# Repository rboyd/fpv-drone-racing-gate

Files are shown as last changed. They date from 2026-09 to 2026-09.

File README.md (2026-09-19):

# FPV Drone Racing Gate

A modular FPV race gate built from **1-inch PVC, five types of PETG fittings, roll paper and magnets**. Print the fittings on a Bambu A1 Mini, cut two standard pipe lengths, and assemble a single gate or a two-level Split-S obstacle.

**Current design:** three-magnet top elbows with independent front/rear guy eyes and recessed paper alignment guides. **Prototype status:** the 33.5 mm magnetic sleeve bore has been physically tested on the purchased PVC and fits well. Full-gate assembly, friction-joint retention and guy loads still need physical validation.

## Choose a gate size

The original **1480.8 mm opening** now has **1000 mm and 800 mm alternatives**, each available with **24-, 18- or 12-inch paper bands**. All use the **same five printed part types and accepted 33.5 mm bores**. Only PVC lengths, paper cuts and sleeve quantities/positions change; previously printed fittings remain usable.

**Suggested next trial: 1000 mm opening with 12-inch paper.** It needs 32 printed parts, 1.883 kg PETG and about 74 hours of printing—half the original part count, 19% less PETG and 21% less printer time. Its outside square is 1609.6 mm. The imported 7-inch MK4 drone has about 299 mm centered clearance on each side; the 800 mm opening has about 199 mm. These are geometric clearances, not flight-error allowances.

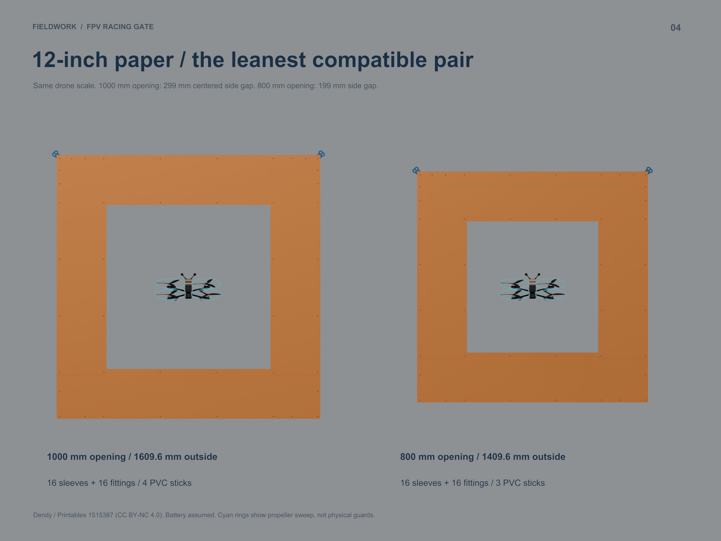
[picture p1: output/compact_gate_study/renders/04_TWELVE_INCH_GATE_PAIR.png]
1000 mm and 800 mm openings with 12-inch paper and the imported MK4 drone


| Clear square opening | Paper band | Outside square | All parts / sleeves | PETG | Estimated print time | 10-ft PVC sticks* | Priced subtotal* |
|---:|---:|---:|---:|---:|---:|---:|---:|
| 1000 mm | 24 in | 2219.2 mm | 48 / 32 | 2.104 kg | 84 h 20 min | 5 | $50.52 |
| 1000 mm | 18 in | 1914.4 mm | 40 / 24 | 1.993 kg | 79 h 18 min | 5 | $49.03 |
| 1000 mm | 12 in | 1609.6 mm | 32 / 16 | 1.883 kg | 74 h 21 min | 4 | $42.19 |
| 800 mm | 24 in | 2019.2 mm | 48 / 32 | 2.104 kg | 84 h 20 min | 5 | $50.52 |
| 800 mm | 18 in | 1714.4 mm | 40 / 24 | 1.993 kg | 79 h 18 min | 4 | $43.69 |
| 800 mm | 12 in | 1409.6 mm | 32 / 16 | 1.883 kg | 74 h 21 min | 3 | $36.85 |

*Compact-gate stock counts and subtotals above use the **ratcheting-cutter layouts**, with 10 mm cleanup reserve per stick and no saw kerf. Subtotals cover PETG consumed, magnets and whole PVC sticks at the owner's prices; paper, guys and ground supports are additional. The earlier compact study's cost table reserves 3 mm per cut for a saw, so its 1000 mm / 24-inch option uses six sticks and costs $5.34 more. Print figures are Bambu Studio estimates, not elapsed measurements.*

All compact gates retain **2 bottom elbows, 2 guy elbows, 8 tees and 4 crosses**. Their 24 / 18 / 12-inch paper layouts need **32 / 24 / 16 sleeves**, respectively. The smaller 800 mm opening uses the same print quantities at the study's maximum 350 mm magnet-gap target; paper retention at that spacing still needs physical testing. A 12-inch-paper gate fits nominally within two 1 kg spools, with about 117 g spare before failures.

- **Cut the PVC:** [printable seven-page cut guide](output/compact_gate_study/PVC_Cut_Guide.pdf), [cut tables and stick layouts](output/compact_gate_study/PVC_Cut_Guide.md), or [summary CSV](output/compact_gate_study/PVC_Cut_Summary.csv). Every compact gate needs eight long and sixteen short pieces. Listed lengths already include socket insertion.
- **See all six sizes:** [paper-on preview](output/compact_gate_study/renders/01_SIX_PAPER_LAYOUTS.png), [1000 mm frames with paper removed](output/compact_gate_study/renders/02_FRAME_1000.png), [800 mm frames](output/compact_gate_study/renders/03_FRAME_800.png), and [compact corner detail](output/compact_gate_study/renders/05_NARROW_CORNER_DETAIL.png).
- **Build a selected variant:** [full study, per-variant print queues, paper cuts and sleeve positions](output/compact_gate_study/README.md), [illustrated PDF](output/compact_gate_study/Compact_Gate_Study.pdf), or [Blender model](output/compact_gate_study/Compact_Gate_Study.blend).
- **Compare drone clearance:** [MK4 clearance study](output/drone_clearance_study/README.md) and [equal-scale opening comparison](output/drone_clearance_study/renders/04_OPENING_DETAIL.png). Drone reference: Dendy / Printables 1515387, CC BY-NC 4.0; battery dimensions assumed. See [attribution](reference/geprc_mk4/ATTRIBUTION.md).

## Original gate and stacked Split-S

The quantities and assembly tables below describe the original **1480.8 mm opening / 24-inch paper** configuration and its stacked version. Use the compact cut guide and print queue above for smaller gates. Compact stacked variants have not been laid out in this study.

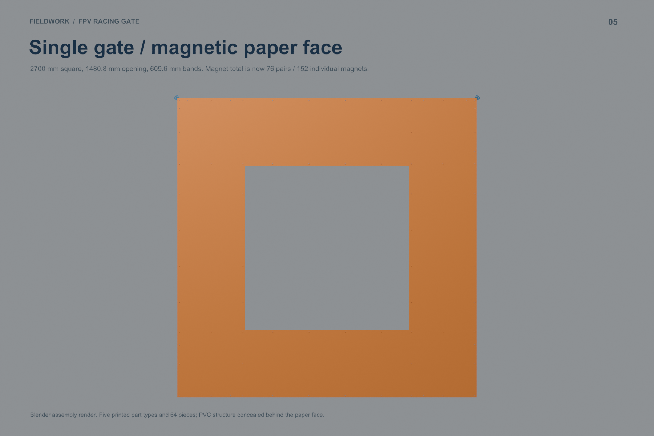
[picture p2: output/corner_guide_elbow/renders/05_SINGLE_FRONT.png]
Assembled single gate, front view rendered in Blender


*Blender assembly render—not a photograph of a completed build. Blue parts in the renders represent the black PETG used for printing. Ground anchoring and feet are not shown.*

| | Single gate | Stacked Split-S, total |
|---|---:|---:|
| Paper outline | 2700 × 2700 mm | 2700 × 4790.4 mm |
| Clear square opening | 1480.8 × 1480.8 mm | Two 1480.8 × 1480.8 mm openings |
| Paper band width | 609.6 mm / 24 in | 609.6 mm / 24 in |
| Printed parts / unique types | 64 / 5 | 104 / 5 |
| PETG, full batch queue | 2.325 kg | 3.691 kg |
| Estimated printer time | 94 h 28 min | 150 h 22 min |
| Plate runs on one A1 Mini | 23 | 36 |
| Priced materials: PETG + magnets + PVC | **$69.53** | **$117.29** |

Paper, guy lines and ground support are additional. Prices are the owner's approximate purchase costs, detailed below. The two guy ears extend about 28.6 mm beyond the adjacent paper edges.

## Files to start with

- [Compact gate material study](output/compact_gate_study/README.md): 1000 / 800 mm openings with 24 / 18 / 12-inch paper, fewer sleeves, exact print queues and material comparisons.
- [PVC cut guide for all six compact variants](output/compact_gate_study/PVC_Cut_Guide.pdf): finished lengths, quantities and stock layouts for the ratcheting cutter.
- [7-inch MK4 drone clearance study](output/drone_clearance_study/README.md): actual imported drone, Blender renders and 1480.8 / 1200 / 1000 / 800 mm opening comparisons. Smaller sizes are study variants; the production kit below retains the 1480.8 mm opening.
- [Current Blender model](output/corner_guide_elbow/Corner_Guide_Elbow.blend), including assembled gates, paper alignment, cord routing and the five-part overview.
- [Illustrated assembly and test PDF](output/corner_guide_elbow/Corner_Guide_Elbow.pdf) and [detailed current guide](output/corner_guide_elbow/README.md).
- [Printable STL parts](output/corner_guide_elbow/printable/) and [prepared A1 Mini PETG projects](output/corner_guide_elbow/sliced/).
- [Single-gate print queue](output/corner_guide_elbow/single_Print_Queue.csv), [PVC stock layout](output/corner_guide_elbow/single_PVC_Stock_Layout.csv), [paper cuts](output/corner_guide_elbow/single_Paper_Cuts.csv) and [magnet positions](output/corner_guide_elbow/single_Magnet_Positions.csv).
- [Stacked print queue](output/corner_guide_elbow/split_s_Print_Queue.csv) and [cost BOM](docs/Cost_BOM.csv).

Use **`output/corner_guide_elbow/`** for the shared fitting geometry and original gate, **`output/compact_gate_study/`** for the six smaller layouts, and **`output/drone_clearance_study/`** for drone size comparisons. Other output folders preserve earlier iterations; their quantities, interfaces and prices may differ.

## Five printed parts

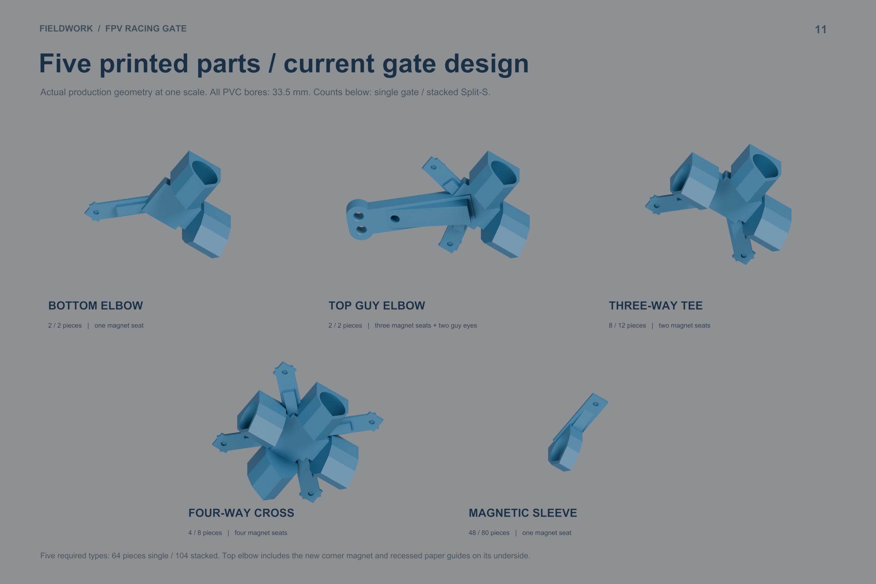
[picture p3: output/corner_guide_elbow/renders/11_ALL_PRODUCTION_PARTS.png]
Bottom elbow, top guy elbow, tee, cross and sleeve at the same scale


| Part / STL | Single qty | Stacked total qty | PETG per individual print | Individual print time | PETG cost per individual print |
|---|---:|---:|---:|---:|---:|
| [Bottom elbow](output/corner_guide_elbow/printable/ELBOW.stl) | 2 | 2 | 68.47 g | 2 h 41 min | $0.68 |
| [Top guy elbow](output/corner_guide_elbow/printable/DUAL_GUY_ELBOW.stl) | 2 | 2 | 103.06 g | 4 h 00 min | $1.02 |
| [Three-way tee](output/corner_guide_elbow/printable/TEE.stl) | 8 | 12 | 98.49 g | 3 h 46 min | $0.97 |
| [Four-way cross](output/corner_guide_elbow/printable/CROSS.stl) | 4 | 8 | 132.59 g | 5 h 04 min | $1.31 |
| [Magnetic sleeve](output/corner_guide_elbow/printable/MAG_SLEEVE.stl) | 48 | 80 | 13.88 g | 1 h 12 min | $0.14 |

Individual print estimates include each plate's overhead. The full-gate totals use **seven-sleeve batches**, which are substantially faster than printing sleeves one at a time. Values come from local Bambu Studio slices, not elapsed measurements of completed prints. Full queues start from zero; subtract parts already printed.

The bottom elbow, tee, cross and sleeve are unchanged from the accepted-bore iteration. All sockets use **33.5 mm bores** for the project's nominal 1-inch PVC (modeled OD 33.4 mm). Elbows, tees and crosses have 30 mm pipe engagement; the sleeve has 16 mm engagement. Friction retains the joints—no bolts, nuts or zip ties in this frame.

The top elbow adds two separate 10.5 mm eyes for front and rear guys, three 6 × 2 mm magnet seats, and an L-shaped paper guide recessed 0.4 mm into the face. The magnet pockets retain 0.4 mm plastic skins. Bare front magnets clamp the paper against those skins; front paper pads are optional and excluded from the required BOM.

## Material BOM and costs

These are **prices paid by the project owner**, not current store quotes or product recommendations. Exact brands/listings were not supplied.

| Material purchased | Pack price | Unit rate used |
|---|---:|---:|
| Black PETG, four 1 kg spools | $39.59 / 4 kg | $9.8975 / kg |
| Neodymium magnets, 6 mm diameter × 2 mm thick | $19.99 / 800 | $0.0249875 / magnet |
| Nominal 1-inch PVC, 10 ft / 3048 mm stick | $5.34 each | $5.34 / stick |

| Material | Single quantity | Single cost | Stacked total quantity | Stacked cost |
|---|---:|---:|---:|---:|
| PETG consumed by supplied queue | 2.32471 kg | $23.01 | 3.69130 kg | $36.53 |
| Magnets, including both sides of paper | 152 / 76 pairs | $3.80 | 240 / 120 pairs | $6.00 |
| PVC stock, including cutting waste | 8 sticks | $42.72 | 14 sticks | $74.76 |
| **Priced material subtotal** | | **$69.53** | | **$117.29** |
| 24-inch paper roll | 8.5056 m used | Unpriced | 14.3112 m used | Unpriced |
| Front/rear guys and suitable ground support | 4 guys + supports | Unpriced | 4 guys + supports | Unpriced |

These subtotals allocate only the filament and magnets used, plus all PVC sticks purchased. Starting from no supplies, buying **one 4 kg filament pack + one 800-magnet pack + the PVC** costs **$102.30 single / $134.34 stacked**, leaving filament, magnets and pipe offcuts. The stacked queue fits nominally within 4 kg, with about 309 g spare before failed prints or other additions. Tax, shipping, adhesive, electricity, optional pads, tools, failed prints, paper and ground support are excluded.

Machine-readable inputs: [material_costs.json](docs/material_costs.json). [Cost_BOM.csv](docs/Cost_BOM.csv) contains the calculated line items. Older guides retain their historical pricing assumptions.

## A1 Mini printing

Prepared projects use the **180 × 180 × 180 mm A1 Mini**, a 0.4 mm nozzle, 0.20 mm layers, four walls, 20% infill, Generic PETG, a textured PEI plate and no supports. All supplied plate layouts have at least 5 mm bed margin. The largest fitting is the top guy elbow at **168.614 × 168.614 × 53.345 mm**. Retain the supplied orientations; the socket roofs are shaped for support-free printing.

For a new printer/pipe combination, start with [one magnetic sleeve](output/corner_guide_elbow/sliced/ONE_MAG_SLEEVE/ONE_MAG_SLEEVE_A1Mini_PETG.3mf), then test [one tee](output/corner_guide_elbow/sliced/ONE_TEE/ONE_TEE_A1Mini_PETG.3mf) and [one top guy elbow](output/corner_guide_elbow/sliced/ONE_DUAL_GUY_ELBOW/ONE_DUAL_GUY_ELBOW_A1Mini_PETG.3mf). The project owner's sleeve fit is confirmed; it does not establish the longer sockets' fit on every pipe brand.

| Prepared plate | Parts / run | Single runs | Stacked total runs | PETG / run | Time / run |
|---|---:|---:|---:|---:|---:|
| [ONE_ELBOW](output/corner_guide_elbow/sliced/ONE_ELBOW/ONE_ELBOW_A1Mini_PETG.3mf) | 1 | 2 | 2 | 68.47 g | 2 h 41 min |
| [ONE_TEE](output/corner_guide_elbow/sliced/ONE_TEE/ONE_TEE_A1Mini_PETG.3mf) | 1 | 8 | 12 | 98.49 g | 3 h 46 min |
| [ONE_CROSS](output/corner_guide_elbow/sliced/ONE_CROSS/ONE_CROSS_A1Mini_PETG.3mf) | 1 | 4 | 8 | 132.59 g | 5 h 04 min |
| [ONE_DUAL_GUY_ELBOW](output/corner_guide_elbow/sliced/ONE_DUAL_GUY_ELBOW/ONE_DUAL_GUY_ELBOW_A1Mini_PETG.3mf) | 1 | 2 | 2 | 103.06 g | 4 h 00 min |
| [BATCH_MAG_SLEEVE](output/corner_guide_elbow/sliced/BATCH_MAG_SLEEVE/BATCH_MAG_SLEEVE_A1Mini_PETG.3mf) | 7 | 6 | 11 | 96.74 g | 4 h 28 min |
| [TAIL_MAG_SLEEVE_6](output/corner_guide_elbow/sliced/TAIL_MAG_SLEEVE_6/TAIL_MAG_SLEEVE_6_A1Mini_PETG.3mf) | 6 | 1 | 0 | 82.93 g | 3 h 51 min |
| [TAIL_MAG_SLEEVE_3](output/corner_guide_elbow/sliced/TAIL_MAG_SLEEVE_3/TAIL_MAG_SLEEVE_3_A1Mini_PETG.3mf) | 3 | 0 | 1 | 41.50 g | 2 h 04 min |

The single queue is about **94.5 printer-hours**, and the stacked queue about **150.4 printer-hours**, before plate changes, setup and downtime. Slicer estimates depend on the selected machine, filament and process settings.

## PVC cuts and assembly

| PVC cut length | Single qty | Stacked total qty |
|---|---:|---:|
| 389.6 mm | 16 | 24 |
| 1560.8 mm | 8 | 14 |

The [single](output/corner_guide_elbow/single_PVC_Stock_Layout.csv) and [stacked](output/corner_guide_elbow/split_s_PVC_Stock_Layout.csv) stock layouts reserve 3 mm per cut and 10 mm per stick for trimming. The workshop cutter is a **Husky 1-1/4-inch ratcheting PVC cutter**; hand-saw cuts are also accommodated by the allowance. Mark and verify one master piece of each length before using it for repeated marking. Square and deburr the cuts; mark 30 mm socket insertion depth.

1. Slide the magnetic sleeves onto each pipe **before** inserting both pipe ends into fittings. Use the [sleeve-position CSV](output/corner_guide_elbow/single_Sleeve_Positions.csv) to set their positions and clock the magnet faces into the paper plane.
2. Build horizontal rows with four fittings and short / long / short pipes. The bottom corners use plain elbows; top corners use guy elbows; perimeter junctions use tees; interior junctions use crosses. The [assembly map](output/corner_guide_elbow/single_Assembly_Map.svg) and [node list](output/corner_guide_elbow/single_Nodes.csv) identify every location and rotation.
3. Join the rows with vertical pipes while working flat. Seat the sockets to the witness marks and check equal diagonals and coplanarity.
4. Install backing magnets at the listed paper attachment positions, checking polarity before bonding. Some tee/cross pockets are unused in a given orientation; **populate the magnet-position list, not every physical pocket**.
5. Cut 24-inch-wide paper into two 2700 mm horizontal bands and two 1552.8 mm side inserts for the single gate. Side inserts overlap the horizontal bands by 36 mm at each end. The stacked version uses three horizontal bands and four side inserts. A 100-ft roll yields three singles or two stacked paper sets, before spoilage.
6. At each top elbow, align the paper edges with the **centerlines** of the recessed L. Place the corner magnet first, then the top/side magnets and remaining edge magnets. Paper is held as rear magnet → plastic skin → paper → front magnet.
7. Attach separate front and rear guys at each upper corner. Fit and test suitable stakes for soil or ballast/base supports for hard surfaces before flight. The current frame kit does not specify a complete footing or anchor design, and no wind/load rating is assigned. Paper is a replaceable face; wet-weather durability has not been established.

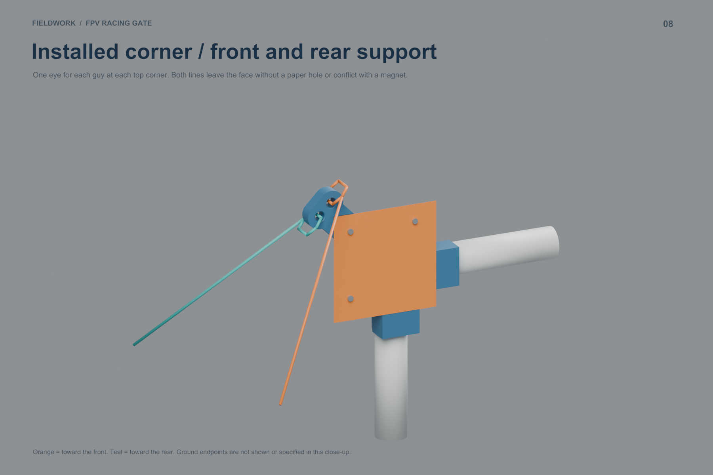
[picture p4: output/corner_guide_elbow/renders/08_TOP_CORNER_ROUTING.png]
Top corner with three magnets and separate front/rear guy attachments


## Extend to a two-level Split-S

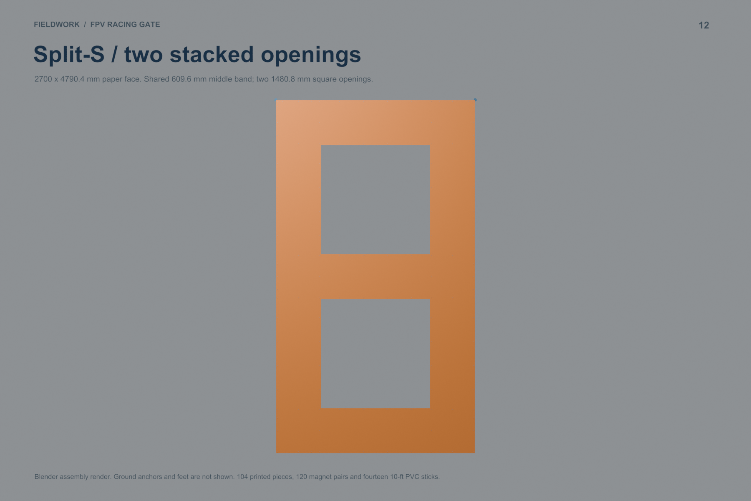
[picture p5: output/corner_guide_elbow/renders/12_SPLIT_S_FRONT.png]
Assembled two-level Split-S paper face rendered in Blender


Move the complete top row upward, reusing its guy elbows, tees, sleeves and magnets. Add **4 tees, 4 crosses, 32 sleeves, 8 short pipes, 6 long pipes and 44 magnet pairs**. The added PVC fits six more 10-ft sticks. Add one horizontal paper band and two side inserts. All existing gate parts and pipe cuts are reused; stacked totals above include the original gate.

The finished paper outline is **2.70 m wide × 4.7904 m tall**, before any feet. This is a tall obstacle, and its supports must be tested for the actual installation.

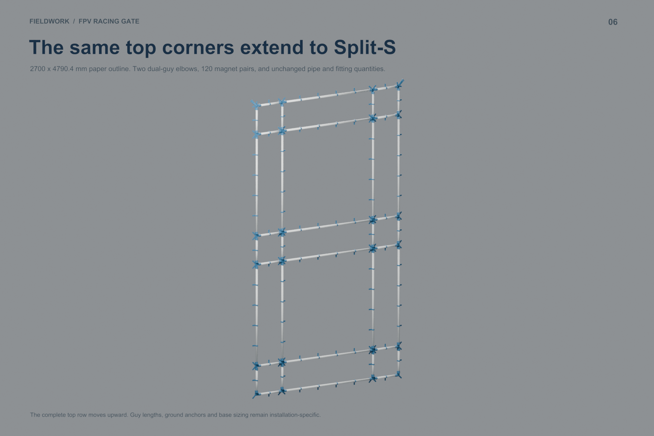
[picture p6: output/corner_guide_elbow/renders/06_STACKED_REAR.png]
Rear PVC structure of the stacked gate


## What is verified

- Actual printed magnetic sleeve: good friction fit on the purchased PVC at a 33.5 mm design bore.
- Digital geometry: connected manifold STL meshes, A1 Mini bounds and plate clearances, aligned magnet pockets, paper-guide depth, cord routing clearance and matching PVC ports.
- Slicing: every supplied recipe generates with supports off and no slicer warnings.
- Assembly accounting: part counts, full print queues, pipe stock nesting, paper positions and reuse when extending to Split-S.

Physical elbow/tee/cross fit, magnet retention, full-frame stiffness, guy-eye strength and outdoor performance remain prototype tests. The images are CAD renders of the current design.

## Rebuild and repository layout

The checked-in Blender scenes, STLs, 3MF projects, PDFs and CSVs are ready to inspect. Geometry is authored in millimetres and converted to metres in Blender; exported STLs/3MFs use millimetres.

```sh
# Blender 5.0.1 was used locally; --no-render builds geometry and scenes only.
blender -b -t 8 --python scripts/build_corner_guide_elbow.py -- --no-render

# Slice with the locally installed Bambu Studio and its A1 Mini presets.
python3 scripts/slice_corner_guide_elbow.py
python3 scripts/validate_corner_guide_elbow.py

# Render the full scene set (omit --no-render).
blender -b -t 8 --python scripts/build_corner_guide_elbow.py

# Documentation packaging requires ReportLab.
python3 -m pip install reportlab
python3 scripts/package_corner_guide_elbow.py
python3 scripts/publish_project_docs.py
```

Scripts currently target **macOS**: the Blender helpers use system Arial fonts and the slicer wrapper uses `/Applications/BambuStudio.app`. Adapt those paths for other operating systems. `RENDER_SCENES` can restrict rendering to a comma-separated scene list. PDFs embed rendered images, so render before packaging.

- `output/corner_guide_elbow/`: current gate, five production types and print queues.
- `output/compact_gate_study/`: six smaller layouts, PVC cut guide, partial sleeve batches and previews.
- `output/drone_clearance_study/`: imported MK4 drone, opening comparisons and Blender crossing animation.
- `scripts/`: reproducible geometry, slicing, validation and packaging.
- `docs/`: current material prices and cost ledger.
- [DESIGN_HISTORY.md](DESIGN_HISTORY.md): earlier Coroplast, posterboard, click-track and PVC iterations.
- `reference/` and `WIP-design.md`: design references; they are not current fabrication instructions.

Generated loose G-code, logs, Blender backup files and duplicate kit ZIPs are excluded from Git. Sliced 3MF projects are included; the packaging script can regenerate the current ZIP locally.

## License

**Designs and documentation: [CC BY-NC-SA 4.0](LICENSE).** Share and modify for noncommercial purposes, give attribution, identify changes and keep shared adaptations under the same license or a compatible license permitted by its terms. Commercial use of protected project material requires separate permission from [Robert Boyd (@rboyd)](https://github.com/rboyd).

**Original Python scripts: [PolyForm Noncommercial 1.0.0](scripts/LICENSE).** Use, modification and sharing are allowed for its permitted purposes; retain the [required notices](scripts/NOTICE). Generated design assets keep their separate CC license.

Ownership is retained, and separate commercial licenses may be granted. Existing compliant CC permissions cannot be revoked. See [LICENSING.md](LICENSING.md) for exact scope, retained rights, commercial requests and the limits of protection for functional designs.

The archived Tony Youngblood picture-frame reference retains **CC BY-SA 4.0**, including its commercial permissions; see [attribution](reference/picture_frame/ATTRIBUTION.md). The imported Dendy / Printables MK4 drone reference retains **CC BY-NC 4.0**, with the original frame authorship qualification; see [drone attribution](reference/geprc_mk4/ATTRIBUTION.md). Fonts, presets and other third-party content retain their own terms. The project's noncommercial licenses do not relicense those components.

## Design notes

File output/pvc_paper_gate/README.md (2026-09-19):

# PVC-dominant paper gate / single and Split-S

The previous reinforced print-track design and first click-test plate were committed as **eda5b20**. This new iteration replaces the printed track with **one outer PVC perimeter and one PVC ring around each opening**, joined by four diagonal PVC spokes at the overall corners. All pipe is nominal 1-inch PVC (33.4 mm OD). Paper hides the structure head-on; only paper and bare front magnets are visible in the face area.

[Blender model](PVC_Paper_Gate.blend) · [Visual design/assembly PDF](PVC_Gate_Study.pdf) · [Rendered single gate](renders/01_SINGLE_FRONT.png) · [Rendered Split-S](renders/03_SPLIT_S_FRONT.png) · [Rear structure](renders/04_SPLIT_S_BACK.png) · [Kit](PVC_Paper_Gate_Kit.zip)

## Recommendation and measured cost

Use the **stack-ready single** as the development baseline: **62 printed pieces in five types, 1.759 kg PETG, 71.0 print-hours, 16 plate runs, and six 10-ft PVC lengths at your $6 price**. The longest cut pipe is 1990.4 mm, retaining the approximately 2.15 m transport limit. Short members disconnect at cord-retained sockets.

| Configuration | Printed pieces | PETG | Print time | PVC sticks / cost | PVC + PETG subtotal* |
|---|---:|---:|---:|---:|---:|
| Basic single; 2.5 m pipes | 64 | 1.370 kg | 56.6 h | 7 / $42 | $69.40 |
| Recommended single; ready to extend | 62 | 1.759 kg | 71.0 h | 6 / $36 | $71.17 |
| Two-level Split-S | 108 | 2.814 kg | 114.5 h | 10 / $60 | $116.27 |

*PETG cost assumes $20/kg, not a current supplier quote. Estimates are actual local A1 Mini slices: 0.4 mm nozzle, 0.20 mm layers, four walls, 20% infill, Generic PETG, supports off. The subtotal covers the **face skeleton only**. Add magnets, paper, cord, adhesive, base/feet, ground stakes or ballast, and external guys. It is not a complete installed-obstacle price. Manual work, failures and reprints are excluded from printer-hours.

Two full 1 kg spools cover the recommended single with 10% allowance (1.935 kg). The Split-S uses 2.814 kg before allowance: three spools nominally, four if budgeting 10% extra. Optional front pads add material and time; they are excluded from these totals.

For a fair printed-face comparison, the prior sleeve design excluding optional pads and PVC-brace clamps used 6.132 kg / 252.4 hours. The new recommended single reduces that PETG by 71.3% and print time by 71.9%. The tradeoff is more PVC and cord work. The no-transport-joints basic option prints less, but needs seven sticks due to offcuts and has 2500 mm pipe pieces. The recommended version costs only $1.77 more in the modeled materials.

## Five printed types

| Part | Single ready | Split-S total | A1 Mini print bounds mm |
|---|---:|---:|---|
| OUTER_90_45 | 4 | 4 | 122.0 x 122.0 x 53.84 |
| STACK_TEE | 4 | 10 | 160.0 x 122.0 x 53.84 |
| EDGE_SLEEVE | 42 | 74 | 20.0 x 62.3 x 52.709 |
| INNER_90_45 | 4 | 4 | 151.489 x 151.488 x 53.84 |
| CORD_SADDLE | 8 | 16 | 34.0 x 20.0 x 12.0 |

**OUTER_90_45** combines two perpendicular sockets and an inward diagonal socket. **INNER_90_45** has the same perpendicular sockets but its diagonal points outward, away from the opening. They cannot be the same rotated part. Each has an integral magnet pocket, broad 32 x 12 mm connecting webs, raised cord eyes, and a two-horn cord cleat. Socket walls are nominally 4 mm, with 30 mm pipe engagement to a positive end stop.

**STACK_TEE** is used in all ten tee locations of the stacked gate: eight divider junctions and two transport joints. It has four available magnet pads so the same part can rotate to either side; populate only the pockets listed in the magnet map. Its unused branch port at a transport joint stays empty and concealed behind paper. The single version includes four tees: two side riser tees for the future divider and two horizontal transport tees.

**EDGE_SLEEVE** slides over bare PVC before fitting the ends. Its 3.2 mm nominal wall and 14 mm axial length support a magnetic pad offset 32 mm from the pipe axis. Use the raised cord eye to set rotation and the indexed cord/stop knots to set position. It is a clearance sleeve, not a friction clamp. **CORD_SADDLE** is a small magnet backing threaded on a seam cord; two span each short paper overlap without an extra PVC member.

Every production part is a connected, manifold mesh and fits inside the A1 Mini's 180 mm cube with the supplied placement margin. Maximum part extent is 160 mm. The pipe axes are only **24 mm behind the paper**, reducing solid material below the sockets. Accepted peaked roofs remain. The magnet pocket remains **6.3 mm diameter with 0.4 mm of plastic between rear magnet and paper**; it is not a flush/open frame-side holder.

## Paper face and magnet alignment

Outside dimensions remain **2700 x 2700 mm** for one opening, or **2700 x 4790.4 mm** for two. Each clear paper opening is **1480.8 x 1480.8 mm**. The shared divider is one 609.6 mm band, not two overlapping full bands. With the illustrative 50 mm ground clearance, the Split-S top is 4840.4 mm above ground.

Use the full 609.6 mm roll width throughout. This iteration changes the pinwheel cutting pattern to simpler horizontal bars and side inserts that also work at the shared divider:

- Single: **two 2700 mm cuts and two 1552.8 mm cuts**. The side inserts overlap the horizontal bands by 36 mm at both ends. Total roll consumption 8.5056 m; three single gates fit on a 100-ft roll.
- Split-S: **three 2700 mm cuts and four 1552.8 mm cuts**. Total 14.3112 m; two stacked gates fit on a 100-ft roll.

The outer PVC axes are 50 mm inside the paper outline. The inner axes sit 50 mm behind the opening boundary in plan. A 32 mm pad offset puts magnets **18 mm inside the paper edges**, and the overlap seam centers are also 18 mm from the side-insert cut ends. No pipe or printed fitting protrudes into the opening or beyond the face in the checked front projection. This is a head-on appearance goal; supports may be visible from oblique/rear views, and paper can deflect in wind.

Use **124 magnets for the single, 216 for the Split-S**, all 6 x 2 mm, paired front/back. Start with the spacing shown (roughly 300-350 mm on long edges); it is a prototype spacing, not established wind retention. The smaller count than the printed-rail design needs physical paper/grip testing.

Bond the rear magnets with compatible adhesive after checking polarity. Stack without optional pads: **rear magnet -> 0.4 mm printed skin -> paper -> bare front magnet**. Optional PAPER_PAD adds its own 0.4 mm skin and a handle around the front magnet. It is a test/comfort option, not required for the paper-only front appearance. No new front pad design is needed.

For accurate placement, use Sleeve_Positions.csv to mark the PVC, rotate each sleeve until its paper face is coplanar with the corner pads, and lock that position on the prethreaded cord with stopper knots on both sides of its eye. Set the paper edge 18 mm beyond the magnet centers. Attach loose front magnets directly over the fixed rear magnets; they self-align. Do not perforate the paper. The Paper_and_Magnet_Map.svg and Magnet_Positions.csv provide the exact layout; the SVG shows magnets at true scale.

## Cord assembly and retention

Use the previously selected **2.4 mm 275 paracord**. Socket draw lines run from fitting to fitting along each PVC member, through the relevant sleeve eyes on straight members. Keep the line on the paper-edge side of the pipe foot, clear of the socket mouth. They pull the fittings against the pipe end stops; bare dry-fit friction is not treated as retention. Wrap diagonal draw cords **over the backs of the socket shells**, then finish on the central cleats, so they do not pass through a solid socket root.

Tie one fixed end, feed slack through the guides, hold the final tail, and pull only enough to seat both pipe ends. Make two figure-eight wraps around the receiving two-horn cleat and finish with a locking half-hitch. Leave a 100 mm tail. To release, hold the tail, undo the hitch and unwrap. Do not tension until PVC bows. Use separate lines for the seam backers and X braces so replacing paper does not loosen pipe joints. The X cords stay inside the side paper bands and never cross an opening.

The supplied centerline drawings show principal routes and raised eye locations; knots, contact bends around the sockets, and every turn through an eye are not simulated. Prototype the routing and hand access before repeating it. The cord scheme has not been load tested. Printed sleeve rotation, cord stretch and knot slip remain physical-test items. Mark socket insertion depth, sleeve position and cord tail after the first successful fit-up; leave sleeves and their locating cords on the pipes in transport.

Cord_Cuts.csv includes generous tie allowances: **38.7 m for the single face, 67.2 m for the stacked face**. External guys are additional. These are cut allowances, not a reason to tension hard. Recheck slack after settling and warm exposure.

## Single gate assembly

1. Print the FIRST_FIT plate and test the actual pipe first. Once it passes, print one INNER_90_45 and one STACK_TEE before committing to the full queue. Neither is included in FIRST_FIT.
2. Cut and label PVC from the stock layout. The six-stick single layout reserves 10 mm per stock end allowance and 3 mm kerf per cut, but several sticks have only about 8.3 mm remaining after those allowances. Measure actual stock and kerf before cutting; do not round all cuts upward. Cuts use **center spacing minus 100 mm** because every fitting's pipe stop is 50 mm from its node center.
3. Slide the indicated EDGE_SLEEVEs onto each labeled bare pipe. Use Sleeve_Positions.csv, measured from the cut start named in PVC_Cuts.csv. Thread the locating cords before fitting the pipe ends. Keep every flat paper face in the same plane.
4. Assemble the outer ring on a flat surface. The top and bottom each use two 1200 mm pipes and one tee transport joint. Each side uses a 1990.4 mm pipe, a tee and a 409.6 mm pipe. The tee's spare port points inward. Outer corner-to-corner pipe-axis spacing is 2600 mm.
5. Assemble the inner square from four 1480.8 mm pipes. Its pipe-axis spacing is 1580.8 mm. Connect corresponding corners with four 620.683 mm diagonal pipes. Lay all corners in the orientations shown in Blender before inserting the diagonals.
6. Seat all pipes 30 mm into their sockets. Tension the socket draw cords gradually, check squareness, then set the side-band X cords. Fit the seam cords and slide on two CORD_SADDLEs per seam. Fix their marked positions with small stopper knots.
7. Install rear magnets and allow adhesive to cure. Lay on the two horizontal paper bands, then the side inserts with their 36 mm overlaps. Work from corners along each edge, adding front magnets directly over the rear pockets. Confirm only paper and magnets show from the front.
8. Test retention and handling flat, then install a suitable base and anchoring system before standing the gate. Do not lift or carry the assembly by paper or magnetic pads.

## Upgrade to a two-level Split-S

The digital cut ledger confirms **every existing pipe length is reused without cutting**. Add **six STACK_TEEs, 32 EDGE_SLEEVEs and eight CORD_SADDLEs**. Add PVC cuts: **two 1990.4 mm, four 1480.8 mm and four 409.6 mm**. Those additions fit four more 10-ft sticks, bringing the total to ten. Add 92 magnets, additional cord, one 2700 mm paper band and two 1552.8 mm side inserts.

With the single gate lying flat, remove its paper and slacken the draw cords. Move the entire outer top bar (including its middle tee), its two outer corner fittings, the inner top corner fittings and the two top diagonal pipes to their new top positions. Keep the original inner top 1480.8 mm pipe as the lower divider-opening rail, replacing its two corner fittings with tees. The old upper outer corners become new tees at the upper divider height. The preinstalled side tees form the lower divider junctions.

Connect each divider rail outward to the side uprights with two 409.6 mm stubs. Retain the original two short side risers between the divider's outer tees. Add the upper outer risers, the upper opening's two inner uprights, and its bottom/top horizontal rails. Check the two divider axis heights: **2140.4 and 2650 mm measured from the paper bottom**, a 509.6 mm spacing. This leaves room for the one 609.6 mm paper divider while the sleeves place magnets at its two opening edges.

Re-thread and tension with the assembly flat; then add the additional paper and magnets. The shared middle uses straight tee connections, so there are no crossing in-plane PVC diagonals. The extra tee ports and aligned pipe stops are what make this a reusable extension system rather than two independent square gates stacked into each other.

## First print and acceptance checks

[Open FIRST_FIT_A1Mini_PETG.3mf](sliced/FIRST_FIT/FIRST_FIT_A1Mini_PETG.3mf): **124.59 g, 4.95 hours**, five pieces: one outer 90+45 corner, one edge sleeve, one cord saddle, one short bore gauge, and one optional front pad. It demonstrates the new PVC socket, magnetic face and cord interface; the earlier click-test plate remains available in the committed iteration.

Use actual clean 33.4 mm OD PVC offcuts, a short paracord length, paper and four magnets for two grip sites. Check the gauge first, then full 30 mm socket seating without force; a short gauge does not prove the full socket fit. Check extraction after relaxing cord, loop clocking, knots, cord access around the 45-degree socket and coplanar magnet faces. Test bare front magnet vs optional pad, then repeat assembly at least 20 times. Check whitening, cracks, looseness, pipe withdrawal and permanent deformation. Scale must stay 100%; revise the bore clearance itself if necessary.

All seven exported masters (five production types, a gauge and an optional pad) are connected/manifold and within A1 Mini bounds. All supplied recipes have 5 mm minimum bed margin, no part overlap, no supports and no slicer warnings. Quantities match the modeled parts, magnet positions match real pockets, and sleeves sit on exposed pipe rather than over a fitting. These are digital checks, not physical strength or fatigue certification.

## Base and outdoor limits

The new face skeleton is a **fabrication prototype and assembly study**, not a wind-qualified complete obstacle. Scene 10 shows the required concept of separate feet/ballast and four external guys; the bag sizes and feet are placeholders and are **not** a ballast prescription. For soil use suitable anchored guys/feet; hard surfaces require attached ballast/feet sized for the actual setup. The 4.79 m face is much taller than the single version, so do not reuse the old single-gate ballast amount as an assumed rating. Keep anchors/guys outside the openings, attach them around structural PVC near nodes, and assemble/raise with helpers.

Ground hardware is deliberately excluded from the face cost/queue. Its sizing and attachment are the next engineering step after the corner/cord prototype works. Paper weather resistance, 6 mm magnet pull through the plastic skin, sleeve clocking and cord preload also remain to be proven in real conditions. A paper face at this size can catch wind even if the PVC joints are rigid.

## Sources and assumptions

- [FORMUFIT PVC sizing](https://formufit.com/pages/pvc-101): nominal 1-inch PVC is approximately 1.315 inch OD. The CAD uses 33.4 mm and a 34.2 mm trial bore; measure your pipe rather than treating that clearance as universal.
- [FORMUFIT assembly guidance](https://formufit.com/pages/building-projects-with-pvc-pipe): dry friction joints are a temporary assembly method, not adequate justification for a loaded structure. Our removable cord retention is an original prototype proposal and is not endorsed or validated by that guidance. PVC solvent cement is not assumed to bond PETG.
- [Prusa modeling guidance](https://help.prusa3d.com/article/modeling-with-3d-printing-in-mind_164135): supports/overhangs and tolerances depend on geometry and settings. Peaked bores were also checked by slicing with supports off; successful real printing is still to be tested.

Your PVC price is used as given. No MultiGP compliance or official course dimensions are claimed; the approved dimensions and reference image determine this concept. Rebuild with build_pvc_paper_gate.py, slice_pvc_paper_gate.py, validate_pvc_paper_gate.py and package_pvc_paper_gate.py. No printer job has been submitted.

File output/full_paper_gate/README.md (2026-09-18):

# Reinforced paper gate — full design and fabrication prototype

The old demo was committed as `bb96e74`. This iteration replaces its weak perpendicular socket, retains the shared click key, adds integrated paracord cleats, and carries actual printable parts through to a complete PVC-backed gate. The prior DEMO_EDGE is superseded for this construction. This is a digitally checked fabrication prototype, not a physically proven gate or a wind-rated structure.

Open [Blender](Full_Paper_Gate.blend), [assembly PDF](Full_Gate_Assembly.pdf), or [visual guide](index.html). The primary render is [fully assembled](renders/01_ASSEMBLED_FRONT.png); the [rear view](renders/02_REAR_STRUCTURE.png) exposes the structure.

## Decision and cost

The complete reinforced design needs **7.13 kg PETG, 295.0 printer-hours, 112 manual plate runs, 624 pieces and 10 unique printed types**. These are actual local Bambu Studio estimates, not solid-volume guesses. At a planning price of $20/kg, deposited PETG costs about $143; buying eight 1 kg spools is $160. A 10% allowance gives 7.84 kg, so eight spools are appropriate. One or two spools cannot make this design. Shipping, electricity, paper, magnets, PVC and hardware are additional.

This is a large printing commitment. The reinforced frame is not yet a compelling low-cost gate compared with a simpler PVC/Coroplast construction. The value of this iteration is a complete, inspectable load path and reusable test parts. Print the first bay before buying all gate materials. Keep optimization separate from an unproven reduction in the material around the sockets. At 12 printing hours/day the production queue alone takes about 25 days, plus plate handling/retries; continuous time is about 12.3 days.

The selected profile is A1 Mini, 0.4 mm nozzle, 0.20 mm layers, Generic PETG, textured PEI, **4 walls / 20% infill / supports off / no brim**. All 21 supplied plate recipes sliced without warnings. Every mesh and plate fits 180 x 180 x 180 mm with at least 5 mm XY plate margin. Largest individual height is 37 mm. Ordinary flat plates are the production baseline. The earlier diagonal sacrificial stacks remain experiments; their separation and joint preservation have not been validated, so their overnight counts are not used in these estimates.

## What changed at the weak junction

The old cross socket left a nominal 4 x 5 mm neck. The new branch socket projects inward, with its rear pocket ending at local Y=28 mm; the continuous spine spans Y=-8..8 mm and is 12 mm deep. End receiver pads are 8 mm deep and 40 mm wide. A wide triangular root distributes the branch load. The 16 x 12 mm geometric section is not a tested strength multiplier. The replaceable key remains a deliberately small, physically unverified flexure; repeated click and load tests still matter.

Two raised cord-eye posts form a permanent two-horn cleat on every branch rail. Their 45-degree expanding caps and diamond through-holes are designed for support-free printing. Smooth the cord-contact edges. The updated holes accept 2.4 mm cord; this version is not specified for ordinary 4 mm 550 paracord.

## Printed bill of materials

| Part | Gate quantity | Print bounds mm |
|---|---:|---|
| EDGE_PLAIN | 64 | 136.314 × 49.95 × 12.0 |
| EDGE_BRANCH | 48 | 136.314 × 76.0 × 29.0 |
| RUNG | 72 | 133.867 × 49.95 × 12.0 |
| CLICK_KEY | 200 | 66.0 × 32.0 × 5.0 |
| PAPER_PAD | 136 | 24.0 × 24.0 × 3.0 |
| PVC_HALF_33 | 32 | 65.8 × 31.5 × 12.0 |
| DOCK_SOCKET | 16 | 48.0 × 40.0 × 8.0 |
| DOCK_TONGUE | 16 | 46.0 × 32.0 × 37.0 |
| V_BLOCK | 32 | 24.0 × 64.0 × 22.0 |
| CROSS_PLATE | 8 | 70.0 × 70.0 × 6.0 |

Per border: 16 EDGE_PLAIN, 12 EDGE_BRANCH, 18 RUNG, 50 CLICK_KEY, 34 PAPER_PAD, 8 PVC_HALF_33, 4 DOCK_SOCKET, 4 DOCK_TONGUE = 146 pieces. Four borders = 584. Eight brace crossings add 32 V_BLOCK and 8 CROSS_PLATE = 40. Total 624. Empty magnet pockets on outer rung segments are intentional: one universal RUNG replaces extra part variants. Populate only the six middle-rung pockets per border.

## Print a test first

1. **T01_BRANCH once:** one reinforced branch, two click keys and one pad. Check both end and side sockets. Pull through the chosen cord, wrap the cleat and check release. The previous 0.40 mm fit coupon and magnet gauge remain useful, but this receiver has taller walls.
2. **A full-width I-shaped member:** T01 twice plus T02 once gives two branches, three rungs, four keys and two pads (11 pieces). The three rungs and four exposed 14 mm key middles join the two branches across a true 609.6 mm paper width.
3. **One X-braced bay:** T01 four times, T02 twice and T05 twice = 32 pieces: four branch rails, two plain rails, six rungs, twelve keys and eight pads. This is 436.943 x 609.6 mm. Add sixteen magnets, a 609.6 x 436.943 mm paper rectangle and one 3.3 m cord.
4. **Add a PVC dock:** T03 once adds two collar halves, one receiver and one tongue (36 total printed pieces). Add four M3 x 25 cap/pan bolts, two M3 x 25 flat-head bolts, six nuts and ten washers; use a 33.4 mm OD PVC offcut. Test-bay plus dock: 426.7 g, 18.79 h, nine plate runs.
5. **Test a corner brace:** T04 once supplies four V blocks and one crossing plate. Add two M4 x 80 and two M4 x 70 bolts, four nuts, eight washers, main/brace pipe offcuts. Try both +/-45 hole pairs.
6. Build one complete 2090.4 mm border only after the bay and dock behave well. Then finish the other three borders and the backbone. Test parts are production parts and can be reused. Full production queue quantities are gross: subtract accepted test pieces from it; do not print both queues blindly.

## Cord choice, threading and tightening

Use 2.4 mm 275 paracord as the handling-oriented prototype choice. Micro cord (about 1.18 mm) or braided polyester kite line is the lighter option. Supplier fiber recipes vary; 'paracord' is not a precise stretch specification. A line's advertised breaking load is not a working load for our printed cleat. The thicker cord makes threading and gripping easier, but knots and wraps consume more length than the earlier kite-line estimate.

Cut **twenty identical 3.3 m lengths** for the face and **four 4 m lengths** for the guys. Total 82 m; three 100-ft hanks provide 91.44 m. Face alone uses 66 m; calculated routes plus 600 mm knot/wrap allowance would use 63 m, but uniform 3.3 m cuts reduce assembly mistakes. Use a 3.3 m measuring mark on the bench, cut all twenty, and finish ends as appropriate for the purchased material. Do not cut only the visible diagonals.

Each bay uses one continuous cord and one tensioning station. Viewed from the rear with its long dimension horizontal, label its eyes LL (lower left), UR (upper right), LR (lower right), UL (upper left). Use the inward-facing post on each branch: the right post at the left end of the bay and the left post at the right end.

- Tie a double-overhand stopper larger than the eye at the starting end. Thread LL -> UR -> LR -> UL -> LL. This makes two crossing diagonals and two short return legs along the bay ends. At LL the two strands share the eye; keep them side-by-side. Leave the other end as the adjustment tail. For thinner kite/micro line, a stopper may pull through: use an appropriately sized backing washer or tie a fixed anchor loop around the post, then verify the anchor under load.
- Thread through the transverse holes, then turn outside the post; do not drag the line over the magnet pocket or across an exposed click hook. At the X crossing let one cord rest over the other, without a knot. Both cords remain behind the paper.
- Lay the border flat. Measure its two overall diagonals; make them equal before tensioning. Hand-feed slack through all four eyes, beginning at the stopper, then pull the tail. Friction at the bends means simply pulling hard on the last end does not tension every span evenly.
- Hold the tail with one hand. With the other, make two figure-eight turns around the two posts of the lower-left branch rail. Finish with a locking half-hitch around the last post: take the tail around the post, pass it under its own turn and snug it. Leave at least 100 mm tail, tucked under a wrap. The posts are the tensioning fixture; no separate screw, ratchet or loose part is required.
- Use only enough tension to remove slack. Stop if the rail bows or click gaps close unevenly. To adjust, hold the tail, lift off the half-hitch, unwrap, feed slack around the bay, and rewrap. Keep cords installed and lightly tensioned during transport.

There are five independent adjustments per border, twenty per gate. Independence prevents one long, friction-loaded lace from being difficult to balance. It also confines a slipped cord to one bay. Four purchased mini guy-line tensioners can simplify external setup; their cord range must include 2.4 mm. They are separate from the integral face cleats.

## Bench acceptance before scaling

Use the actual printer, PETG, magnets, paper and cord. Smooth burrs rather than enlarging latch shoulders. Seat the rigid guide runners and verify both catches; pinch both spring tips to release straight. Cycle representative joints 50 times, checking for whitening, cracks, missing hooks and growing play. A warning-free slice does not prove snap life or strength.

For a cleat check, hang about 0.5 kg from a cord test tail, secure the wraps, mark the cord at the eye, and observe for 30 minutes and again after an overnight hold. Test ten releases/re-tensions. Reject visible sliding, groove damage, fraying or a bent post. On the full bay, apply modest diagonal hand loads in both directions; joints must remain seated and the rectangle must return square. This is a fit/slip screen, not a structural load certification. Recheck after warm outdoor exposure because PETG and cord can relax.

Check the dock on real pipe for axial sliding and rotation before it supports a border. The collar has 0.4 mm diametral clearance and an ear gap for clamping. Tighten evenly with washers, without crushing the plastic. Verify the brace V clamps grip both ODs. If either clamp slips before adequate grip is obtained, revise its seat/liner and repeat the test rather than overtightening.

Test magnet polarity before bonding. Rear magnet -> 0.4 mm rail skin -> paper -> 0.4 mm pad skin -> front magnet. Magnetic attraction depends on that complete gap and coating; 6 x 2 mm dimensions alone do not specify holding force. Test peeling, sideways slip, a fan and repeated pad removal. The paper is replaceable and can tear or soften when wet; it is not a structural brace.

## Assemble each full border on the bench

Make two 2090.4 mm long edges. Each uses fourteen 136.314 mm rail bodies and thirteen keys, whose exposed central spacers are 14 mm. At zero-based positions 0, 2, 5, 8, 11, 13 use EDGE_BRANCH; all other positions use EDGE_PLAIN. Turn the second long edge 180 degrees so all branches and D lugs face inward. The symmetric index pattern keeps the six branch axes aligned.

Join three identical 133.867 mm RUNG pieces for each of six crossmembers. Use four keys per crossmember: two internal and one at each end. Crossmember axes are 68.157, 368.786, 819.729, 1270.671, 1721.614 and 2022.243 mm from the panel end. Seat the second long edge evenly across all six members. Check overall dimensions 2090.4 x 609.6 mm and equal diagonals. Thread/tension the five X bays as above.

At the middle segment of crossmembers 2, 3, 4 and 5, attach a DOCK_TONGUE with two M3 x 25 flat-head screws through the paper face, flush in the countersinks. Nuts and washers sit behind the tongue flange. The outer two crossmembers have no dock. Keep all open latches accessible from the back.

Load 28 rear magnets into the long-edge D lugs and six into the middle-rung D lugs. Leave the twelve outer-rung pockets empty. Bond 34 matching magnets into 34 front pads. Cut one 2090.4 mm strip from the full 609.6 mm roll width, lay it against the smooth flat face and apply the pads without stretching the paper. Repeat for four identical borders. Magnets and cord stay with each transport border.

## PVC backbone and cut list

One square has 2090.4 mm centerline spacing. It lies about 98.9 mm behind the paper; four 3/4-inch corner braces lie another 60.475 mm behind it. Its lower centerline is 354.8 mm above ground and upper centerline 2445.2 mm. Paper bottom is 50 mm, top 2750 mm. Two guy masts extend the PVC to 3100 mm, so front guys clear the paper's upper edge. Masts are extensions of the single backing frame, not a second square.

Use 1-inch Schedule 40 PVC (33.4 mm OD), 3/4-inch braces (26.67 mm OD), four main-corner tees and two foot tees. Printed collars require these outside diameters, not 1-inch-OD tubing. Purchased fitting envelopes in Blender are illustrative; actual fitting engagement must be measured before cutting.

The example below assumes g=17.4625 mm from each fitting center to the fully seated pipe end. For a rail between two fittings, cut = center spacing - 2g. For a mast or foot with one fitting, cut = end-to-center length - g. Mark seating depths, test a corner, and update cuts if the purchased fittings differ. Leave allowance for saw kerf; all listed stock nests have spare length.

- 4 x 2055.48 mm 1-inch Schedule 40 PVC, 33.4 mm OD: Square rails.
- 2 x 294.88 mm 1-inch Schedule 40 PVC: Lower legs.
- 2 x 637.34 mm 1-inch Schedule 40 PVC: Upper guy masts.
- 4 x 582.54 mm 1-inch Schedule 40 PVC: Grass half-feet.
- 4 x 1182.54 mm 1-inch Schedule 40 PVC: Hard-surface half-feet (swap for grass).
- 4 x 645.69 mm 3/4-inch Schedule 40 PVC, 26.67 mm OD: Corner braces.

For BOTH foot sets, buy six 10-ft sticks of 1-inch PVC: sticks 1-2 each yield one square rail + one mast + one leg; sticks 3-4 each yield one square rail + one grass half-foot; sticks 5-6 each yield two hard half-feet + one grass half-foot. One 10-ft stick of 3/4-inch yields all four braces. Grass-only can use five 1-inch sticks with the hard-foot cuts omitted.

Dry-assemble square and foot tees. Fully seat and mark each joint, square the frame, then drill 4.5 mm retention holes through each structural fitting/pipe interface for an M4 x 60 bolt and wingnut (18 occupied ports total). Orient bolts so they clear other sockets and feet. No solvent welding is required for this prototype. Add one M4 cross-bolt at about 3085 mm height on each mast; guy loops tie around the pipe below this stop. Six caps finish the four feet and two masts. Model hardware shows positional envelopes rather than thread detail.

## Corner braces: positively clamped at both ends

Each brace connects points 400 mm along the two adjoining square sides, with 40 mm pipe overhang past each crossing. Cut length is sqrt(400²+400²)+80 = 645.69 mm. Four braces need eight joints.

Each joint uses one 6 mm CROSS_PLATE and four identical V_BLOCKs. Put two V blocks around the 33.4 mm main pipe on one face of the plate; their flat outer faces and plate holes align. Use the plate's straight hole pair and two M4 x 80 bolts, washers and nuts. On the other face, rotate another V-block pair +/-45 degrees, align its holes with the appropriate diagonal pair, and clamp the 26.67 mm brace with two M4 x 70 bolts. The other diagonal holes stay empty. Tighten alternately until gripping; do not crush the pipe. Check both ends for rotation and axial slip. The main/brace axes are about 60.475 mm apart in depth. This replaces the earlier cross-lashing entirely.

## Align the sixteen face docks

Each dock uses two PVC_HALF_33 halves, one DOCK_SOCKET and one DOCK_TONGUE already fitted to the middle rung. Bolt the receiver's two base holes to the mounting pad on the inward collar half (two M3 x 25 cap/pan bolts, washers, nuts). Assemble the halves loosely around the appropriate square rail with two more M3 x 25 cap/pan bolts. The receiver mouth faces toward the gate front.

Use the finished border as the alignment jig: engage all four tongues in their receivers, place the paper rectangle at its intended pinwheel position, and slide/rotate the collars until all docks sit without strain. Then tighten the collar bolts evenly and label their positions. Do not independently measure and tighten sixteen collars and expect all four-panel interfaces to register perfectly.

Each face border snaps to the common PVC square at four points; neighboring face borders meet at butt seams. They do not need separate frame-to-frame corner snaps: the shared backbone locates them. The four 2090.4 x 609.6 rectangles rotate 90 degrees successively in a pinwheel, producing the 2700 mm outside / 1480.8 mm opening with no corner paper patches.

## Field setup and teardown

Assemble marked PVC square rails and tees with retention bolts. Fit feet and masts, clamp the four corner braces, and check the square. On soil use the 1200 mm fore-aft foot set and four appropriate ground anchors. On hard ground use the 2400 mm foot set, rubber pads, and four weighed 15 kg ballast bags secured to the feet with straps. This 60 kg arrangement is a test starting point, not a certified wind limit or universal ballast prescription.

Tie front/rear guy pairs below the mast stop bolts and run them to stakes or the far foot ends. Start guy attachment at about 3075 mm: for the front hard-surface anchor 1150 mm from the pipe plane, the straight guy crosses the paper plane above 2810 mm, clearing the 2750 mm face top. Do not instead tie front guys to the 2445 mm upper square rail, which routes them through the paper. Keep guys outside the flight opening, tension evenly with optional mini line runners, and verify stakes/ballast do not move.

With two people, hold each rigid border against its four receivers, press the tongues home and visually check all hooks. Keep paper in the pinwheel layout. Adjust only slack X bays, check feet, all PVC fasteners, paper pads and the clear flight opening. Start testing in calm conditions, then controlled mild airflow; withdraw the paper face if it flaps, slips or destabilizes the frame. No wind rating is claimed for this prototype. As a sizing screen only, the 5.097 m² paper face at 5 m/s, air density 1.225 kg/m³ and assumed drag coefficient 1.3 gives about 101 N drag using the NASA drag equation. Doubling that force for a simple allowance gives about 284 N·m at 1.4 m height. Ideal centered 60 kg ballast with a 1.2 m lever arm gives 706 N·m, but this ignores joint flexibility and depends on ballast attachment; sliding would require friction coefficient above about 0.35. These assumptions are not a measured wind limit. Verify actual ground grip and assembly behavior.

For teardown, support a border, pinch both spring tips of each dock from behind and pull it forward evenly. Never pull against a still-latched dock. Leave each border's rails, X cords, tongue flanges and magnetic paper clamps assembled. Protect paper/pads for transport. Release guys and remove marked PVC bolts/brace clamps as needed. Stored borders are roughly 2.09 m long, 0.61 m wide and about 0.10 m deep with tongues; they are not intended to fold.

## Hardware, quantity and verification files

[Hardware_BOM.csv](Hardware_BOM.csv) lists all purchased pieces, [PVC_Cuts.csv](PVC_Cuts.csv) all cuts, [Print_Queue.csv](Print_Queue.csv) the recipes/repetitions, and [Every_Plate_Run.csv](Every_Plate_Run.csv) all 112 runs in order. The queue below includes full gate quantities, no allowance for spares or rejected prototypes.

| Plate recipe | Runs | Pieces/run | PETG/run | Time/run |
|---|---:|---:|---:|---:|
| Q_EDGE_PLAIN_FULL | 21 | 3 | 73.2 g | 170 min |
| Q_EDGE_PLAIN_TAIL | 1 | 1 | 24.5 g | 62 min |
| Q_EDGE_BRANCH_FULL | 24 | 2 | 73.4 g | 180 min |
| Q_RUNG_FULL | 24 | 3 | 73.4 g | 175 min |
| Q_CLICK_KEY_FULL | 25 | 8 | 26.9 g | 86 min |
| Q_PAPER_PAD_FULL | 3 | 36 | 53.6 g | 140 min |
| Q_PAPER_PAD_TAIL | 1 | 28 | 41.7 g | 110 min |
| Q_PVC_HALF_33_FULL | 3 | 10 | 72.3 g | 200 min |
| Q_PVC_HALF_33_TAIL | 1 | 2 | 14.5 g | 46 min |
| Q_DOCK_SOCKET_FULL | 1 | 12 | 106.7 g | 256 min |
| Q_DOCK_SOCKET_TAIL | 1 | 4 | 35.6 g | 90 min |
| Q_DOCK_TONGUE_FULL | 1 | 12 | 101.8 g | 278 min |
| Q_DOCK_TONGUE_TAIL | 1 | 4 | 34.0 g | 100 min |
| Q_V_BLOCK_FULL | 2 | 12 | 194.4 g | 441 min |
| Q_V_BLOCK_TAIL | 1 | 8 | 129.6 g | 297 min |
| Q_CROSS_PLATE_FULL | 2 | 4 | 70.8 g | 155 min |

Validation: ten closed manifold masters with positive volume; bed dimensions/margins and plate non-overlap; exact BOM vs plate quantity; full-scene counts vs BOM; four sampled key/socket mating checks; every supplied plate sliced with no warnings and supports disabled. Source JSON reports are [geometry_checks.json](geometry_checks.json), [print_checks.json](print_checks.json) and [scene_counts.json](scene_counts.json). The interface sampling is not exhaustive collision proof. No physical pull, fatigue, magnetic grip, wind, creep or stability test has yet been performed. Purchased fitting envelopes and fastener heads are simplified; measure real components.

## Research used

- [Atwood 275 cord](https://atwoodrope.com/products/275-tactical-mystery-spools-1000ft): 2.4 mm, polyester/nylon, manufacturer tensile specification; this does not rate printed parts.
- [Atwood micro cord](https://atwoodrope.com/products/1-18mm-white): 1.18 mm, 125-ft spool, $6.99 observed September 17, 2026. Two spools cover the 66 m face allowance, about $13.98 before shipping; not enough for the whole face-plus-guys cut list.
- [Atwood 550 paracord](https://atwoodrope.com/products/550-x-100ft-paracord-infiltrate): 4 mm. This larger size needs a different printed cord guide.
- [Into the Wind kite line](https://intothewind.com/catalogsearch/result/?q=Braided+dacron): 500-ft 50-lb braided Dacron listed $24; about $10.39 allocated to 66 m, versus the cost of buying a whole spool. Verify actual diameter and cleat hold.
- [Clamcleat mini Line-Lok](https://www.clamcleat.com/mini-line-lok.html): commercial small-line adjustment option. Use a model whose stated range includes 2.4 mm; four optional units are for the external guys.
- [NASA drag equation](https://www1.grc.nasa.gov/beginners-guide-to-aeronautics/drag-equation/): equation used only for the explicitly assumed stability screen.
- [Charlotte Pipe product knowledge](https://www.charlottepipe.com/uploads/documents/technical/BR-PK.pdf): nominal sizing and outside diameters; actual purchased socket engagement governs cut length.
- [K&J magnetic closures](https://www.kjmagnetics.com/blog/magnetic-closures): magnetic retention depends on geometry/gap. Prototype the complete frame/paper/pad stack.
- Earlier click-joint research and user picture-frame attribution remain in [the committed study](../paper_roll_study/RESEARCH.md). New reinforced CAD is original geometry; the downloaded example is reference only.

Rebuild from repository root: `blender --background --python scripts/build_full_paper_gate.py -- --no-render`, `python3 scripts/slice_full_paper_gate.py`, `blender --background --python scripts/render_full_paper_gate.py`, `python3 scripts/validate_full_paper_gate.py`, then run `scripts/package_full_paper_gate.py` with Python containing ReportLab. No printer job has been submitted.

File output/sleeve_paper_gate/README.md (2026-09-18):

# Integral PVC sleeve gate

This revision replaces the bolted face-to-PVC dock with **one printed RUNG_SLEEVE**. The frame segment, tapered root and closed pipe loop are one connected manifold part. There are **no bolts, nuts, split collars, separate dock tongues or extra cord stays at this attachment**. The existing PVC corner fittings complete the square as requested. The cords that brace the face bays remain.

[Blender assembly](Sleeve_Paper_Gate.blend) opens at the new attachment. See the [bare part](renders/10_SLEEVE_PRINT_FACE.png), [PVC threaded through it](renders/06_INTEGRAL_PVC_SLEEVE.png), [full gate](renders/01_ASSEMBLED_FRONT.png), [assembly PDF](Sleeve_Gate_Assembly.pdf), and [printable kit](Sleeve_Paper_Gate_Kit.zip).

## The new part

- Native print bounds: **133.867 x 49.95 x 78.668 mm**, well inside the A1 Mini's 180 mm cube.
- Designed pipe: **33.4 mm outside diameter** (the nominal 1-inch Schedule 40 PVC already used in this project).
- Trial bore: **34.2 mm** across the circular portion, giving nominal 0.8 mm diametral clearance. This is a sliding fit, not a press-fit clamp.
- Continuous loop wall: **6 mm** nominal; sleeve length along the pipe: **24 mm**.
- Broad root: **68 mm** across the rung and **24 mm** along the pipe, tapering upward into the closed loop. No narrow dock neck or flexible latch carries the sleeve-to-rung connection.
- Pipe center: **46 mm behind the paper**, reduced from 98.9 mm. The pipe's front is 29.3 mm behind the face, giving about 5.1 mm clearance to the modeled bracing-cord envelope.
- The upper opening has a 45-degree peaked roof. Its lower 270 degrees follow a circle; the peak adds clearance above the pipe so the part prints flat on its paper face without support inside a round ceiling. The peak does not key into or tightly clamp the round pipe.
- The existing frame click interface and magnetic D lug are retained. The normal RUNG is also simplified by removing its unused M3 mounting holes.

Use four sleeves per border, sixteen per gate. Six crossmembers per border still consist of three segments each; only the middle segments of crossmembers 2, 3, 4 and 5 become RUNG_SLEEVE. The other fourteen segments per border are plain RUNG.

## First print: frame click test

Start with the separate [four-piece A1 Mini frame test](../first_frame_print/index.html): two identical production EDGE_BRANCH rails and two CLICK_KEY connectors. It tests straight and perpendicular connections using the same parts. The fifth PAPER_PAD is optional on an alternate plate. See its illustrated assembly/test PDF before printing a full bay.

## Subsequent PVC sleeve fit test

**One sleeve:** open [Q_RUNG_SLEEVE_TAIL](sliced/Q_RUNG_SLEEVE_TAIL/Q_RUNG_SLEEVE_TAIL_A1Mini_PETG.3mf). It contains exactly one production sleeve rung: **49.41 g / 140 minutes**. Print it flat in the supplied orientation, deburr the bore's entry edges, and slide a clean, measured PVC offcut through it.

**Combined fit plate:** [T00_SLEEVE_FIT](sliced/T00_SLEEVE_FIT/T00_SLEEVE_FIT_A1Mini_PETG.3mf) contains one sleeve, three short bore gauges, two click keys and one magnetic pad: **7 pieces / 77.13 g / 219 minutes**. The gauges are left-to-right 34.0, 34.2, 34.4 mm as seen from the plate front in Bambu Studio. Mark them before removing them. Their horizontal print orientation matches the sleeve's bore; a short gauge does not prove the fit over the full 24 mm sleeve length.

Use PETG, 0.4 mm nozzle, 0.20 mm layers, **4 walls, 20% infill, no supports, no brim**. These are actual local Bambu Studio slices. All supplied recipes are warning-free. The source STL is [RUNG_SLEEVE.stl](printable/RUNG_SLEEVE.stl). No print job has been submitted.

The pipe should slide by hand through the full sleeve without force or splitting, and the keys should seat and release normally. If 34.2 mm does not fit the actual pipe/printer combination, use the gauges to choose a revised bore and regenerate; do not force the pipe or scale the whole part, which would also change the click geometry. Check the molded lettering, burrs and OD variation along the actual pipe, not only one end. Then assemble a bay and check its behavior on the completed square, including movement, handling and warm-weather relaxation. Physical strength and service life are not yet established.

## What this removes

Each old attachment used a plain rung plus two collar halves, a receiver and a tongue. The new attachment uses one sleeve rung. Across the gate it removes **64 printed pieces, 96 M3 bolts, 96 M3 nuts and 160 M3 washers**. The old three attachment part types disappear; one sleeve-rung type is added. With optional front pads fitted, main-gate printed types fall **10 to 8**, pieces **624 to 560**. Omit all 136 optional PAPER_PAD parts for **424 pieces / 7 types**.

| Current part | Quantity | Print bounds mm |
|---|---:|---|
| EDGE_PLAIN | 64 | 136.314 x 49.95 x 12.0 |
| EDGE_BRANCH | 48 | 136.314 x 76.0 x 29.0 |
| RUNG | 56 | 133.867 x 49.95 x 12.0 |
| CLICK_KEY | 200 | 66.0 x 32.0 x 5.0 |
| PAPER_PAD (optional) | 136 | 24.0 x 24.0 x 3.0 |
| RUNG_SLEEVE | 16 | 133.867 x 49.95 x 78.668 |
| V_BLOCK | 32 | 24.0 x 64.0 x 22.0 |
| CROSS_PLATE | 8 | 70.0 x 70.0 x 6.0 |

The renders show optional front pads fitted. PAPER_PAD is optional throughout the BOM and queue. Per border, omitting its 34 pads leaves 96 pieces. Four borders plus the 40 brace pieces total 424 without pads. The three gauge sizes are optional test pieces and are not gate part types or included in 560. Per border: 16 EDGE_PLAIN, 12 EDGE_BRANCH, 14 RUNG, 4 RUNG_SLEEVE, 50 CLICK_KEY and 34 PAPER_PAD = 130 pieces. Four borders total 520. Existing PVC corner braces add 32 V_BLOCK and 8 CROSS_PLATE = 40.

## Revised print and material totals

Full gate **with optional pads**: **6.995 kg PETG, 286.0 printer-hours, 105 plate runs**. A 10% material allowance is 7.69 kg, so plan eight 1 kg spools. At an assumed $20/kg, the deposited plastic is about $140; hardware, PVC, paper and cord are additional. Compared with the previous bolted version this saves 135 g of plastic, 8.9 printer-hours and seven plate runs. The main improvement is less assembly work and fewer small attachment components; this remains a large printing project.

Without front pads: **6.792 kg PETG, 277.2 printer-hours, 101 plate runs**. Skip the Q_PAPER_PAD recipes to save 202.36 g and 8.83 printer-hours. Both configurations use 272 magnets when all 136 face attachment sites are populated; only the front plastic pads are optional.

[Print_Queue.csv](Print_Queue.csv) lists each production plate recipe and repeat count. [Every_Plate_Run.csv](Every_Plate_Run.csv) lists every run individually. Test prints are extra unless you subtract their accepted pieces from production totals. Filament estimates include the selected slicing profile and startup assumptions; manual plate handling, failed prints, glue cure time and physical assembly are not included in printer-hours.

## Reusable full-width test bay

Print T01_BRANCH four times, T02_RUNG once, T03_BAY_SLEEVE once and T05_SINGLE_PLAIN twice. This produces **32 pieces**: four branches, two plain edge rails, five plain rungs, one sleeve rung, twelve keys and eight optional pads. The supplied recipes include those pads; omitting them leaves 24 structural pieces, and requires removing those objects and re-slicing the mixed test plates. The assembled bay is **436.943 x 609.6 mm**. Add one 3.3 m bracing cord, sixteen 6 x 2 mm magnets, a paper rectangle, and a 33.4 mm OD pipe offcut.

This kit is 417.5 g and 18.12 printer-hours over eight runs. The sleeve replaces the middle rung of one of the two crossmembers. Thread the pipe through it; there is no separate dock assembly. All 32 pieces can be used in the full gate. The separate T04_BRACE plate tests the existing corner-brace clamps.

## Workshop assembly of a full border

1. Build two long rails. Each rail uses fourteen 136.314 mm bodies and thirteen CLICK_KEYs with 14 mm exposed middles, totaling 2090.4 mm. Use EDGE_BRANCH at zero-based positions 0, 2, 5, 8, 11, 13; the remaining eight positions are EDGE_PLAIN. Face all branch sockets inward. Rotate the opposite long rail 180 degrees; the symmetric pattern aligns its branches.
2. Make six three-segment crossmembers. Put a RUNG_SLEEVE in the middle of crossmembers 2 through 5. Crossmembers 1 and 6 use only plain RUNG. Every crossmember needs four keys: two internal and one at each end. Use the same paper-facing plane for all pieces and point every loop toward the back.
3. Join both long rails to the crossmembers. Check 2090.4 x 609.6 mm overall dimensions, equal diagonals and full engagement of both key catches. The sleeve centerline passes through the centers of its four loops at 304.8 mm across the border. The sleeve axes run along the long direction.
4. Thread and tension the five X bays as below. Keep these cords installed during transport. There are no extra sleeve-positioning cord stays.
5. Populate 28 long-edge magnet lugs and six middle-rung lugs, leaving twelve outer-rung pockets empty. Use 34 loose front magnets, or optionally bond those magnets into 34 PAPER_PAD parts for easier handling and a larger paper contact area. Check polarity and fit before bonding. Without pads the stack is rear magnet, unchanged 0.4 mm rail skin, paper, bare front magnet. With pads it is rear magnet, unchanged 0.4 mm rail skin, paper, 0.4 mm pad skin, front magnet. The frame-side holder is unchanged in both configurations. Test grip with the actual paper and adhesive cure; magnet dimensions alone do not establish holding force.
6. Cut one 2090.4 mm length from the 609.6 mm-wide roll. Attach paper after the first complete frame fit-up to avoid damaging it during initial handling. Repeat for four identical borders. The four rectangles form a pinwheel with 2700 mm outside and 1480.8 mm opening; no corner paper patches are required.

## PVC threading and corner assembly

Thread each **bare straight square rail** through the four loops of its border before installing PVC tees, end fittings or brace clamps. Fittings cannot pass through the sleeve. The four pipe axes and four PVC corner fittings form the backing square. Mark pipe insertion depths and border positions after the first successful full assembly.

On a padded flat surface, arrange the four borders in the pinwheel. Build a top U assembly with the top pipe and its two corner tees. Insert the left/right pipe ends into those tees. Fit the bottom pipe into its two tees, then bring this bottom U assembly onto the two exposed parallel side-pipe ends together. Fully seat the sockets and square the assembly. Support the printed borders while moving the PVC. Confirm the real fitting sizes allow the intended joints to seat before drilling any retention holes.

The prior M4 retention bolts in the PVC corner/foot fittings and the V clamps on the PVC corner braces are still listed in Hardware_BOM.csv. They belong to the backing structure; **none attaches the printed face to its pipe**. This change removes the pictured bolted dock, not the existing brace and base design. No extra cord stays or attachment fasteners have been added to the sleeves.

The square's centerline spacing remains 2090.4 mm. Its lower/upper horizontal centerlines remain 354.8 / 2445.2 mm above ground, but its plane moves forward to **46 mm behind the paper**. The 3/4-inch corner braces remain 60.475 mm behind the main pipe plane. Paper spans ground heights 50 to 2750 mm. Upper guy masts extend to 3100 mm.

Sleeves are closed, so a border does not snap straight off an assembled square. For teardown, support the border and release the relevant corner fittings and brace clamps; then slide the pipe out, or leave it threaded for transport. With fittings and interfering brace hardware removed, the pipe can slide about 304.8 mm inward from its assembly position to fit inside the border's 2090.4 mm transport length. Its parked extent is about 17.5 to 2072.9 mm from the border end. Mark both positions. Reposition it at setup before joining corners. Do not force installed fittings or clamps through a loop.

The circle is a clearance bore, so this design does not claim that every individual sleeve is a friction clamp or a rotational key. Per your instruction, the trial assembly relies on the completed PVC square and corner fittings without extra stays. Check the assembled result before producing all sixteen sleeves.

## Pipe cuts, braces and base

See PVC_Cuts.csv for quantities and example lengths. The four 1-inch square rails are 2055.48 mm; two lower legs 294.88 mm; two upper masts 637.34 mm; four grass half-feet 582.54 mm; four alternative hard-surface half-feet 1182.54 mm. The four 3/4-inch braces are 645.69 mm. These are example cuts using 17.4625 mm fitting-center-to-seated-pipe-end take-up. Measure actual purchased fittings before cutting. For two fittings, cut = center spacing minus both take-ups. Purchased fitting models are illustrative envelopes.

For both foot sets, six 10-ft sticks of 1-inch PVC can be nested as follows: sticks 1-2 each make a square rail, upper mast and lower leg; sticks 3-4 each make a square rail and grass half-foot; sticks 5-6 each make two hard-surface half-feet and one grass half-foot. One 10-ft stick of 3/4-inch makes all four braces. Use six 1-inch tees (four square corners plus two foot tees), six caps (four foot ends plus two mast ends), and the existing retained-fitting hardware in Hardware_BOM.csv.

Brace crossings lie 400 mm along adjoining sides from each square corner. Each pipe projects 40 mm past its two crossings, giving sqrt(400² + 400²) + 80 = 645.69 mm. Each crossing uses four identical V_BLOCK halves and one CROSS_PLATE. Use the straight plate-hole pair with two M4 x 80 bolts for the main pipe; use the appropriate +/-45-degree pair with two M4 x 70 bolts for the brace. Add washers/nuts and tighten alternately until gripping without crushing pipe or printed parts. Four braces require eight crossings. Test slip and rotation using the actual pipe before relying on them.

For soil, use the 1200 mm fore-aft foot set and four suitable ground stakes. For hard surfaces, use the 2400 mm foot set, rubber pads and four attached 15 kg ballast bags. That 60 kg arrangement is an initial test setup, not a wind rating. Retain all structural PVC fitting ports with the specified M4 bolts after seating and squaring. Attach the four external guys below mast stop bolts at roughly 3075 mm high; the upper extensions route the front guys above the paper. Do not attach front guys to the lower 2445.2 mm square rail, where they would cross the face. Keep guys outside the flight opening and attach ballast securely to the feet.

## Face cord adjustment

Use 2.4 mm 275 paracord. Cut twenty equal 3.3 m face cords and four 4 m external guys: 82 m total, covered by three 100-ft hanks with 9.44 m spare. The face-bracing cleats remain integrated into EDGE_BRANCH; no separate tensioner is needed there.

For each bay, viewed from behind, label its inward-facing eyes lower-left (LL), upper-right (UR), lower-right (LR), upper-left (UL). Tie a stopper larger than the eye; thread LL -> UR -> LR -> UL -> LL. The cord makes two diagonals and two short return legs. Turn outside the posts after threading their transverse holes. Feed slack progressively around all four eyes, pull the return tail, make two figure-eight wraps around the lower-left branch's two posts, and finish with a locking half-hitch. Leave a 100 mm tail. Hand-tension only until slack is removed and the rail stays straight. To adjust, hold the tail, undo the hitch, unwrap, feed slack and rewrap. Keep all five bays threaded in transport.

## Verification and first-use checks

All eleven exported masters (eight production types and three optional gauges) are manifold, positive-volume and inside the A1 Mini envelope. The sleeve is **one connected mesh**, not overlapping independent solids. Every supplied plate has at least 5 mm bed margin, no part overlap and no slicer warnings with supports disabled. Production plate counts match the 560-piece BOM and full-scene instances. Sampled key interfaces show no penetration; the modeled PVC circle has at least 0.39 mm clearance to the bore polygon. These digital checks are not physical strength or fatigue tests.

Start with the separate four-piece frame click test. Then use a measured pipe offcut and the full sleeve. Check insertion, removal, key engagement and visible cracking or whitening while applying modest hand loads in all directions. Next test a full-width bay, then one full border, then the complete square in calm conditions. Check sleeve roots, frame keys, cord slip, pipe-brace grip, magnetic retention and base stability. Recheck after repeated assembly and warm outdoor exposure. The 6 mm wall and broad root are design dimensions, not a tested load rating. No wind rating is claimed.

The prior research on nominal pipe OD, PETG click joinery and cord remains in [the preceding guide](../full_paper_gate/README.md#research-used); this revision's dimensions and estimates come from its local CAD and slicer. No physical prototype has been printed here. No printer job was submitted.

Rebuild with scripts/build_sleeve_paper_gate.py, slice_sleeve_paper_gate.py, render_sleeve_paper_gate.py, validate_sleeve_paper_gate.py and package_sleeve_paper_gate.py. Slicing requires locally installed Bambu Studio; packaging requires ReportLab.

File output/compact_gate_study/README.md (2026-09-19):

# Compact gates: 1000 / 800 mm openings and 24 / 18 / 12-inch paper

**Use fewer sleeves, not the original 48.** With the current accepted fittings and a trial maximum edge-magnet gap of 350 mm, the compact gates need **32 / 24 / 16 sleeves** for **24 / 18 / 12-inch paper**, respectively. Both openings use these counts. Smaller paper bands reduce PVC, paper and sleeve requirements while keeping the chosen opening unchanged.

**Suggested next build: 1000 mm opening with 12-inch paper.** It uses **32 printed parts, 1.883 kg PETG and 74h 21m**, versus 64 parts, 2.325 kg and 94h 28m for the current large gate. It retains about 299 mm centered side clearance to the imported MK4's full propeller sweep. The 800 mm version has 199 mm side clearance and saves one more PVC stick, but uses the same printed parts at this magnet-spacing target.

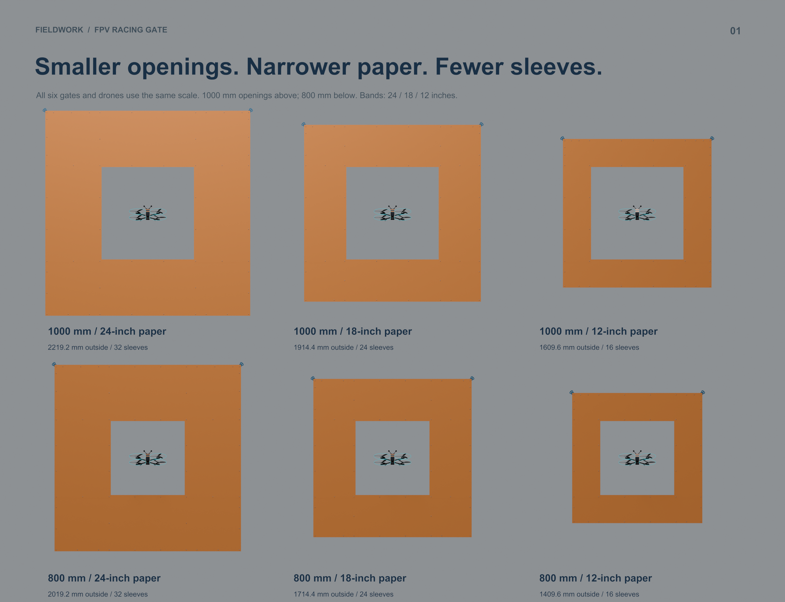
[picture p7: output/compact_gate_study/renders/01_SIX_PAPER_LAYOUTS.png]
Six gates at the same scale


[Blender study](Compact_Gate_Study.blend) · [Visual PDF](Compact_Gate_Study.pdf) · [Render gallery](index.html) · [Comparison CSV](Comparison.csv) · [Detailed data and checks](study.json)

**Workshop cutting:** [PVC cut guide PDF](PVC_Cut_Guide.pdf) and [cut tables / ratchet stock layouts](PVC_Cut_Guide.md). The ratcheting-cutter guide reduces the 1000 mm / 24-inch variant to five PVC sticks; the comparisons below retain the earlier conservative saw allowance of six.

## Material and print comparison

| Opening mm | Paper width | Outer mm | Sleeves / all parts | PETG kg | Print time | PVC sticks | Priced subtotal |
|---:|---:|---:|---:|---:|---:|---:|---:|
| 1480.8 current | 24 in | 2700.0 | 48 / 64 | 2.325 | 94h 28m | 8 | $69.53 |
| 1000 | 24 in | 2219.2 | 32 / 48 | 2.104 | 84h 20m | 6 | $55.86 |
| 1000 | 18 in | 1914.4 | 24 / 40 | 1.993 | 79h 18m | 5 | $49.03 |
| 1000 | 12 in | 1609.6 | 16 / 32 | 1.883 | 74h 21m | 4 | $42.19 |
| 800 | 24 in | 2019.2 | 32 / 48 | 2.104 | 84h 20m | 5 | $50.52 |
| 800 | 18 in | 1714.4 | 24 / 40 | 1.993 | 79h 18m | 4 | $43.69 |
| 800 | 12 in | 1409.6 | 16 / 32 | 1.883 | 74h 21m | 3 | $36.85 |

Times and PETG use local **Bambu Studio A1 Mini PETG slices**, with seven-sleeve batch plates and exact tail quantities. No new fitting shapes are needed. 0.4 mm nozzle, 0.20 mm layer, four walls, 20% infill, textured PEI and supports disabled. The new two- and four-sleeve plates were sliced and verified; other recipes reuse the current verified production slices. These are slicer estimates, not measured machine runtimes. Full quantities assume printing from zero; subtract already printed fittings.

Costs use the owner's prices: $39.59 / 4 kg PETG, $19.99 / 800 magnets and $5.34 / 10-ft PVC stick. Subtotals include allocated PETG, both magnets of every pair, and whole PVC sticks. **Paper prices for each width were not supplied and are excluded**, along with guy lines, ground support, tax, electricity and failures. Roll yields below help compare actual paper prices without inventing prices.

## Where the parts disappear

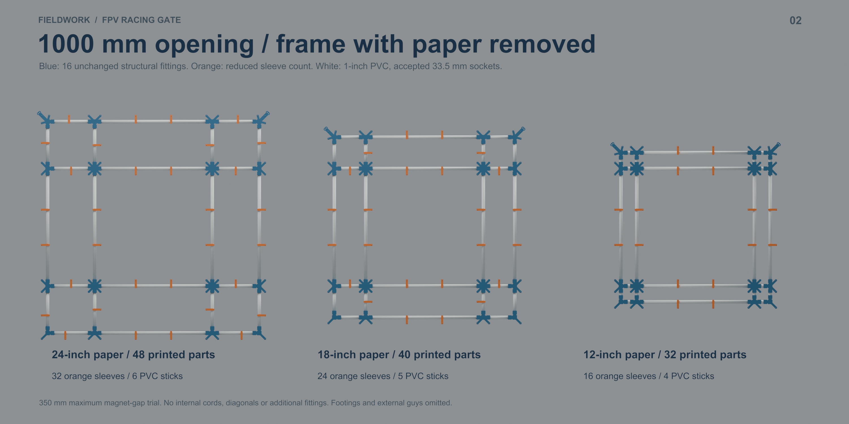
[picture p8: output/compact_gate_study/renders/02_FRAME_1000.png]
1000 mm frames with paper removed


All versions retain **2 bottom elbows + 2 top guy elbows + 8 tees + 4 crosses = 16 structural fittings**. These carry the orthogonal PVC grid and outer/inner paper supports. All accepted 33.5 mm bores, 30 mm insertion depths, guy eyes, paper alignment guides and magnet skins stay unchanged. This is a compatible layout reduction rather than a new lightweight fitting design.

- **24-inch band:** 16 sleeves on eight long pipes (two each), plus 16 sleeves on short pipes.
- **18-inch band:** 16 long-pipe sleeves, plus eight short-pipe sleeves at the paper overlap seams. Eight outer-corner sleeves disappear.
- **12-inch band:** 16 long-pipe sleeves. All sixteen short-pipe sleeves disappear; the fitting-mounted magnets cover the short sections and overlap seams.

Blue fittings and orange sleeves are render colors for identification; the user's filament is black. Magnets remain 18 mm in from the paper edges. Lowering sleeve count removes the sleeve and its two magnets. Empty, unused cross pockets stay unpopulated.

**Why 800 mm does not yet print faster than 1000 mm:** two intermediate magnets per long edge produce maximum long-edge gaps of **278.7 mm** and **345.3 mm**, respectively. One sleeve on an 800 mm long edge would create **418 mm** gaps, exceeding this study's 350 mm target. A later sparse-retention test could try that; it is not included in these six layouts.

**The next bottleneck is the large fittings.** The 16 structural pieces alone consume **1.661 kg / 63h 51m**, about 88% of the 12-inch version's PETG. The 12-inch layout halves the total part count but reduces PETG by **19.0%** and printer time by **21.3%**. Major further print savings require redesigning those fittings, not merely making the paper narrower. The complete 12-inch queue fits nominally within two 1 kg spools, with about 117 g spare before failures. No version here fits one spool. The 18-inch queue nearly exhausts two spools, so allow reserve.

## Paper, PVC and magnets

| Opening / band | 16 short PVC cuts mm | 8 long PVC cuts mm | PVC used m | Paper used m | Paper area m² | Gates / 100-ft roll | Individual magnets |
|---:|---:|---:|---:|---:|---:|---:|---:|
| 1000 / 24 in | 389.6 | 1080.0 | 14.874 | 6.5824 | 4.013 | 4 | 120 |
| 1000 / 18 in | 237.2 | 1080.0 | 12.435 | 5.9728 | 2.731 | 5 | 104 |
| 1000 / 12 in | 84.8 | 1080.0 | 9.997 | 5.3632 | 1.635 | 5 | 88 |
| 800 / 24 in | 389.6 | 880.0 | 13.274 | 5.7824 | 3.525 | 5 | 120 |
| 800 / 18 in | 237.2 | 880.0 | 10.835 | 5.1728 | 2.365 | 5 | 104 |
| 800 / 12 in | 84.8 | 880.0 | 8.397 | 4.5632 | 1.391 | 6 | 88 |

Each gate uses **four rectangular paper strips and four crosscuts**, keeping the full roll width: two top/bottom strips as long as the outer square, and two side strips as long as opening + 72 mm. Each side overlaps the top and bottom strips by 36 mm. No lengthwise ripping or corner patches are required. Roll yields assume a usable 30.48 m roll with negligible trimming allowance; allow extra for repairs or damaged paper. Paper area includes overlap. Compare roll cost per gate as **roll price divided by the whole-gate yield**, with leftover paper retained.

For 12-inch paper the short PVC cut is **84.8 mm**. Insert 30 mm at each end, leaving **24.8 mm** exposed between socket mouths. Do not attempt to add a short-pipe sleeve there. The actual fitted meshes were checked at these positions: no intersecting fitting pairs, and no unintended plastic visible beyond the paper. The diagonal guy ears intentionally remain exposed. Dry-fit one corner with your cutter before cutting all sixteen short pieces.

The stock layouts use 3048 mm sticks with 10 mm trimming reserve and 3 mm per cut allowance. A two-length integer packing check confirms the listed stick counts are minimal under those allowances. A ratcheting cutter does not remove a saw kerf; keeping the allowance provides a conservative measuring/trim margin. Pipe budgets exclude feet or other ground support.

A narrower band uses less material and presents less solid area to the wind, but does not establish a wind rating. The 350 mm edge-magnet target is a **layout assumption**, not a measured paper peel/tear limit. Paper grade, dampness, tension and gusts matter. Start with the 12-inch layout and test one full border using the actual roll and magnets; add long-pipe sleeves if edges flap or lift. Retain front/rear guys and suitable grass anchors or hard-surface ballast from the current design.

## Full print queues

Counts below apply to either opening with the given paper width. Each large fitting prints individually. Each full sleeve batch contains seven sleeves.

| Paper | Bottom elbow jobs | Guy elbow jobs | Tee jobs | Cross jobs | Seven-sleeve batches | Tail sleeves on one plate | Total plate runs |
|---:|---:|---:|---:|---:|---:|---:|---:|
| 24 in | 2 | 2 | 8 | 4 | 4 | 4 | 21 |
| 18 in | 2 | 2 | 8 | 4 | 3 | 3 | 20 |
| 12 in | 2 | 2 | 8 | 4 | 2 | 2 | 19 |

[Bottom elbow](../corner_guide_elbow/sliced/ONE_ELBOW/ONE_ELBOW_A1Mini_PETG.3mf) · [Guy elbow](../corner_guide_elbow/sliced/ONE_DUAL_GUY_ELBOW/ONE_DUAL_GUY_ELBOW_A1Mini_PETG.3mf) · [Tee](../corner_guide_elbow/sliced/ONE_TEE/ONE_TEE_A1Mini_PETG.3mf) · [Cross](../corner_guide_elbow/sliced/ONE_CROSS/ONE_CROSS_A1Mini_PETG.3mf) · [Seven sleeves](../corner_guide_elbow/sliced/BATCH_MAG_SLEEVE/BATCH_MAG_SLEEVE_A1Mini_PETG.3mf)

Tail plates: [2 sleeves for 12-inch paper](sliced/TAIL_MAG_SLEEVE_2/TAIL_MAG_SLEEVE_2_A1Mini_PETG.3mf) · [3 sleeves for 18-inch paper](../corner_guide_elbow/sliced/TAIL_MAG_SLEEVE_3/TAIL_MAG_SLEEVE_3_A1Mini_PETG.3mf) · [4 sleeves for 24-inch paper](sliced/TAIL_MAG_SLEEVE_4/TAIL_MAG_SLEEVE_4_A1Mini_PETG.3mf).

These projects are prepared locally; no job was sent to a printer. The current production folder remains unchanged.

## Build the selected size

1. Choose the opening and paper width; use the corresponding files below. Print only the missing parts.
2. Dry-fit one 84.8 mm corner section if using 12-inch paper. Confirm full 30 mm insertion at both ends and correct paper guide alignment.
3. Cut eight long and sixteen short PVC pieces. Slide sleeves onto each pipe **before** closing its ends with fittings. The cut CSV lists each sleeve center's distance from the pipe's cut start, with the start node encoded in its name.
4. Assemble the 4 × 4 node grid shown in scenes 02/03, placing the two guy elbows at the top. The cross has four ports; perimeter tees face into the grid. Clock sleeves toward the corresponding outer edge, opening edge or overlap seam as shown in Blender. The magnet CSV gives front-facing coordinates measured from the lower-left paper outline.
5. Cut the four paper rectangles. Align the outside corners and 36 mm side overlaps, then clamp at each populated magnet position. Confirm polarity before fixing magnets into their pockets.
6. Add suitable ground support and independent front/rear guys. Measure the actual opening and check friction retention, paper sag and magnet holding before flying. The render omits ground supports and guys for visibility.

- **1000 mm / 24 in:** [print queue](OPEN_1000_PAPER_24_Print_Queue.csv), [PVC cuts + sleeve positions](OPEN_1000_PAPER_24_PVC_Cuts.csv), [stock nesting](OPEN_1000_PAPER_24_Stock_Layout.csv), [paper cuts](OPEN_1000_PAPER_24_Paper_Cuts.csv), [magnet map](OPEN_1000_PAPER_24_Magnet_Positions.csv).
- **1000 mm / 18 in:** [print queue](OPEN_1000_PAPER_18_Print_Queue.csv), [PVC cuts + sleeve positions](OPEN_1000_PAPER_18_PVC_Cuts.csv), [stock nesting](OPEN_1000_PAPER_18_Stock_Layout.csv), [paper cuts](OPEN_1000_PAPER_18_Paper_Cuts.csv), [magnet map](OPEN_1000_PAPER_18_Magnet_Positions.csv).
- **1000 mm / 12 in:** [print queue](OPEN_1000_PAPER_12_Print_Queue.csv), [PVC cuts + sleeve positions](OPEN_1000_PAPER_12_PVC_Cuts.csv), [stock nesting](OPEN_1000_PAPER_12_Stock_Layout.csv), [paper cuts](OPEN_1000_PAPER_12_Paper_Cuts.csv), [magnet map](OPEN_1000_PAPER_12_Magnet_Positions.csv).
- **800 mm / 24 in:** [print queue](OPEN_800_PAPER_24_Print_Queue.csv), [PVC cuts + sleeve positions](OPEN_800_PAPER_24_PVC_Cuts.csv), [stock nesting](OPEN_800_PAPER_24_Stock_Layout.csv), [paper cuts](OPEN_800_PAPER_24_Paper_Cuts.csv), [magnet map](OPEN_800_PAPER_24_Magnet_Positions.csv).
- **800 mm / 18 in:** [print queue](OPEN_800_PAPER_18_Print_Queue.csv), [PVC cuts + sleeve positions](OPEN_800_PAPER_18_PVC_Cuts.csv), [stock nesting](OPEN_800_PAPER_18_Stock_Layout.csv), [paper cuts](OPEN_800_PAPER_18_Paper_Cuts.csv), [magnet map](OPEN_800_PAPER_18_Magnet_Positions.csv).
- **800 mm / 12 in:** [print queue](OPEN_800_PAPER_12_Print_Queue.csv), [PVC cuts + sleeve positions](OPEN_800_PAPER_12_PVC_Cuts.csv), [stock nesting](OPEN_800_PAPER_12_Stock_Layout.csv), [paper cuts](OPEN_800_PAPER_12_Paper_Cuts.csv), [magnet map](OPEN_800_PAPER_12_Magnet_Positions.csv).

## Blender, source and checks

Five scenes: six paper-on variants at the same scale; three bare 1000 mm frames; three bare 800 mm frames; both 12-inch-paper gates with the drone; and the compact lower-left corner. The source meshes are the actual accepted production parts. Geometry checks cover fitting-to-fitting intersections, paper coverage and magnet locations; queue checks cover exact quantities, bed fit and support-free slicing. Physical corner assembly, full-gate loads and paper retention remain untested.

The imported 7-inch MK4 is from Dendy / Printables 1515387, **CC BY-NC 4.0**, with the uploader's qualification that they did not create the underlying frame. The top battery is an assumed 110 × 40 × 45 mm addition. [Drone attribution and licenses](../../reference/geprc_mk4/ATTRIBUTION.md). Gate material and source code retain the project licenses. Clearances use the imported swept prop envelope, not just a static blade orientation.

Rebuild: `python scripts/plan_compact_gates.py`, `python scripts/slice_compact_gate_tails.py`, `blender -b -t 8 --python scripts/build_compact_gate_study.py`, then `python scripts/package_compact_gate_study.py` (ReportLab required for packaging). Existing production slices and the preceding drone Blender study are dependencies.

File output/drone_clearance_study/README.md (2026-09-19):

# MK4 7-inch drone / gate size study

The downloaded STEP assembly measures **401.3 mm across its full propeller sweep**. The current 1480.8 mm square opening leaves **539.8 mm on each side** when centered and approaching straight. A **1000 mm opening** is the suggested next trial: 299.4 mm per side and 54.4% less opening area. The 800 mm version is a tighter alternative, with 199.4 mm per side. These are geometry comparisons; approach speed, attitude and pilot accuracy determine the flying challenge.

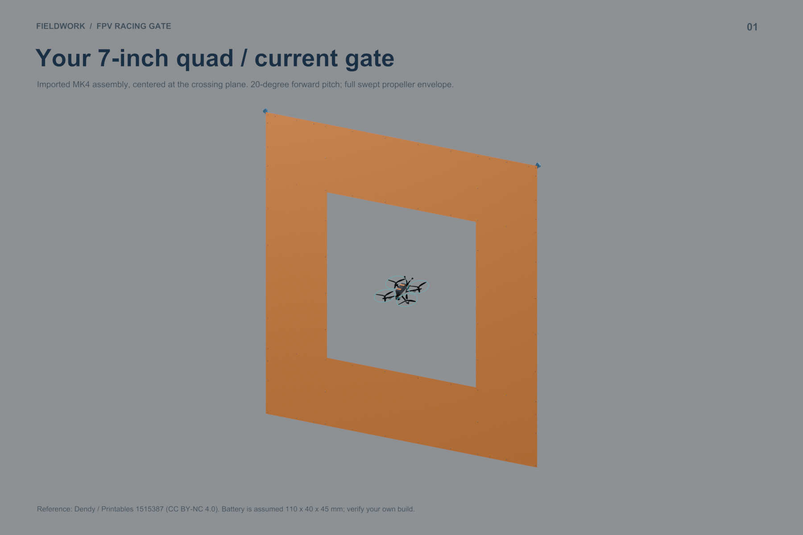
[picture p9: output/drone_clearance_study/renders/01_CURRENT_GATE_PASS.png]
Drone centered in the current gate


[Open the Blender study](Drone_Clearance_Study.blend) · [Visual PDF](Drone_Clearance_Study.pdf) · [Render gallery](index.html) · [CSV measurements](Clearance_Comparison.csv) · [Raw calculations](clearance.json)

## Equal-scale comparison

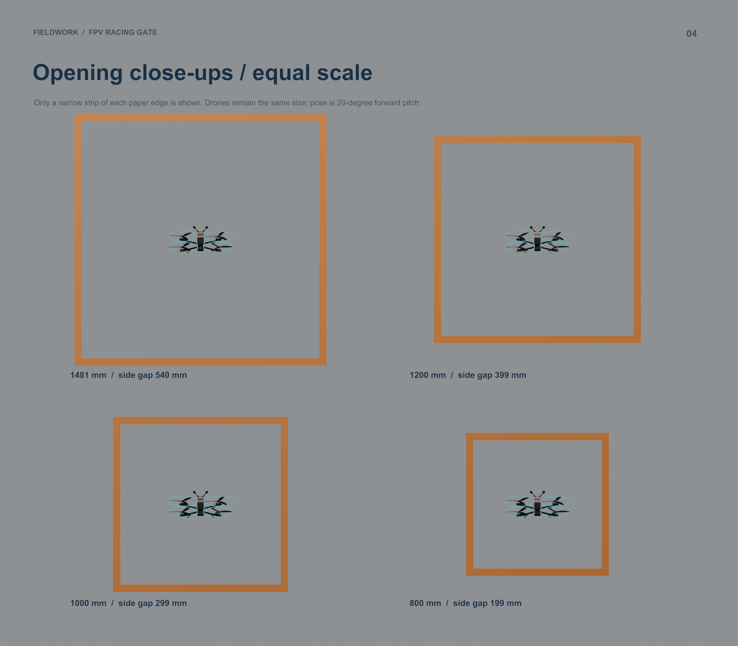
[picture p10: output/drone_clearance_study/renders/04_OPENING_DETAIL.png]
Four opening sizes with the same drone


All dimensions below are millimetres. Main pose: **20° forward pitch, zero yaw and roll**, with the projected swept envelope centered. Side and vertical values are gaps **per edge**, not total spare space. The outer dimensions retain 609.6 mm / 24-inch paper bands.

| Square opening | Outer square | Left / right gap | Top / bottom gap | Minimum side gap over level yaw |
|---:|---:|---:|---:|---:|
| 1480.8 | 2700.0 | 540 | 656 | 503 |
| 1200.0 | 2419.2 | 399 | 515 | 363 |
| 1000.0 | 2219.2 | 299 | 415 | 263 |
| 800.0 | 2019.2 | 199 | 315 | 163 |

The last column considers the propeller envelope over every yaw angle with the drone level. It is a separate case, not a bound for every possible flight attitude. At 45° yaw, 30° roll and 20° pitch, the example envelope is **392 × 279 mm** in the gate plane; see scene 07. Centering means centering the projected envelope, which can differ from centering the flight controller.

## What was measured

- Imported the actual 119-component STEP assembly from the user-supplied ZIP; preserved dimensions and applied only unit conversion and upright orientation.
- Motor diagonal: **294.3 mm**. The manufacturer lists a nominal 295 mm wheelbase for its [Mark4-7](https://geprc.com/product/gep-mark4-frame/); this is a cross-check, not certification that the downloaded assembly matches the user's exact build.
- The downloaded blades reach a **179.9 mm swept diameter**, slightly above nominal seven inches (177.8 mm). Calculations use the larger measured CAD radius and a complete rotating disc at every motor, not the blades' static orientation.
- Main projected envelope: **401.3 mm wide × 169.7 mm high**, including the supplied antenna/camera geometry and an explicitly assumed **110 × 40 × 45 mm battery** with straps. The download has no battery. A different battery, antenna or propeller can change the result.
- Blender mesh tessellation uses a 0.4 mm deflection setting. Numbers are suitable for a sizing study, not submillimetre inspection. Clearances are to nominal paper opening edges, without flight error, paper flutter or structural deflection allowances.
- Cyan circles illustrate swept propeller boundaries; they are not physical guards. Feet, ground anchors and guys are omitted from these clearance views.

## How the smaller gates reuse the current parts

All four scenes retain the same **64 fittings / five part types**, accepted 33.5 mm bores, actual PVC diameter and 24-inch paper bands. For a size change, replace the eight long PVC members and shorten the paper; the sixteen 389.6 mm PVC members remain. Four sleeves per long member remain in this comparison. Print quantities and slicer estimates therefore stay unchanged; later sleeve optimization is separate work.

| Opening | Long PVC cuts | Top + bottom paper lengths | Side paper lengths |
|---:|---:|---:|---:|
| 1480.8 | 8 × 1560.8 | 2 × 2700.0 | 2 × 1552.8 |
| 1200.0 | 8 × 1280.0 | 2 × 2419.2 | 2 × 1272.0 |
| 1000.0 | 8 × 1080.0 | 2 × 2219.2 | 2 × 1072.0 |
| 800.0 | 8 × 880.0 | 2 × 2019.2 | 2 × 872.0 |

All paper strips are 609.6 mm wide. Side strips include 36 mm overlap at each end. Pipe lengths retain the production design's 30 mm socket engagement and center offsets. This is a study cut schedule, not a replacement for the current production kit: dry-fit and verify assembled opening dimensions before batch cutting.

## Blender views

1. `01_CURRENT_GATE_PASS` — current full gate and drone at crossing.
2. `02_CURRENT_CLEARANCE` — straight-on dimensions to the paper edges.
3. `03_FOUR_OPENINGS` — four complete gates at equal scale.
4. `04_OPENING_DETAIL` — equal-scale opening close-ups; paper bands are cropped for visibility.
5. `05_DRONE_REFERENCE` — enlarged imported assembly, assumed battery and swept props.
6. `06_SMALLER_GATE_PASS` — suggested 1000 mm trial opening.
7. `07_ATTITUDE_COMPARISON` — straight and banked/turned examples in a 1000 mm opening.

Scenes 01 and 06 have a simple translation animation, frames **1–80**, crossing at **40**. This illustrates passage through the opening, not a flight dynamics simulation. The saved Blender file embeds the drone mesh and can be opened without the source ZIP.

## Source, license and reproduction

Drone reference: **Dendy**, [Printable parts for GEPRC MK4 7in FPV drone frame](https://www.printables.com/model/1515387-printable-parts-for-geprc-mk4-7in-fpv-drone-frame), supplied under **CC BY-NC 4.0**. Dendy explicitly disclaims original authorship of the included MK4 frame. See [attribution, license and modifications](../../reference/geprc_mk4/ATTRIBUTION.md) and the [supplied model PDF](../../reference/geprc_mk4/Printables_Model_1515387.pdf). Original gate material retains this project's separate license. No endorsement is implied.

Rebuild from the repository root after installing `cadquery-ocp` (conversion tested with OCP 8) and `reportlab` into an appropriate Python environment:

```sh
python scripts/import_geprc_reference.py --zip ~/Downloads/printable-parts-for-geprc-mk4-7in-fpv-drone-frame-model_files.zip
blender -b -t 8 --python scripts/build_drone_clearance_study.py
python scripts/package_drone_clearance_study.py
```

Conversion intermediates default to `/tmp/fpv-geprc-reference`; the 174 MB source STEP is not copied into this repository. The current production kit remains in `output/corner_guide_elbow/`.

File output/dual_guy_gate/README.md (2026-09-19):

# Dual front/rear guy elbow / diagonal ear

The previous PVC/tee design and workshop status were documented and committed as **6a7fb47** before this revision. That record includes the physically accepted 33.5 mm sleeve fit, the selected ONE_TEE PETG job opened in Bambu Studio, and the preference for checked PVC master pieces instead of printing measuring tools first. Tee completion has not been reported.

This revision replaces only the two top GUY_ELBOWs with **DUAL_GUY_ELBOW**. It adds simultaneous independent front and rear tie-downs, and moves the single corner magnet to one top-edge and one side-edge holder. All other production STLs are byte-for-byte identical to the committed tee iteration. PVC bores remain **33.5 mm**, with **30 mm engagement** and **35 mm center-to-stop**.

[Blender model](Dual_Guy_Gate.blend) · [Visual index](index.html) · [Assembly/test PDF](Dual_Guy_Assembly.pdf) · [Kit](Dual_Guy_Gate_Kit.zip)

## First print

[ONE_DUAL_GUY_ELBOW_A1Mini_PETG.3mf](sliced/ONE_DUAL_GUY_ELBOW/ONE_DUAL_GUY_ELBOW_A1Mini_PETG.3mf): **102.57 g PETG / 3.95 hours**. One required top corner, with both eyes and both magnet holders. Print one and test before making the second. No new job was opened or submitted, so the previously selected tee job is not replaced in Bambu Studio.

Bounds are **168.614 x 168.614 x 53.345 mm**. The supplied A1 Mini layout places it at X=5, Y=5, leaving at least 5 mm bed margin. Use the supplied flat-face-down orientation, 0.4 mm nozzle, 0.20 mm layers, four walls, 20% infill and Generic PETG. All supplied recipes slice without supports or warnings. The PVC sockets retain the accepted peaked roofs; both tie-down holes print vertically through the flat ear.

The old guy elbow used 77.39 g / 3.04 hours. Each replacement adds **25.18 g / 54.16 minutes**. Two replacements add **50.36 g / 1.81 hours** per gate, whether single or stacked.

## What changed

A **32 mm-wide, 14 mm-thick diagonal arm** runs from the central elbow body toward the outside paper corner. A sloped root rib rises to 28 mm behind the paper plane. The arm ends in a rounded ear containing **two 10.5 mm through-holes**, 18 mm apart on center. Each hole has a **0.8 mm, 45-degree chamfer** on both entrances, giving a 12.1 mm mouth. The straight bores have 8 mm outer edge material and 7.5 mm between holes; at the chamfer mouths these reduce to 7.2 mm and 5.9 mm respectively.

One hole takes the **front guy**, the other the **rear guy**. Each cord gets its own eye and attachment loop, so both can remain attached and be adjusted independently. The through-hole axes point front-to-back through the ear. There is no hidden rear-only eye requiring the front line to pass through paper. The same part rotates into both top corners; no mirrored file is needed.

The hole mouths lie completely beyond the paper outline. The ear projects up to **28.614 mm past the adjacent top/side edges**. This is an intentional visible exception to the earlier paper-only front: the paper remains uncut, and the PVC, body and magnet pads remain concealed behind it. Paper dimensions stay **2700 mm square single**, or **2700 x 4790.4 mm stacked**. Including the two ears, the hardware reaches about **2757.2 mm wide** and **2728.6 / 4819.0 mm high**, before feet.

The diagonal ear occupies the old corner-magnet direction. Its replacement pads lie along the **top and side edges**, each **18 mm inside the edge and 90 mm from the paper corner**. Both keep the existing 6.3 mm rear magnet pocket and **0.4 mm frame-side plastic skin**. Use the same 6 x 2 mm magnets. Optional front paper pads remain optional and are available in the earlier kit.

## Fit and thread both lines

1. Print one DUAL_GUY_ELBOW. Inspect the 0.4 mm magnetic skins, two vertical through-holes, diagonal arm and root rib. Clear loose strings and smooth any rough entrance edges without enlarging the PVC bores.
2. Fit two actual PVC offcuts and seat both sockets the full 30 mm, using insertion witness marks. The design bore stays 33.5 mm; the longer socket fit still needs its first physical check despite the successful sleeve print.
3. Thread a separate attachment loop through each eye and around its adjacent outside rim. Lead one guy toward the front of the gate and the other toward the rear. The orange/teal Blender lines show this routing; they are schematic loops, not a knot prescription. Choose appropriate secure knots/loops for the actual line and confirm knot clearance with both fitted simultaneously.
4. Use smooth cord or a protected connection at the plastic. Bare metal wire should not abrade directly against a printed edge. The modeled line diameter is **3 mm**; test the actual chosen cord or protected wire loop rather than treating this as a universal hardware fit.
5. Lay a paper corner over the fitting without a hole or notch. Align its two edges with the 18 mm magnet inset. Fit the two rear/front magnet pairs, and check that both cords can be connected and released with the paper in place. Bond rear magnets only after checking polarity and fit.
6. With the corner supported, try each guy independently, then both together, watching the elbow root and the pipe engagement marks. Check for visible flex that does not recover, whitening, cracks, cord-edge wear and socket withdrawal. Opposing guys do not remove the loads in the printed part. Repeat attachment/release and inspect again before committing to the second corner or an outdoor setup.

The digital routing check sampled **1046 points** on the illustrated loops and local tails against the actual printed mesh, with a minimum centerline distance of **5.049 mm** for 3 mm cord. The sampled paper crossings also clear the paper. Knots, flexible deformation and real line loads are not simulated. **This is a fabrication prototype with no assigned eye or wind load rating.** Ground support and anchor sizing remain separate installation work, particularly for the tall Split-S frame.

## Replace the top corners in the gate

Install two DUAL_GUY_ELBOWs in place of the two old GUY_ELBOWs. The native part has PVC ports +X and +Y; the assembly maps rotate it 270 degrees at upper left and 180 degrees at upper right. The ears point outside the overall corners. All stop positions, PVC lengths and paper cuts remain identical.

Facing the gate, the new top-left magnet centers are **(18, H-90)** and **(90, H-18)** mm from the paper's bottom-left origin. Top-right centers are **(2700-18, H-90)** and **(2700-90, H-18)**. H is 2700 mm for single or 4790.4 mm for stacked. The updated Magnet_Positions.csv files include these changes; remove the old single corner position at each top corner.

Each top elbow now needs two magnet pairs instead of one. Totals become **74 pairs / 148 magnets single**, or **118 pairs / 236 magnets stacked**: **four more individual magnets** than the committed tee design. Paper roll usage, overlap seams and all other magnet positions are unchanged.

| Required part | Single | Stacked total |
|---|---:|---:|
| ELBOW | 2 | 2 |
| DUAL_GUY_ELBOW | 2 | 2 |
| TEE | 8 | 12 |
| CROSS | 4 | 8 |
| MAG_SLEEVE | 48 | 80 |

The gate still has **five required printed types**, **64 pieces single / 104 stacked**. Single production estimate: **2.324 kg / 94.4 hours**, 23 plate runs. Stacked: **3.690 kg / 150.3 hours**, 36 plate runs. Count the sleeve already printed toward the BOM; full queues are from zero.

PVC requirements remain 16 short + 8 long cuts for single, or 24 short + 14 long for stacked, at **389.6 / 1560.8 mm**. Eight or fourteen 10-ft sticks at the supplied $6 price. At an assumed $20/kg PETG, PVC + PETG face-frame subtotals are **$94.47 / $157.81**, excluding magnets, paper, cord, adhesive and ground support.

## Full print queue

| Recipe | Single runs | Stacked runs | g/run | h/run |
|---|---:|---:|---:|---:|
| ONE_ELBOW | 2 | 2 | 68.47 | 2.69 |
| ONE_TEE | 8 | 12 | 98.49 | 3.77 |
| ONE_CROSS | 4 | 8 | 132.59 | 5.07 |
| ONE_DUAL_GUY_ELBOW | 2 | 2 | 102.57 | 3.95 |
| BATCH_MAG_SLEEVE | 6 | 11 | 96.74 | 4.46 |
| TAIL_MAG_SLEEVE_6 | 1 | 0 | 82.93 | 3.85 |
| TAIL_MAG_SLEEVE_3 | 0 | 1 | 41.5 | 2.07 |

Each CSV queue links to prepared A1 Mini PETG projects. Only ONE_DUAL_GUY_ELBOW is a new part/job; the other geometry matches the committed files. No print has been submitted.

## Assembly and extension

The row-by-row assembly from the [committed tee guide](../tee_pvc_gate/README.md) still applies, substituting the two new top elbows and new top magnet locations. Use checked PVC master pieces for repeated marking as recorded in the baseline; the optional jig is not required.

To extend upward, move the complete top row with both dual-guy elbows, its two tees, three pipes and sleeves. Add **4 tees, 4 crosses, 32 sleeves, 8 short PVC cuts and 6 long cuts**. Every existing pipe, fitting and populated magnetic attachment is reused. Two top elbows still provide four guys total: front and rear at each corner. Anchor endpoints and tension settings are not prescribed by the illustrative Blender views.

## Verification and source

Checks cover connected manifold masters; A1 Mini plate bounds, clearances and support-free toolpaths; exact queues and node ports; unchanged non-guy STLs; matching magnetic pockets; full hole-mouth clearance beyond paper; sampled cord/body and cord/paper clearance; and reuse of all single-height parts on extension. The exposed diagonal ear is explicitly allowed in the front-projection check; other protrusions fail it.

[Prusa's modeling guidance](https://help.prusa3d.com/article/modeling-with-3d-printing-in-mind_164135) discusses how geometry and print orientation affect mechanical behavior. The arm dimensions and cord layout here are original prototype choices, not a strength rating derived from that source.

Rebuild with scripts/build_dual_guy_gate.py, slice_dual_guy_gate.py, validate_dual_guy_gate.py and package_dual_guy_gate.py. Baseline commit: **6a7fb47**. The new iteration is separate in output/dual_guy_gate; earlier printable parts and documentation remain intact.

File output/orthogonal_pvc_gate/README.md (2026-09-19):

# Three-type PVC gate / friction-fit iteration

The gate now uses **one elbow, one cross and one magnetic sleeve design**. All pipe connections and sleeve positioning use friction. Straight PVC links join the inner and outer perimeters into a rectangular grid. The earlier corded iteration remains in ../pvc_paper_gate for comparison.

[Blender model](Orthogonal_PVC_Gate.blend) · [Visual index](index.html) · [Assembly PDF](Orthogonal_Gate_Assembly.pdf) · [Complete kit](Orthogonal_PVC_Gate_Kit.zip)

## Required parts and actual slicing estimates

| Part | Single gate | Two-level total | Print bounds, mm |
|---|---:|---:|---|
| ELBOW | 4 | 4 | 133.314 x 133.314 x 53.345 |
| CROSS | 12 | 20 | 136.627 x 136.627 x 53.345 |
| MAG_SLEEVE | 48 | 80 | 20.0 x 86.75 x 53.345 |

There are **3 unique required printed types**. Fit gauges are tooling. PAPER_PAD is optional. Quantities above exclude both. The same cross serves four-way and three-way junctions; leave an unused socket empty. Elbows are only at the four overall outside corners. Inner opening corners use crosses because their other two ports connect directly to the outer perimeter.

| Configuration | Printed pieces | PETG kg | Print hours | Plate runs | 10-ft PVC sticks / cost | PVC + PETG subtotal |
|---|---:|---:|---:|---:|---|---:|
| single | 64 | 2.528 | 102.2 | 23 | 8 / $48 | $98.57 |
| split_s | 104 | 4.031 | 163.3 | 36 | 14 / $84 | $164.63 |

Your PVC price is $6 per 10-ft stick. PETG is an assumed $20/kg, not a supplier quote. Subtotals cover the face skeleton only; magnets, paper, adhesive and a ground-support system are additional. Print estimates come from local Bambu Studio slicing: A1 Mini, 0.4 mm nozzle, 0.20 mm layers, Generic PETG, four walls, 20% infill, no supports, no brim. Failed prints and manual work are not included. Three 1-kg spools cover the single with 10% allowance; the double requires five spools (4.434 kg with 10% allowance).

This simplifies assembly and inventory but **does not lower the modeled material or printer time versus the previous corded version**. That single used 5 types, 62 pieces, 1.759 kg, 71.0 hours and six PVC sticks ($71.17 PVC + PETG). This single uses 3 types, 64 pieces, 2.528 kg and 102.2 hours ($98.57). Universal crosses print unused sockets at the perimeter, and straight seam links consume more PVC. In return there is no tying, cord routing, cord tensioning or special seam saddle.

## Geometry and connection details

Single outside dimensions: **2700 x 2700 mm**. Stacked: **2700 x 4790.4 mm**, before a base. Each opening is **1480.8 x 1480.8 mm**. All paper bands, including the shared divider, are **609.6 mm / 24 inches** wide.

The PVC axes sit **75 mm inside the paper boundary** and **24 mm behind its face**. Opposing pipe axes across a band are 459.6 mm apart. Each socket mouth is 65 mm from its fitting center, leaving the unused perimeter socket behind paper with 10 mm to spare. Pad centers offset 57 mm from pipe axes put magnets 18 mm inside the paper edges. The model checks every printed vertex in front projection and every front magnet center against the paper rectangles. PVC follows the same concealed grid. Structure may be visible from an oblique view.

Socket engagement is **30 mm**, against a stop **35 mm from the fitting center**. Nominal pipe OD is 33.4 mm. The provisional friction bore is **33.5 mm**; printed fit must be selected using real pipe. Nominal socket walls are 4 mm, central webs are 32 mm wide and 12 mm thick, and magnetic arms have 20 mm-wide continuous 3 mm flanges with thicker roots. The peaked roof is retained for support-free horizontal printing. Magnet windows alone retain the requested 0.4 mm skin.

MAG_SLEEVE engages 16 mm of pipe. Its friction fit locates the magnet and resists rotation; it has no separate fastener. Leave accepted sleeves on their marked pipes during transport. All three production meshes fit the A1 Mini. The largest is CROSS at 136.627 x 136.627 x 53.345 mm; supplied plates maintain at least 5 mm bed margin.

## First print and fit test

[FIRST_FRICTION_FIT_A1Mini_PETG.3mf](sliced/FIRST_FRICTION_FIT/FIRST_FRICTION_FIT_A1Mini_PETG.3mf): **126.20 g / 4.97 hours**. Five pieces: one 33.5 mm-bore ELBOW, full 30 mm-long FIT_333 / FIT_335 / FIT_337 coupons, and one optional PAPER_PAD. The three samples are 33.3 / 33.5 / 33.7 mm bores, ordered from front to rear on the right side of the plate. Label them before removing them. The coupons have no end stop; test 30 mm engagement. Their shape and print orientation match the sockets.

1. Measure and deburr an actual pipe offcut. Test each coupon by hand; choose the fit that seats the full 30 mm and releases deliberately while resisting pull-out and rotation. Do not hammer a tight sample onto the pipe. If none meets that behavior, revise the bore rather than accepting a loose or forced fit.
2. Test both elbow sockets to their stops, with a 30 mm insertion mark on each pipe. Check that the elbow stays square and its paper face stays flat. Repeat fitting and release at least 20 times; check for cracking, whitening, increasing looseness and movement past witness marks.
3. The supplied elbow and production files use 33.5 mm. If another sample fits better, regenerate with PVC_FIT_BORE set to that diameter and re-slice before production. Do not scale an STL; that also changes centers, magnet pockets and cut lengths.
4. Then print [CROSS_AND_SLEEVE](sliced/CROSS_AND_SLEEVE/CROSS_AND_SLEEVE_A1Mini_PETG.3mf): **146.39 g / 5.70 hours**. It tests all four socket directions and the shorter sleeve. A coupon result alone does not prove sleeve grip.
5. For a two-foot band demonstration, join the elbow to the cross with one **389.6 mm** pipe and place the sleeve at **194.8 mm from its cut end**. Orient both printed faces into the same plane. The elbow's outward pad and the cross's opposite-side pad span the paper band with 18 mm edge margins. Lay a 609.6 mm-wide paper strip over them and mark the 18 mm margins. Use six magnets for three grip sites, adding a short perpendicular pipe offcut to each fitting to test square alignment.
6. Bond rear magnets after checking polarity; let the adhesive cure. Test magnetic grip with the real paper, both a bare front magnet and the optional front pad. Pull/rotate the sleeve, flex the paper gently and repeat assembly. After that passes, build one short square grid cell (four 389.6 mm pipes, one elbow, three crosses) flat and check racking and joint withdrawal before producing the complete gate.

The fit and handling tests above are prototype checks, not a rated wind/load test. The first two test plates are separate from the production queue below; accepted production pieces from them can count toward the final BOM.

## Full production queue

| Recipe | Single runs | Double runs | Pieces/run | g/run | h/run |
|---|---:|---:|---:|---:|---:|
| ONE_ELBOW | 4 | 4 | 1 | 68.47 | 2.69 |
| ONE_CROSS | 12 | 20 | 1 | 132.59 | 5.07 |
| BATCH_MAG_SLEEVE | 6 | 11 | 7 | 96.74 | 4.46 |
| TAIL_MAG_SLEEVE_6 | 1 | 0 | 6 | 82.93 | 3.85 |
| TAIL_MAG_SLEEVE_3 | 0 | 1 | 3 | 41.50 | 2.07 |

Each CSV queue links to the corresponding prepared PETG 3MF. BATCH_MAG_SLEEVE holds seven identical sleeves; it is one part type. The six- and three-piece tails avoid overprinting. All plates passed the bed-clearance, non-overlap and support-off slicing checks. Open prepared 3MFs as projects and confirm your actual filament profile before printing. No job has been sent to a printer.

## PVC cuts and assembly

Only **two finished pipe lengths** are used: **389.6 mm** and **1560.8 mm**. The single needs **16 short + 8 long**; the double needs **24 short + 14 long**. Their respective center spacings are 459.6 and 1630.8 mm, because the two stop offsets add 70 mm. The longest loose pipe is 1.561 m.

The stock ledgers reserve 10 mm total end allowance per stick and 3 mm kerf per cut. Two long pieces cannot fit one 3048 mm stick, so eight long pieces require at least eight sticks; fourteen require fourteen. All short pieces fit alongside those long pieces. Label cuts using PVC_Cuts.csv; node coordinates and Assembly_Map.svg use the front view, measured from the bottom-left paper corner.

1. Print and qualify the selected fit, then cut, deburr and label all PVC. Mark 30 mm engagement at both ends. Mark sleeve stations from Sleeve_Positions.csv before covering the cut starts with fittings.
2. Slide **one sleeve onto each short pipe**, centered at 194.8 mm from its cut start. Put **four sleeves on each long pipe** at **291.16, 617.32, 943.48 and 1269.64 mm** from the cut start. Rotate them to the direction shown in Blender; their flat paper faces must be coplanar with the fitting faces. The sleeve positions are clear of every socket.
3. Work on a flat surface with all paper-facing surfaces down. Build each horizontal row from four nodes and three pipes in **short / long / short** order. The single has four rows at y = 75, 534.6, 2165.4 and 2625 mm. Only the ends of its bottom/top row use elbows; every other node is a cross. A node's unused cross socket simply stays empty.
4. Place four vertical pipes into each row, then press the next complete row onto them together, keeping the mating sockets aligned. Single vertical gaps use **short / long / short** pipes, from bottom to top. Seat all four connections evenly to their marks; avoid levering one partially engaged socket to close another. Check equal diagonals and coplanar paper pads as each row goes on.
5. Populate only the magnet pockets shown by Magnet_Positions.csv. The cross has four available pads for symmetry, but not all are used at every node. A straightedge across the fixed fitting pads helps clock the sliding sleeves; mark accepted positions on the pipe for repeat assembly.
6. Install the paper as described below. For transport, remove the paper and separate rows/long members as needed, pulling at socket bodies. Leave sleeves on their labeled pipes. Fully assembled horizontal rows are about 2.7 m wide, so remove an end stub or separate at an inner cross to remain within the earlier approximately 2.15 m transport size.

## Paper and magnets

Use untrimmed 609.6 mm roll width. Single: **two 2700 mm horizontal bars and two 1552.8 mm side inserts**. Double: **three 2700 mm bars and four 1552.8 mm inserts**. Each side insert overlaps a horizontal bar by **36 mm at each end**. Consumption is 8.5056 m per single or 14.3112 m per double: three singles or two doubles from a 100-ft roll, before cutting waste.

Lay horizontal bars first, then side inserts. Align paper edges 18 mm beyond the corresponding magnet centers. The straight short PVC links carry magnets along the overlap seams, so no suspended seam parts are needed. Use **72 magnet pairs / 144 magnets** for a single, or **116 pairs / 232 magnets** for a double, all 6 mm diameter x 2 mm thick. Long-span sleeve spacing is 326.16 mm; grip at that spacing needs testing with the actual roll.

The stack is **rear magnet -> 0.4 mm frame plastic -> paper -> bare front magnet**. Frame pockets remain 6.3 mm diameter and are rear-loaded. Secure rear magnets with a compatible adhesive; the pocket clearance is not a guaranteed press fit. Check polarity before bonding. Only populate selected pockets. The bare front magnets align directly with the fixed rear magnets. The existing PAPER_PAD is an optional handle/protector around a front magnet; it adds another 0.4 mm skin and is excluded from the BOM, mass and time totals.

## Extend to the two-level gate

Reuse **every existing pipe without cutting**, all 48 sleeves, all 12 crosses and all four elbows. Add **8 CROSS + 32 MAG_SLEEVE**, **8 short + 6 long PVC cuts**, and **44 magnet pairs / 88 magnets**. The additional PVC needs six more 10-ft sticks. Add one 2700 mm paper bar and two 1552.8 mm side inserts.

Lay the single frame flat and remove its paper. Detach its complete top horizontal row (both elbows, both crosses, all three pipes and their sleeves) from the four short verticals below it. Move that complete row upward to the new top height, y = 4715.4 mm. This preserves its populated magnet pads and sleeve directions together; label its new node positions using the double map.

Build a replacement all-cross row at the old top height, y = 2625 mm, using four new crosses and short / long / short pipes. It becomes the upper row of the shared divider. Add four long verticals to a second new all-cross row at y = 4255.8 mm, also using four new crosses and short / long / short horizontal pipes. Add four short verticals above it and seat the retained top row onto them. This accounts for all eight additional crosses, six long pipes and eight short pipes. No special divider fitting is required.

The divider's two pipe rows are y = 2165.4 and 2625 mm: **459.6 mm axis spacing**, supporting the same 609.6 mm band as every other border. Use the double assembly and magnet maps when relocating/populating magnets at the former top edge.
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

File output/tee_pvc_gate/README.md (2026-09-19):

# Accepted 33.5 mm bore / tees, top guy elbows and measuring tools

The user confirmed that the printed MAG_SLEEVE fits the purchased PVC perfectly on 2026-09-18. **33.5 mm is now the fixed design bore for every PVC interface in this iteration. The MAG_SLEEVE STL is byte-for-byte unchanged.** The deeper fitting sockets and workshop tools still need their first physical checks; no further bore-selection samples are included.
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

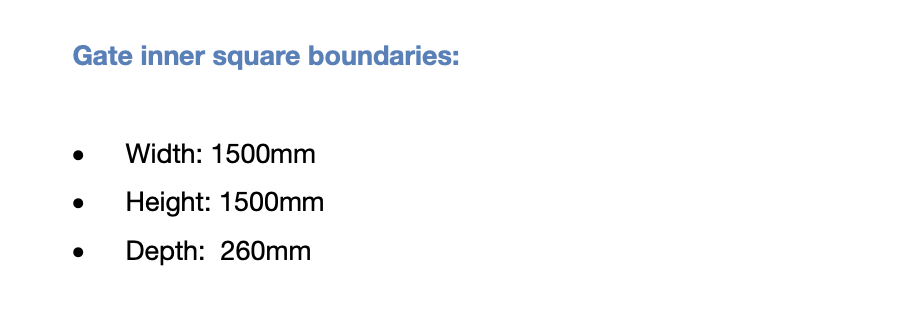
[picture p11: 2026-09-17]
Screenshot 2026-09-17 at 11.30.18 AM.png

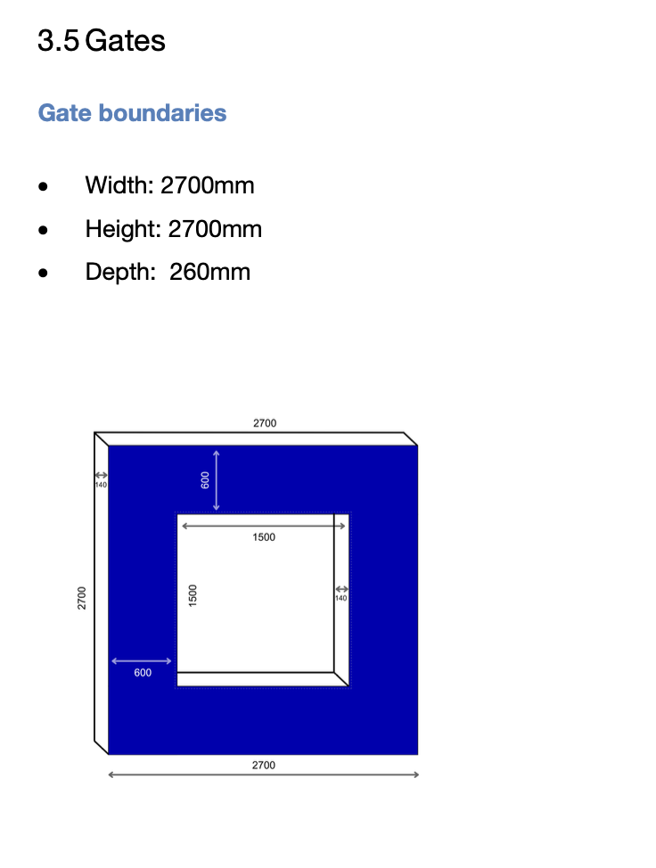
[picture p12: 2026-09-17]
Screenshot 2026-09-17 at 11.30.09 AM.png

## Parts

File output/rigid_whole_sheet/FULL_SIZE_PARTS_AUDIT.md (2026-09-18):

# Full-size rigid gate: parts and A1 Mini audit

Audited the saved Blender file, scene `01_RIGID_GATE`, at full size. Miniature geometry and repeated presentation scenes are excluded. The A1 Mini has a nominal 180 × 180 × 180 mm build volume ([Bambu specifications](https://us.store.bambulab.com/products/a1-mini?id=543566369394393101)). Bounds below are each object's unrotated envelope, sorted longest first; rails can be placed on their 10 mm spines.

**Result: the current full-size concept is not a complete printer-ready kit.** It has 11 modeled geometry variants, totaling 376 mesh objects intended to represent printed components or assemblies. This is not 376 production parts: node markers overlap, some boxes represent multi-part assemblies, and several interfaces are absent. Two rib variants do not fit the printer at all. All five supplied full-size *test samples* fit, but that does not validate every full-size component.

| Modeled type | Quantity per gate | Envelope, mm | A1 Mini assessment |
|---|---:|---|---|
| Long edge-channel segment | 120 | 142.84 × 10 × 6 | Fits; final end connections absent |
| Short edge-channel segment | 96 | 140.50 × 10 × 6 | Fits; final end connections absent |
| Long rear rib | 12 | 715.20 × 5 × 2 | **Does not fit** |
| Short rear rib | 12 | 562.80 × 5 × 2 | **Does not fit** |
| Workshop corner-node marker | 48 markers | 10 × 10 × 4 | Placeholder fits; not a physical node BOM |
| Paper keeper | 24 | 16 × 6 × 1.2 | Placeholder envelope fits; interface unfinished |
| Face docking receiver | 16 | 55 × 32 × 6 | Placeholder envelope fits; actual adapter unfinished |
| Permanent border splice bridge | 16 | 70 × 22 × 8 | Placeholder envelope fits; actual joint unfinished |
| Removable gate-corner bridge | 8 assemblies | 65 × 40 × 9 | Placeholder envelope fits; twin-runner bridge unfinished |
| Pipe-side docking assembly | 16 assemblies | 56.8 × 40 × 25 | Placeholder envelope fits; saddle, keeper and adapter need separate BOM |
| PVC brace-end clamp | 8 assemblies | 40 × 30 × 25 | Placeholder envelope fits; split clamp bodies/link need separate BOM |

Lengths of the two rail meshes are 0.2 mm shorter than their segment pitch, leaving a small splice gap: long edge pitch 715.2 / 5 = 143.04 mm; short edge pitch 562.8 / 4 = 140.70 mm. Two long edges and two short edges on each of twelve sheets give 12 × 2 × 5 = 120 long channel pieces and 12 × 2 × 4 = 96 short ones. Removable paper end-cap rails are included in these 216 pieces, not another twelve full-length printed bars.

## Missing details that change production quantities

- **168 channel splice locations:** each sheet has 2 × (5−1) + 2 × (4−1) = 14 intermediate channel joints. These need integrated joint ends or separate couplers. The sixteen large border splices do not account for these 168 rail joints. Separate couplers would add 168 parts, but integrated ends would instead change the rail geometry/type count.
- **Corner nodes are duplicated markers:** four markers per sheet create 48 boxes. Within four separate borders, there are only 32 distinct corner/junction positions: 16 end corners and 16 internal seam junctions. In the assembled gate four more positions coincide across separable borders, yielding 28 world-space centers. Those coincidences need proper adjoining geometry, not simply printing overlapping blocks.
- **Rear ribs need segmentation and junctions.** A possible pitch scheme is five long-rib pieces per bay (60 × 143.04 mm) and four short-rib pieces per bay (48 × 140.70 mm), all with 5 × 2 mm nominal section. This would turn 24 oversized ribs into 108 printable-length rib blanks and introduce 84 inline rib joints. It is a proposed scheme, not implemented manufacturing geometry; tongue/lap/sleeve allowances can change the lengths.
- **Twelve rear rib crossings** need a cross-junction or depth offset; the current two perpendicular solids overlap at each center. Endpoint attachments and the center crossing must be included in the final rib design.
- **Paper caps and keepers** still need release/retention interfaces and a defined part split.
- **Eight gate-corner bridges** need their mating receiver sets and latches specified; the simple bridge envelopes do not represent all constituent parts.
- **Sixteen PVC docking assemblies** need actual saddle-to-shoe adapters and positive mouth keepers; eight brace-end clamp assemblies need their separate bodies/links/retainers counted. Bounds of a schematic assembly are not proof that every finished support-free component fits.

Because these details affect material use, the previous 1.84 kg/two-spool estimate remains a preliminary allowance, not a verified total.

## Full-size STL samples actually checked

| Sample | Supplied print orientation bounds, mm | Volume fit |
|---|---|---|
| Straight U channel | 150 × 10 × 6 | Pass |
| Dovetail receiver | 50 × 25.4 × 7 | Pass |
| Dovetail shoe and release spring | 45 × 29.2 × 5.6 | Pass |
| PVC C saddle | 37.215 × 40.288 × 8 | Pass |
| Support rib blank | 150 × 5 × 2 | Pass |

These five files are 1:1 fit samples. Their quantities are chosen for testing; they are not five part types sufficient to manufacture the gate. Bounds were read directly from the binary STLs. Volume fit does not establish physical clearance, support-free print quality, stiffness or latch durability.

## Nonprinted materials

The face uses 12 uncut 22 × 28 in posterboard sheets. The backing uses 1-inch nominal PVC and 3/4-inch nominal PVC braces, commercial fittings, the earlier selected base/anchoring system and optional zip ties. The conceptual scene depicts eight half-members for the one square backing frame, four braces, four midpoint couplings, two legs and two short feet; fitting engagement, corner fittings, and the chosen grass/hard-surface base remain governed by the earlier build design. Scene lengths are not a new PVC cutting list. None of these purchased materials needs to fit a printer.

The JSON/CSV alongside this report preserve exact model counts and sample bounds. Audit reproduction: `blender -b output/rigid_whole_sheet/Rigid_Whole_Sheet_Gate.blend --python scripts/audit_rigid_gate_parts.py`.

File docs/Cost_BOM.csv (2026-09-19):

configuration | item | quantity | unit | unit_cost_usd | cost_usd
single | Black PETG | 2.32471 | kg | 9.8975 | 23.01
single | 6 x 2 mm magnets | 152 | individual | 0.0249875 | 3.8
single | 1 inch PVC | 8 | 10-ft stick | 5.34 | 42.72
split_s | Black PETG | 3.6913 | kg | 9.8975 | 36.53
split_s | 6 x 2 mm magnets | 240 | individual | 0.0249875 | 6.0
split_s | 1 inch PVC | 14 | 10-ft stick | 5.34 | 74.76

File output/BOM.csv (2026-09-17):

Item | Quantity | Unit | Assumed unit USD | Assumed total USD | Notes
Main Coroplast sheets | 2 | 4x8 ft 4 mm sheet | 30 | 60 | Four symmetric six-sided panels
Shared corner sheet allocation | 0.03125 | sheet | 30 | 0.9375 | 128 squares per sheet;4 per gate
1 inch Sch40 PVC | 4 | 10 ft stick | 13.5 | 54 | Single backing frame legs and short feet
3/4 inch Sch40 PVC | 1 | 10 ft stick | 10 | 10 | Four corner braces
1 inch elbows | 2 | each |  |  | Included in fitting allowance
1 inch tees | 4 | each |  |  | Included in fitting allowance
1 inch caps | 4 | each |  |  | Included in fitting allowance
All fittings allowance | 10 | each aggregate |  | 24 | Measure actual engagement
PETG prints | 1 | lot |  | 22 | 24 saddles;24 washers;4 plus45 and4 minus45 joints
UV ties and retaining screws | 1 | lot |  | 20 | 108 working ties plus spares;16 socket screws
Tape | 1 | share |  | 8 | Seam finish
Guy cord and adjustment | 16 | m |  | 12 | Four approximately4 m lines
Ground anchors | 4 | each | 5 | 20 | Verify actual holding
TOTAL ALLOCATED |  |  |  | 230.9375 | Before tax shipping labor tools and fill
FIRST GATE CASH |  |  |  | 260 | Includes whole third corner sheet with124 corners left over

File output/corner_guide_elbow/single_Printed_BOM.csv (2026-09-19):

part | quantity | description | print_bounds_mm
ELBOW | 2 | Two-port elbow for bottom outside corners; accepted 33.5 mm PVC bore; 30 mm engagement and 35 mm center-to-stop | 133.314 x 133.314 x 53.345
TEE | 8 | Three-way tee, native ports +X, +Y, -X; two magnetic pads on missing-port side; accepted 33.5 mm PVC bore; 30 mm engagement and 35 mm center-to-stop | 136.627 x 133.314 x 53.345
CROSS | 4 | Four-way cross for the inner grid intersections; accepted 33.5 mm PVC bore; 30 mm engagement and 35 mm center-to-stop | 136.627 x 136.627 x 53.345
DUAL_GUY_ELBOW | 2 | Top elbow with reinforced diagonal ear, two independent 10.5 mm front/back through-eyes and top/side/corner magnetic seats and recessed paper alignment L; accepted 33.5 mm PVC bore; 30 mm engagement and 35 mm center-to-stop | 168.614 x 168.614 x 53.345
MAG_SLEEVE | 48 | Universal friction sleeve with 57.0 mm offset magnetic face; no cleat, pin or cord eye; 16 mm pipe engagement | 20.0 x 86.75 x 53.345

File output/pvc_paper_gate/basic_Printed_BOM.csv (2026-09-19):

part | quantity | description | print_bounds_mm
OUTER_90_45 | 4 | 1-inch PVC 90-degree corner + inward 45-degree socket; 30 mm engagement; integral magnet lug and cord cleat | 122.0 x 122.0 x 53.84
EDGE_SLEEVE | 48 | One slide-on part for every straight edge; 14 mm engagement; offset magnet center 32 mm toward paper edge; cord eye clocks/locates clip | 20.0 x 62.3 x 52.709
INNER_90_45 | 4 | 1-inch PVC 90-degree corner + outward 45-degree socket; 30 mm engagement; integral magnet lug and cord cleat | 151.489 x 151.488 x 53.84
CORD_SADDLE | 8 | Small backing magnet on a seam cord; two fairleads; no printed spanning rail | 34.0 x 20.0 x 12.0

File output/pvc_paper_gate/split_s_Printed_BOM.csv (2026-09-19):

part | quantity | description | print_bounds_mm
OUTER_90_45 | 4 | 1-inch PVC 90-degree corner + inward 45-degree socket; 30 mm engagement; integral magnet lug and cord cleat | 122.0 x 122.0 x 53.84
STACK_TEE | 10 | Three coplanar 1-inch PVC sockets; 30 mm engagement; same tee rotates for all divider junctions; optional unused port in single-height gate | 160.0 x 122.0 x 53.84
EDGE_SLEEVE | 74 | One slide-on part for every straight edge; 14 mm engagement; offset magnet center 32 mm toward paper edge; cord eye clocks/locates clip | 20.0 x 62.3 x 52.709
INNER_90_45 | 4 | 1-inch PVC 90-degree corner + outward 45-degree socket; 30 mm engagement; integral magnet lug and cord cleat | 151.489 x 151.488 x 53.84
CORD_SADDLE | 16 | Small backing magnet on a seam cord; two fairleads; no printed spanning rail | 34.0 x 20.0 x 12.0

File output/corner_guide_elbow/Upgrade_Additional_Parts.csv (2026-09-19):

part | quantity
TEE | 4
CROSS | 4
MAG_SLEEVE | 32

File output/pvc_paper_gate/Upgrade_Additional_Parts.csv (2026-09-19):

part | quantity
STACK_TEE | 6
EDGE_SLEEVE | 32
CORD_SADDLE | 8

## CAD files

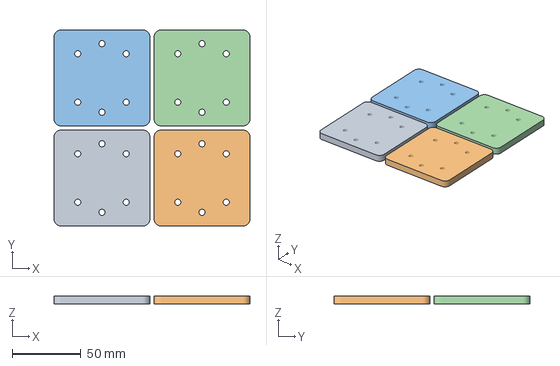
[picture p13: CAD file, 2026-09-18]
output/full_paper_gate/printable/Q_CROSS_PLATE_FULL.3mf
143.0 x 143.0 x 6.00 mm
CROSS_PLATE x 4

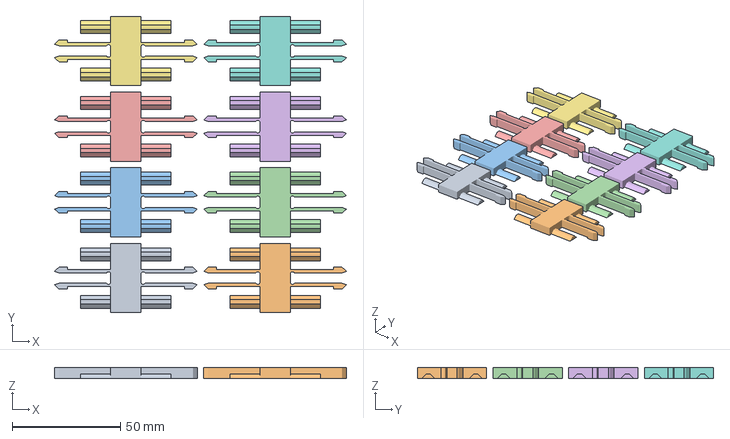
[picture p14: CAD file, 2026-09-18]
output/full_paper_gate/sliced/Q_CLICK_KEY_FULL/Q_CLICK_KEY_FULL_A1Mini_PETG.3mf
135.0 x 137.0 x 5.00 mm
CLICK_KEY x 8

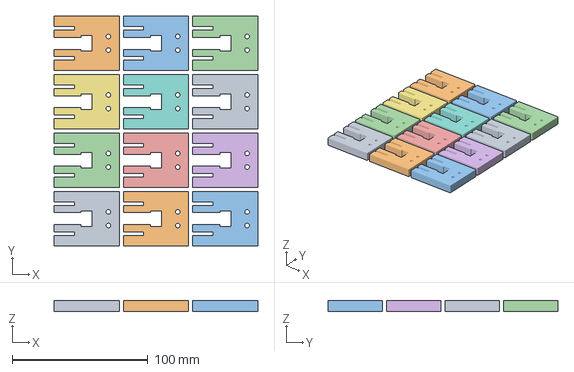
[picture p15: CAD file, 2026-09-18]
output/full_paper_gate/sliced/Q_DOCK_SOCKET_FULL/Q_DOCK_SOCKET_FULL_A1Mini_PETG.3mf
150.0 x 169.0 x 8.00 mm
DOCK_SOCKET x 12

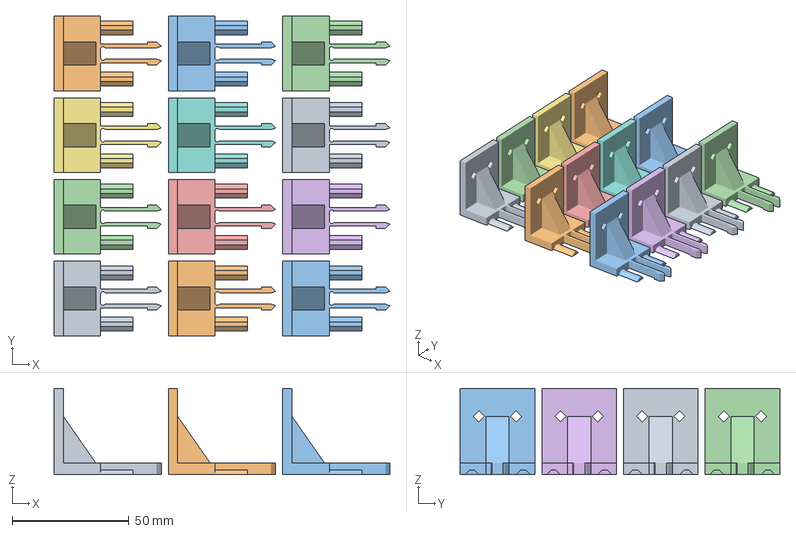
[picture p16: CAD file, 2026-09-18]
output/full_paper_gate/sliced/Q_DOCK_TONGUE_FULL/Q_DOCK_TONGUE_FULL_A1Mini_PETG.3mf
144.0 x 137.0 x 37.0 mm
DOCK_TONGUE x 12

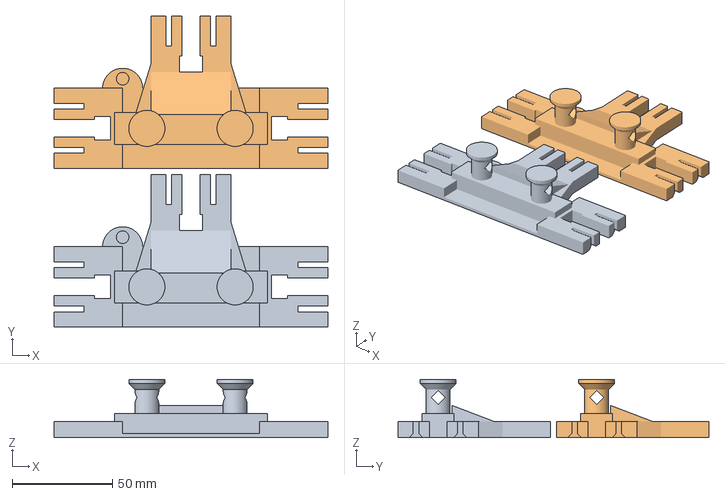
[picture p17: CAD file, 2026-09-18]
output/full_paper_gate/sliced/Q_EDGE_BRANCH_FULL/Q_EDGE_BRANCH_FULL_A1Mini_PETG.3mf
136.3 x 155.0 x 29.0 mm
EDGE_BRANCH x 2

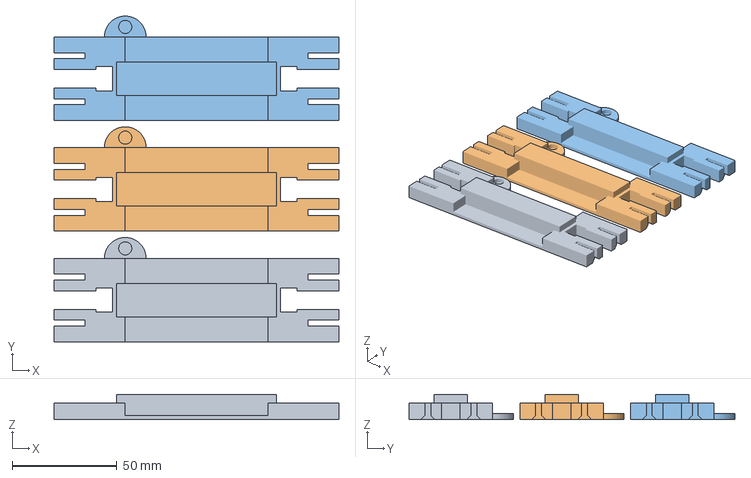
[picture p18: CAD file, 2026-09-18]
output/full_paper_gate/sliced/Q_EDGE_PLAIN_FULL/Q_EDGE_PLAIN_FULL_A1Mini_PETG.3mf
136.3 x 155.9 x 12.0 mm
EDGE_PLAIN x 3

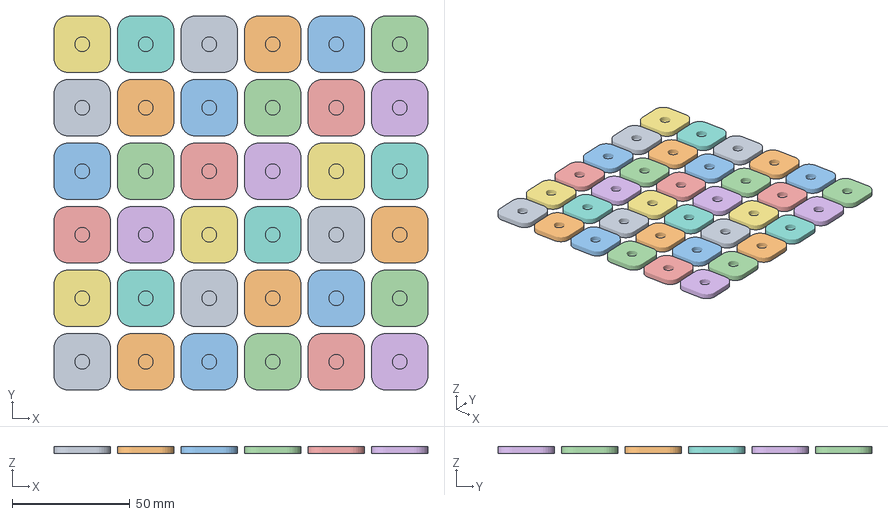
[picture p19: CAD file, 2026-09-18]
output/full_paper_gate/sliced/Q_PAPER_PAD_FULL/Q_PAPER_PAD_FULL_A1Mini_PETG.3mf
159.0 x 159.0 x 3.00 mm
PAPER_PAD x 36

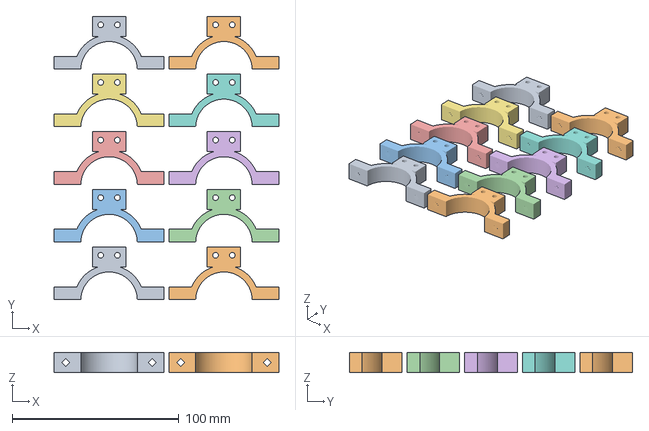
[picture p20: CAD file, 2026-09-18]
output/full_paper_gate/sliced/Q_PVC_HALF_33_FULL/Q_PVC_HALF_33_FULL_A1Mini_PETG.3mf
134.6 x 169.5 x 12.0 mm
PVC_HALF_33 x 10

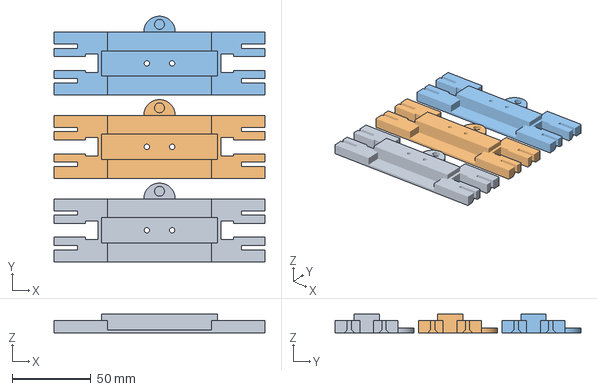
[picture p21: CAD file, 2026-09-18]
output/full_paper_gate/sliced/Q_RUNG_FULL/Q_RUNG_FULL_A1Mini_PETG.3mf
133.9 x 155.9 x 12.0 mm
RUNG x 3

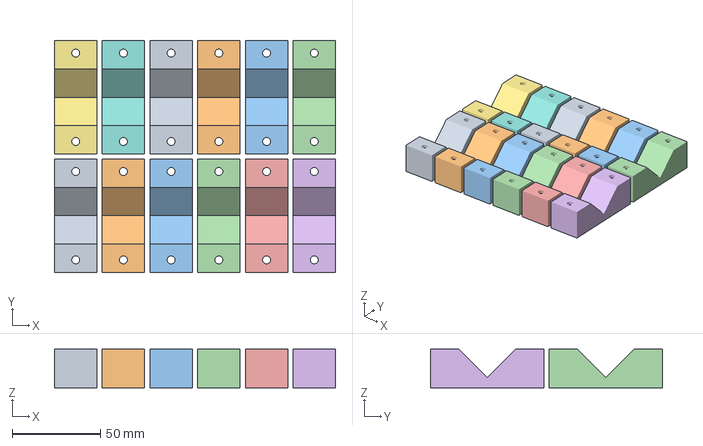
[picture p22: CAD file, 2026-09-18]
output/full_paper_gate/sliced/Q_V_BLOCK_FULL/Q_V_BLOCK_FULL_A1Mini_PETG.3mf
159.0 x 131.0 x 22.0 mm
V_BLOCK x 12

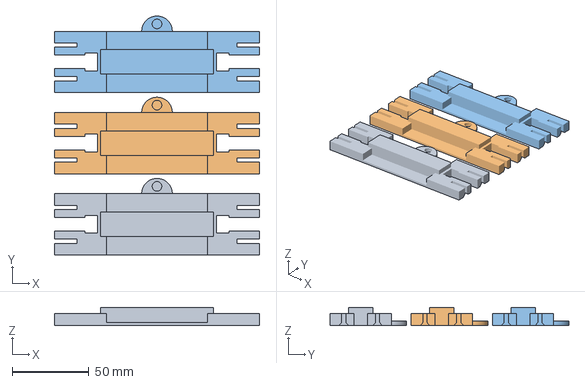
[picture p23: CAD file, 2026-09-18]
output/sleeve_paper_gate/sliced/Q_RUNG_FULL/Q_RUNG_FULL_A1Mini_PETG.3mf
133.9 x 155.9 x 12.0 mm
RUNG x 3

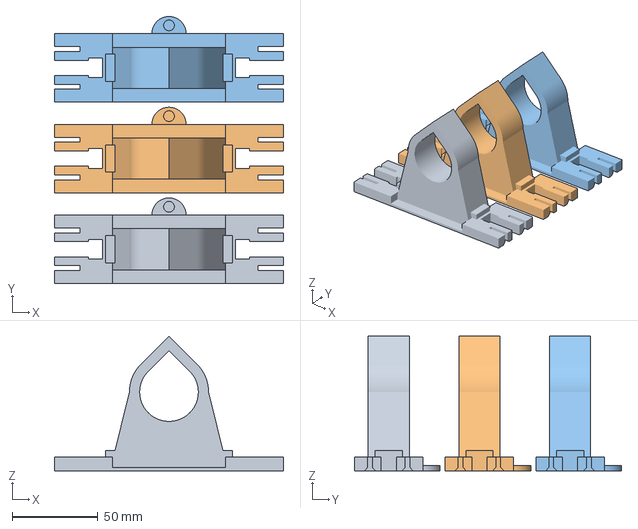
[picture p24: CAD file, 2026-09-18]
output/sleeve_paper_gate/sliced/Q_RUNG_SLEEVE_FULL/Q_RUNG_SLEEVE_FULL_A1Mini_PETG.3mf
133.9 x 155.9 x 78.7 mm
RUNG_SLEEVE x 3

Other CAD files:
output/full_paper_gate/sliced/Q_CROSS_PLATE_FULL/Q_CROSS_PLATE_FULL_A1Mini_PETG.3mf
output/sleeve_paper_gate/sliced/Q_CLICK_KEY_FULL/Q_CLICK_KEY_FULL_A1Mini_PETG.3mf
output/sleeve_paper_gate/sliced/Q_CROSS_PLATE_FULL/Q_CROSS_PLATE_FULL_A1Mini_PETG.3mf
output/sleeve_paper_gate/sliced/Q_EDGE_BRANCH_FULL/Q_EDGE_BRANCH_FULL_A1Mini_PETG.3mf
output/sleeve_paper_gate/sliced/Q_EDGE_PLAIN_FULL/Q_EDGE_PLAIN_FULL_A1Mini_PETG.3mf
output/sleeve_paper_gate/sliced/Q_PAPER_PAD_FULL/Q_PAPER_PAD_FULL_A1Mini_PETG.3mf
output/FPV_Gate_2700.blend
output/a1_full_size/A1_Full_Size_Gate.blend
output/a1_full_size/printable/BORDER_BRIDGE.3mf
output/a1_full_size/printable/BORDER_BRIDGE.stl
output/a1_full_size/printable/BRACE_LINK_45.3mf
output/a1_full_size/printable/BRACE_LINK_45.stl
output/a1_full_size/printable/CHANNEL_LONG.3mf
output/a1_full_size/printable/CHANNEL_LONG.stl
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

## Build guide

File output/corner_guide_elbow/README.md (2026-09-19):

# Three-magnet guy elbow / paper alignment guides

This iteration adds a corner magnet and shallow paper alignment grooves to the preceding [two-magnet dual-guy elbow](../dual_guy_gate/README.md). The earlier committed PVC/tee baseline is 6a7fb47. This is the current production-file revision; the sleeve fit is confirmed and full-gate tests remain outstanding.

[All five parts](renders/11_ALL_PRODUCTION_PARTS.png) · [Blender](Corner_Guide_Elbow.blend) · [Rendered views](index.html) · [Assembly PDF](Corner_Guide_Elbow.pdf) · [One-elbow PETG print](sliced/ONE_DUAL_GUY_ELBOW/ONE_DUAL_GUY_ELBOW_A1Mini_PETG.3mf)

## Three magnet positions

One 6 x 2 mm magnet now sits at the corner, **18 mm inside both paper edges**. The existing top and side magnets remain 18 mm inside their respective edge and 90 mm along it from the corner. Use three rear magnets and three opposing front magnets per elbow. Front paper pads remain optional.

The new seat is cut into the existing 32 mm-wide diagonal arm. Its **6.3 mm bore** retains a **0.4 mm plastic skin** facing the paper. A **10 mm rear access well** opens down to Z=2.6 mm; the 6.3 mm seat runs from Z=0.4 to 2.6 mm. The 2 mm magnet rests on the skin with its rear face at Z=2.4 mm. Insert it from the rear with a small nonmagnetic dowel, then use a small amount of suitable adhesive after checking polarity. There is no hole through the paper-side skin. The rear access well leaves nominally 11 mm of arm width on each side at its center section; the new pocket still requires a physical guy-load test.

Native CAD magnet centers are (-57,15), (15,-57), and (-57,-57) mm. The native paper corner is (-75,-75) mm, with paper extending toward +X and +Y. Installed at upper left, the new corner magnet is (18,H-18) mm from the paper's bottom-left; at upper right it is (2700-18,H-18). H=2700 single / 4790.4 stacked.

## Exact paper alignment

The paper-facing underside has a recessed **L-shaped guide, 0.8 mm wide and 0.4 mm deep**, extending about 22 mm along each edge. Its centerlines are exactly X=-75 and Y=-75 mm. Their intersection is the intended paper corner. Align the paper edges to the **middle of the grooves**, not their inside or outside walls. The outer half of each groove remains visible beside correctly aligned paper. The marks locate the local corner and edge directions; they are not full-length cutting guides.

The orange guide color in the paper-face render illustrates optional marker rubbed into the actual groove floors; the printable file is a single PETG part. The guide is recessed so the paper can sit flat. It does not cut across a magnet skin or either guy hole. With the supplied face-down print orientation, the 0.8 mm grooves require small bridges; the supplied slice generates them without supports. Actual first-layer squish can soften these fine marks, so inspect them on the first print. Optional contrasting marker rubbed into the recess improves visibility without adding a ridge.

## First print and assembly check

1. Print **one** elbow using the supplied A1 Mini PETG 3MF, 0.4 mm nozzle, 0.20 mm layers, four walls and 20% infill. Use the supplied orientation. The guides are on the bed-facing surface; flip the finished part over to see them.
2. Inspect the recessed L and all three 0.4 mm magnet skins. Fit the purchased PVC into both **33.5 mm** sockets, using full 30 mm insertion and witness marks. The successfully printed sleeve bore is preserved; this elbow's socket fit still needs checking.
3. Check all magnet polarities. Lower the new corner magnet through its access well into the smaller seat using a nonmagnetic dowel. Inspect the seat before bonding. Install the other two backing magnets as before.
4. Place the paper corner at the intersection of the guide centerlines. Align both edges with the groove centerlines, and attach the corner front magnet first. Then attach the top and side front magnets. These are three separate magnet pairs.
5. Attach separate front and rear guys through the two 10.5 mm eyes. They remain outside the paper outline, with no paper notch required. Check the actual knots or loops with paper and all magnets fitted.
6. Check both guys separately and together while supporting the corner. Inspect the diagonal arm around the new access well, the groove intersection, and pipe witness marks for cracking, permanent deformation or socket withdrawal. No eye or wind load rating has been established.

## Print estimate and full-gate effect

One revised elbow: **103.06 g PETG / 239.68 minutes** (about 4 hours). Dimensions remain **168.614 x 168.614 x 53.345 mm**, fitting the 180 mm A1 Mini with at least 5 mm layout margin. The slice has no warnings and no generated supports.

Compared with the preceding two-magnet elbow: **+0.49 g / +2.91 minutes per elbow**. Cutting a hole can slightly increase sliced material because the new hole adds perimeters. Two elbows per gate add **four individual magnets** (two additional pairs).

Single gate: **76 pairs / 152 individual magnets**, **2.325 kg PETG / 94.46 print-hours**. Stacked: **120 pairs / 240 individual magnets**, **3.691 kg / 150.37 hours**. All other STLs, PVC cuts, paper cuts, node positions and production counts remain unchanged. The exposed guy ear still reaches about 28.6 mm beyond adjacent paper edges.

| Part | Single | Stacked |
|---|---:|---:|
| ELBOW | 2 | 2 |
| DUAL_GUY_ELBOW | 2 | 2 |
| TEE | 8 | 12 |
| CROSS | 4 | 8 |
| MAG_SLEEVE | 48 | 80 |

| Recipe | Single runs | Stacked runs | g/run | h/run |
|---|---:|---:|---:|---:|
| ONE_ELBOW | 2 | 2 | 68.47 | 2.69 |
| ONE_TEE | 8 | 12 | 98.49 | 3.77 |
| ONE_CROSS | 4 | 8 | 132.59 | 5.07 |
| ONE_DUAL_GUY_ELBOW | 2 | 2 | 103.06 | 3.99 |
| BATCH_MAG_SLEEVE | 6 | 11 | 96.74 | 4.46 |
| TAIL_MAG_SLEEVE_6 | 1 | 0 | 82.93 | 3.85 |
| TAIL_MAG_SLEEVE_3 | 0 | 1 | 41.5 | 2.07 |

Full queues count from zero. Count the sleeve already printed toward the BOM. Prepared files do not submit a job to the printer.

## Current material costs

Using the owner's approximate purchase prices (4 kg black PETG for $39.59, 800 magnets for $19.99, and 10-ft PVC sticks at $5.34), priced materials are **$69.53 single / $117.29 stacked**. This counts sliced PETG consumption, the individual magnets used and all required PVC stock including offcuts. Paper, guy lines, anchors/ballast, adhesive, electricity, failed prints, tax and shipping are excluded. See the [project README](../../README.md) for full costs and pack-purchase totals. Prior iteration guides retain historical prices.

## License

Original designs and documentation: **CC BY-NC-SA 4.0**, https://creativecommons.org/licenses/by-nc-sa/4.0/ . Credit Robert Boyd (@rboyd), link the project and license, identify changes, and use the permitted ShareAlike terms for shared adaptations. Commercial use of protected material requires separate permission. Source scripts use **PolyForm Noncommercial 1.0.0**. Third-party components retain their own terms. See [scope and commercial permissions](../../LICENSING.md) and the [full design license](../../LICENSE).

## Verification

Connected manifold geometry, plate bounds and clearances, support-free slicing, unchanged non-elbow STLs, aligned magnetic pockets, exact production counts and Split-S reuse checks pass. Ray probes of the actual mesh verify the groove floors at Z=0.4 mm, adjacent face at Z=0, magnet seat floor at Z=0.4 and access-well shoulder at Z=2.6. The prior 3 mm cord routing still clears the modified mesh and the paper. This checks geometry, not physical strength or printer accuracy.

The full assembly follows the preceding dual-guy guide, substituting this elbow and adding its corner magnets. The complete top row can still be moved upward for Split-S. See the updated CSVs for complete counts and magnet positions. Rebuild with build_corner_guide_elbow.py, slice_corner_guide_elbow.py, validate_corner_guide_elbow.py and package_corner_guide_elbow.py in scripts/.

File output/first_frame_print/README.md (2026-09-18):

# First frame print: one A1 Mini plate

Print [FIRST_FRAME_TEST_A1Mini_PETG.3mf](sliced/FIRST_FRAME_TEST/FIRST_FRAME_TEST_A1Mini_PETG.3mf): **four pieces, 80.14 g PETG, about 3 h 20 min**. This is the recommended first run. All parts are full-size production geometry, identical to the current sleeve-gate STLs.

[Illustrated assembly and test PDF](First_Frame_Test.pdf) · [Blender scenes](First_Frame_Print.blend) · [Visual index](index.html) · [Complete test kit](First_Frame_Print_Kit.zip)

| Part | Quantity | Dimensions mm | Purpose |
|---|---:|---|---|
| EDGE_BRANCH | 2 identical | 136.314 x 76 x 29 | Test both end and projecting side receivers |
| CLICK_KEY | 2 identical | 66 x 32 x 5 | One connects the rails; one spare/comparison |
| PAPER_PAD | 0; optional 1 | 24 x 24 x 3 | Optional comparison of paper clamping methods |

The first two rows are the entire recommended print: **two unique types**. The spare key is useful if a hook breaks during testing. Straight and T configurations each use two rails and one key; assemble them one at a time. No magnets, cord, PVC, bolts or adhesive are needed for the click test.

## Optional paper-pad plate

Use [FIRST_FRAME_TEST_WITH_PAD_A1Mini_PETG.3mf](sliced/FIRST_FRAME_TEST_WITH_PAD/FIRST_FRAME_TEST_WITH_PAD_A1Mini_PETG.3mf) instead if you also want the pad: **five pieces, 81.63 g, about 3 h 24 min**. Choose one of the two files, not both. The optional pad adds 1.49 g and approximately 3.6 minutes. The frame-side magnet holders are unchanged: the rear magnet stays behind 0.4 mm of plastic. The PVC sleeve retains its peaked roof and is not needed on this first plate.

## Print settings and placement

Open the prepared 3MF as a project in Bambu Studio. Select your actual PETG filament and A1 Mini with 0.4 mm nozzle. The supplied slice uses Generic PETG, 0.20 mm layers, four walls, 20% infill, textured PEI, no supports, no brim, and print by layer. Print one color; render colors only distinguish the parts. The smooth paper faces lie on the bed, with cleat posts upward. Keep the supplied flat orientation and 100% scale. Re-slice if you change filament/profile settings.

The models keep at least 5 mm from every bed edge and have no overlap; maximum height is 29 mm. The keys are rotated 90 degrees within the bed plane, not stood on edge. The tightest model-to-model gap is 1.69 mm; keep print-by-layer rather than sequential object printing. Both variants slice without warnings or support toolpaths. Estimates are from the local Bambu Studio slice; actual filament and elapsed time can vary. No print was sent to the printer.

## 1. Prepare the parts

Let the bed cool and remove the parts. Check for strings or first-layer burrs in the receivers and between the key's two central spring prongs. Remove loose strings/burrs only; do not file away the hook shoulders or thin the prongs to force a fit. Keep the second key untouched as a comparison. Record filament, temperature and any cleanup needed.

## 2. Assemble a straight joint

Place both rails smooth-face down with their side branches pointing the same direction. Align one end of a key with an end receiver. Slide it along the rail axis: its two broad outside runners guide it while the two narrow central prongs flex inward. Keep it flat; do not insert downward from above. Hold close to the joint and press until both hook shoulders have passed the receiver shoulders and returned outward. Check engagement visually; a loud click is not required.

Slide the second rail onto the other half of the key in the same way. The assembled length is 286.63 mm. Both paper faces should share the same plane. Apply a gentle axial hand pull and check that the rails remain latched. Check for obvious looseness and small bending movement while supporting the parts near the joint. Stop if you see whitening or cracking; this is a fit test, not a destructive strength test.

## 3. Release and rebuild as a T

From the open rear of the receiver, press both central hook tips toward the center and slide the rail straight off that end of the key. Release the other end the same way. Do not twist the rail, pry the key upward or bend the whole rail as a lever. If the tips cannot be reached and released comfortably by hand, record that as a design failure rather than forcing the joint.

Insert the same key into one rail's projecting side socket. Connect an end of the other rail to the exposed key at 90 degrees. Keep both smooth faces coplanar. This tests the full gate's actual crossmember interface, although the short test uses a second branch rail in place of a full crossmember. Repeat the pull, play and release checks.

## 4. Repeat and report

Aim for 20 assembly/release cycles in each configuration as an initial screening test. Try the spare key too. Check that both hooks spring back and latch, hand release remains practical, and no new cracks, permanent bending, whitening or increasing play appear. Twenty cycles is a workshop screen, not a fatigue rating. Record which receiver (end or side) is tight/loose, whether one key differs, and photographs of the latch if it fails. Do not scale the whole part to tune clearance; revise the interface after the physical test if needed.

## Optional magnet comparison

Add two 6 x 2 mm magnets and an offcut of the intended paper. Seat one rear magnet in a rail's 6.3 mm pocket, with compatible retaining adhesive if required, observing its cure time. Check attraction before fixing either magnet. The two alternatives are:

- No pad: rear magnet -> unchanged 0.4 mm frame plastic -> paper -> bare front magnet.
- Optional pad: rear magnet -> unchanged 0.4 mm frame plastic -> paper -> 0.4 mm pad plastic -> front magnet in pad.

Use the same front magnet for successive comparisons before bonding it into the optional pad, or use a third magnet to keep both options ready. Compare sliding, peeling, paper marking and ease of removal. The pad spreads contact across a larger area and is easier to handle, but adds a plastic gap. The small plate only tests local grip, not retention of a full paper border.

## After the click test passes

Next print one production RUNG_SLEEVE to test actual PVC fit, then the 609.6 mm-wide braced bay in the [full gate guide](../sleeve_paper_gate/README.md). The four pieces here can be reused; deduct them from the later queue. This plate demonstrates joinery at 1:1 scale; it is not a complete two-foot-wide frame or a wind test. Physical fit, strength and durability remain unverified until you print it.

The current gate BOM and queue label PAPER_PAD as optional: 424 pieces / seven types without pads, or 560 / eight with all 136 pads fitted. All frame-side magnet holders and the peaked sleeve roof remain unchanged.

Rebuild in the repository with scripts/build_first_frame_print.py, scripts/slice_first_frame_print.py, then scripts/package_first_frame_print.py. The build imports the existing production geometry and asserts that its STL exports match the full gate byte-for-byte.

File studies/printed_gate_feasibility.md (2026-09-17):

# Printed PVC-mounted FPV gate: first-pass material study

2026-09-17. Existing symmetric Coroplast design is committed at `a584819`; the working tree was clean when this study began. No gate geometry or fabrication files have been changed for this study.

**Finding:** a modular printed face is possible in principle, but one or two 1 kg spools cannot make a convincingly rigid, closed replacement for the current broad face. A very open lattice is the promising low-filament option: approximately **3 spools for a face with its new clips/joiners**, or **3–4 spools as an initial whole-gate printed-parts budget** while retaining the PVC. Strength and visibility remain untested.

## Scope and arithmetic

Keep the existing 2700 × 2700 mm outer dimension, 1500 × 1500 mm opening, single PVC backing square, corner braces, feet and anchoring. “Entirely printed” means the visible face and its connectors replace Coroplast; it does not mean printing the PVC or ballast.

Projected face area = 2.7² − 1.5² = **5.04 m²**. This counts one sheet area, not both exposed surfaces. Bambu PETG HF density is **1.28 g/cm³**. A spool is assumed to contain **1000 g of filament**, excluding the empty spool. PETG is the study material; changing to PLA would not deliver the several-fold weight reduction needed. [Manufacturer density](https://eu.store.bambulab.com/en-mt/products/petg-hf?variant=49068714557788)

**Face mass (kg) = 5.04 × solid-equivalent thickness (mm) × 1.28 = 6.4512 × thickness.**

One spool contains 781.25 cm³, enough for only **0.155 mm** over the whole face. Two spools give **0.310 mm**. These are theoretical sheets without edges, ribs, joins, clips, waste or retained brace connectors. A 0.2 mm face is a single-layer film at a 0.2 mm layer height; a 0.4 mm face is only two layers. Neither is an established durable gate panel.

| Construction | Face plastic | Minimum whole 1 kg spools | Spool purchase at assumed $20/kg |
|---|---:|---:|---:|
| 0.2 mm film | 1.29 kg | 2 | $40 |
| 0.4 mm thin sheet | 2.58 kg | 3 | $60 |
| 0.8 mm sheet | 5.16 kg | 6 | $120 |
| 1.0 mm sheet | 6.45 kg | 7 | $140 |
| 4 mm sandwich: two 0.4 mm skins, 10% of remaining core | 7.23 kg | 8 | $160 |
| 4 mm solid | 25.80 kg | 26 | $520 |

**Table excludes tile sidewalls, connectors, PVC clips, retained brace joints, purge, brims and failed prints.** $20/kg is a planning assumption, not a live offer; multiply costs by 0.75–1.25 for $15–25/kg. Electricity, printer wear and labor are excluded.

“10% infill” does not mean 10% of an entire closed plate. The two skins alone in the sandwich consume 5.16 kg, before its 2.06 kg core and any perimeter walls. This illustrative sandwich is not a slicer prediction or a printable bridge design. Standard 4 mm Coroplast is corrugated, not a solid 4 mm slab; the 25.8 kg example is deliberately the solid-print upper comparison, not an estimate of Coroplast weight.

## Open-lattice alternative

Use 150 × 150 mm module pitch. The gate is an **18 × 18 grid with a 10 × 10 central hole: 224 modules**. A flat module plus compact connectors fits within the A1 Mini's 180 × 180 mm plate; only one such tile fits flat per plate. Integrated tabs would need to remain within about 170 × 170 mm to leave brim space. [A1 Mini specifications](https://cdn1.bambulab.com/documentation/quick-start-f507128172bdf/Quick%20start%20guide%20-%20A1%20mini-EN.pdf)

An arithmetic example uses each tile's own 2 mm-wide perimeter plus two crossing 2 mm-wide ribs, all **3 mm deep**. It has four open windows. Its projected plastic area is 1764 mm² out of 22500 mm²: **7.84% plastic, 92.16% open**. Adjacent tile borders are counted twice, so the calculation does not hide the weight of duplicate seam rails.

- Bare lattice face: **1.517 kg**, about 6.77 g per tile.
- Allow **0.50 kg** for new joining features/keys and PVC mounting clips; this is a design allowance, not modeled hardware.
- Add 10% for brims, purge and waste: **2.219 kg**, requiring **3 spools / $60** at the assumed price.
- If also printing the existing eight brace connectors from scratch, their *solid CAD volume* adds about **0.646 kg PETG** before waste. Total becomes about **2.93 kg** with the same waste allowance: three spools is tight, so **3–4 spools / $60–80** is a more useful first-build budget. Actual infill/perimeters and supports must be sliced later. Current face saddles/washers are replaced by the new clip allowance, not counted again.

At a 3 mm lattice depth, reserving 0.50 kg for new joints/clips and 10% waste limits coverage to about **2.1% for one spool**, **6.8% for two**, or **11.5% for three**, before the retained brace connectors. Thus two spools could be a target only for a lighter, sparser face with very efficient joints; one spool is an extreme skeleton or a narrower-border concept. Neither is a proven equivalent to the current gate.

A 92%-open face will look much less solid through FPV goggles. It would likely reduce wind loading, but the reduction cannot be treated as equal to the open-area fraction without testing. Thin ribs and snap roots also need impact and repeated assembly tests. A narrow, strongly colored outline could be a different low-material direction, but it changes the current 600 mm border requirement.

## What the parts could look like

See `printed_gate_concept.svg`: a schematic, not fabrication geometry.

1. **Standard tile:** flat square perimeter with open windows/cross ribs; alternatively a thin face skin on a shallow rib frame. Recessed edge sockets keep the tile pitch consistent. The four-tile border is 600 mm wide. No special diagonal corner panels are needed on this square grid.
2. **Replaceable click key:** short bowtie/dovetail-shaped bridge with a spring detent. The dovetail carries in-plane load; the detent retains the key against falling out of the vertical gate. Give it a release tab so broken parts can be replaced.
3. **PVC mounting clip:** split C-shaped saddle around the actual **33.4 mm OD** main pipe, with a locking latch and a flat dovetail/tab that mates with a tile's reinforced rear boss. Mounting tiles transfer load directly to PVC. A backup tie slot could retain a clip if the latch wears.
4. **Optional edge insert/cap:** smooths exposed sockets on the inner opening and outer perimeter; included in the connector allowance, not a dimensioned part yet.

The referenced Clickfinity implementation uses flexible latch tongues for bins and separate bowtie keys between plates. Its keys are retained by the supporting bench; a vertical, vibrating gate would need its own positive key retention. We can borrow the modular joining idea, not assume a desktop organizer joint is adequate for this gate. [Clickfinity implementation and joining mechanism](https://github.com/IamMrCupp/clickfinity-openscad/blob/main/README.md)

There are **392 neighboring tile seams**, potentially two locks per seam. Together with **224 flat tile print jobs**, that is a substantial assembly and printing commitment even if the filament price is competitive. Multi-part plate strategies or printing orientations could be examined later; no print-hour estimate is claimed here.

## Decision before detailed design

For a closed face, expect roughly **7–10+ spools** once reasonable thin skins, connections and retained brace joints are counted, depending on thickness and construction. For an open face, **3–4 spools** is a plausible material budget worth testing, not a strength promise. The current Coroplast face stock is about **$60.94 per gate** at batch allocation, so printed lattice material is in the same price region but entails far more printer/assembly time and lower visual coverage.

The next useful step would be two joined lattice tiles and one PVC clip to test snapping, flex, visibility and actual slicer mass. A full 224-tile design should follow those results. This study deliberately stops before that design stage.

Recalculate with `python3 studies/estimate_printed_gate.py`. CSV/JSON retain all assumptions and arithmetic.

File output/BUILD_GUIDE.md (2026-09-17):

# FPV gate — symmetric panels and square corners

**Current iteration:** four identical mirror-symmetric, six-sided Coroplast panels, four **150 × 150 mm square** corner infills, and one 1-inch PVC backing frame with four ¾-inch corner braces. Two 8 × 4 ft sheets supply the four main panels and all reinforcing backers/pads. The third sheet supplies 128 squares, enough for **32 gates**. Both base configurations and all eight printed brace-end connectors remain.

The prior triangular-corner single-frame design is committed as **55f2808**. This iteration is on `iteration/symmetric-square-corners`. The main panel resembles a stretched home plate at both ends: it has six sides so the left and right cuts match exactly. It is symmetric about its short centerline, not its long centerline.

Open `FPV_Gate_2700.blend`: ten scenes show assembly, rear structure, exploded layers, cutting layouts, saddles, dimensions, hard-ground base, brace joints, separated face pieces, and A1 Mini cutting jigs. `START_HERE.html` is the visual index.

This is a digitally checked prototype. Physical print fit, fastening strength, sheet stiffness and wind/base performance still need a first-build test. No wind rating is asserted.

## Geometry

| Feature | Size |
|---|---:|
| Outer face | 2700 × 2700 mm |
| Clear front opening | 1500 × 1500 mm |
| Border | 600 mm |
| Main panel blank | 2400 × 600 mm |
| Corner infill | Square, 150 × 150 mm |
| Sheet thickness | 4 mm assumed |
| Single PVC backing frame centerlines | 2100 × 2100 mm |
| Body thickness, including face fasteners and brace ties | About 96 mm; excludes feet and guys |
| Main frame / corner braces | 1 inch / ¾ inch Schedule 40 |
| Face clearance above ground | 50 mm |
| Overall height above ground / opening bottom | 2750 / 650 mm |
| Grass foot pipe span | 1200 mm, plus caps |
| Hard-surface foot pipe span | 2400 mm, plus caps |

The screenshots specify 2700 outer, 1500 inner and 260 mm depth. Your latest instruction removes the second square frame and depth links: this revision deliberately has a **shallow single backing frame, about 96 mm thick including fasteners**, rather than a 260 mm body. The 2700 mm face and 1500 mm opening dimensions are retained. There are no solid tunnel walls or rear face.

Datum: face X = −1350…1350, Z = 0…2700, Y = 0…4 mm. Opening X = −750…750, Z = 600…2100. Y increases rearward. Ground is Z = −50. The feet pass below the face instead of through notches in it. Foot and anchor footprints extend beyond the shallow gate body.

## Symmetric face cuts and the 8-foot limit

Stock is nominally **2438.4 × 1219.2 mm**. Cut two **2400 × 600 mm** blanks from each of two sheets. All four panels use these vertices, measured from the lower-left blank corner:

**(0,600), (2400,600), (2400,450), (1950,0), (450,0), (0,450).**

Remove two matching **450 × 450 mm right triangles**, one from each lower corner. Each end has a 150 mm straight shoulder and a 45° cut. The continuous inner edge is 1500 mm; the outer edge is 2400 mm. Rotate the four completed panels through 90° around the opening. The four outside gaps are exactly **150 mm squares**; each contributes 150 mm to the 2400 mm panel span, reaching 2700 mm overall.

Each main panel is 1.2375 m² and each square is 0.0225 m². **4 × 1.2375 + 4 × 0.0225 = 5.04 m²**, the exact ring area. The polygon checks verify coverage, symmetry and absence of overlap, as well as stock nesting.

### Shared corner sheet

Use a **16 × 8 grid of 150 mm squares** in a 2400 × 1200 mm area: **128 squares = 32 gates**. Remaining stock margins are 38.4 mm and 19.2 mm. Knife cuts assume negligible kerf; allow for saw kerf if changing tools.

For N gates, purchase **2N + ceil(N/32) sheets**, before spares. A single gate still requires three purchased sheets; 124 squares remain. A batch of 32 gates requires 65 sheets. Full-batch allocation is **2.03125 sheets per gate**. Corners intentionally come from the shared third sheet; the triangular offcuts are allocated to reinforcement.

## Backers and pads from the eight identical offcuts

| Part | Quantity | Size | Function |
|---|---:|---|---|
| B1 | 4 | 350 × 80 mm | Supports the main diagonal panel seam |
| B2 | 4 | 220 × 220 mm | Supports both square-infill seams and the three-piece junction |
| A-pad | 24 | 70 × 50 mm | Reinforces the face saddles |
| Front spreaders | 56 used, 64 available | 25 × 25 mm | Two per seam stitch |

Use four 450-leg offcuts for B2, three saddle pads and eight small spreaders each. Use the other four for B1, three saddle pads and eight small spreaders each. The SVG and `face_geometry.py` provide exact nesting; every piece is verified inside its offcut with no overlap. B2 is cut from the right-angle corner; its far corner is 440 mm along the triangle's 450 mm sum limit. The B1 strip is centered at (170,170), oriented −45° inside its offcut.

At the top-right gate corner, B2 occupies **X=1090…1310, Z=2440…2660 mm**, centered at the three-piece junction (1200,2550). It backs 110 × 110 mm of the visible 150 mm infill, leaving 40 mm exposed border at the two outside edges. B1 is centered at **(925,2275)**, long axis +45°. The two backers do not overlap; their rear surfaces are Y=8 mm. Rotate this arrangement to the other corners.

Use **seven tie stitches per corner**: three along B1 at −120, 0 and +120 mm along its centerline; two across the vertical infill seam at Z=2580 and 2635; and two across the horizontal infill seam at X=1260 and 1295. All tie legs are 60 mm apart, 30 mm each side of the seam. Each front leg gets a 25 mm scrap spreader; punch through the face and backer together. Total seam ties: **28**. With 48 saddle ties and 32 brace-joint ties, there are **108 working ties**, plus base straps and spares.

Butt the front edges, lightly tighten ties without crushing the flutes, then tape the front seams. Place heads behind the face. Tape is a seam finish, not the sole joint. [Coroplast bonding guidance](https://www.coroplast.com/resources/)

## A1 Mini cutting and marking jigs

The A1 Mini's build volume is **180 × 180 × 180 mm**. All gate clips and the three new jigs fit individually. The largest jig is 155 × 155 mm; a 5 mm brim brings its footprint to 165 × 165 mm. [Bambu Lab A1 Mini quick-start specifications](https://cdn1.bambulab.com/documentation/quick-start-f507128172bdf/Quick%20start%20guide%20-%20A1%20mini-EN.pdf)

| STL | Envelope | Use |
|---|---|---|
| `jig_square_150_mm.stl` | 155 × 155 × 9 mm | Register two stock edges; mark a 150 mm square or a shoulder location |
| `jig_45_degree_mm.stl` | 150 × 150 × 9 mm | Register one stock edge; align a metal straightedge to 45° |
| `jig_tie_slots_60_mm.stl` | 80 × 40 × 3 mm | Align center notches to seam; mark two 4 × 6 mm tie slots, 60 mm apart |

Print the two registration jigs **flat with raised fences UP**, then flip them so their fences hang down over the sheet edges during use. The square jig's inside fence faces are 150 mm from its opposite outside edges; do not measure from the outer fence walls. Fences extend 6 mm below the contact plane, clearing a 4 mm sheet. Use the small tie template flat on top of the sheet. Printed apertures are marking guides, not drill bushings or enclosed blade slots.

Use PETG, 0.20 mm layers, four perimeters and about 20–30% infill as starting settings. They are reusable shop tools, not per-gate consumables. Budget an additional **$3–5 of filament once per crew**, pending slicing; print time is slicer-dependent. Do not scale the STLs to fit. Verify the 150 mm span with a steel rule, the 60 mm hole spacing, and the 45° jig by flipping it against a drawn reference line. Adjust dimensional compensation only after a calibration sample.

1. Support the entire sheet on a flat sacrificial board. Square a datum corner and verify real stock dimensions.
2. Measure the **600 mm widths and 2400 mm lengths with a steel rule/tape from the same datum**. Clamp a long metal straightedge for each cut. Do not accumulate four 150 mm jig steps to define 600 mm.
3. Mark 150 mm down from the outer edge at both ends and 450 mm inward along the inner edge. Confirm a 1500 mm inner span. The 45° jig helps set the ruler through both marks; clamp it, remove the printed jig, then cut the full 636.4 mm diagonal against metal. Reuse the same measured pattern for all eight cuts.
4. On sheet 3, mark absolute 150 mm grid coordinates from a single datum, then cut strips and squares. Use the square jig as a setup/check gauge; avoid cumulative indexing error.
5. Cut backers/pads to the SVG coordinates and use the tie template to mark stitches. Punch on a sacrificial board. Test assemble one corner before batch cutting the remaining stock.

The jigs make repeated setup easier; they cannot guarantee exact cuts independently of printer calibration, ruler alignment, sheet squareness or knife technique. They intentionally do not form a long segmented plastic knife rail.

## PVC structure

Use US **solid-wall Schedule 40** pipe. Nominal diameter is not outside diameter: 1 inch is **33.40 mm OD**, ¾ inch is **26.67 mm OD**. Those are the connector groove dimensions. The 1-inch section has about 2.36 times the bending second moment of the ¾-inch section; use it for the loaded front frame and feet. [Charlotte Pipe dimensions](https://www.charlottepipe.com/uploads/documents/technical/BR-PK.pdf)

The single 2100 mm backing frame uses 1-inch pipe. Its top corners use elbows and its lower corners use tees continuing down to the feet. Each of its four sides is now one continuous pipe: the midpoint reducing tees, connecting pipes, and rear square have been removed. Four short ¾-inch diagonal braces stiffen the corners, each joined by two of the existing printed 45° connectors.

The main frame pipe axis is Y ≈ **31.9005 mm**, set by the face/pad/saddle stack. Brace axes sit at Y ≈ **72.336 mm**; the furthest rear tie surface is near Y = 90 mm. Front spreaders/ties project a few millimetres ahead of the face, making overall body thickness approximately **96 mm**. The feet and guy lines are excluded from that dimension. The current geometry is measured in `validation.json`.

### Purchased fittings

- 1 inch only: **2 elbows, 4 tees, 4 end caps** — ten fittings total.

The Blender fittings are dimensional envelopes, not printable fittings. Pressure sockets may be tapered and may not dry-seat to their catalog stops. Measure repeatable actual engagement and mark it before cutting. Do not hammer a dry pipe to the stop.

### Cutting formula and example lengths

**Pipe cut = required fitting-center span − g at each end**, where **g = center-to-mouth − actual pipe engagement**. Do not subtract socket depth itself.

Catalog examples: the 1-inch 406-010 elbow and 401-010 tee each have G = **17.4625 mm**. These produce the full-seat examples below. Use actual measured engagement if it differs. [Charlotte fitting catalog, printed pages 31 and 36](https://www.charlottepipe.com/uploads/documents/technical/DC-PR.pdf)

| Part | Qty | Pipe | Example cut, mm |
|---|---:|---|---:|
| Horizontal rails | 2 | 1 inch | **2065.075** |
| Uprights | 2 | 1 inch | **2065.075** |
| Legs, 325 mm center span | 2 | 1 inch | **290.075** |
| Grass half-feet | 4 | 1 inch | **582.5375** |
| Corner braces | 4 | ¾ inch | **646** |
| Hard-surface half-feet, replace grass feet | 4 | 1 inch | **1182.5375** |

Each frame rail/upright is **2100 − 2 × 17.4625 = 2065.075 mm**. Shop precision of 0.1 mm is not required; the extra digits make the derivation reproducible. Cut against the actual fitting/centerline jig. If the previous half-pipes have already been cut, they cannot replace these continuous members without added couplers and recalculated engagement; the supplied revision assumes fresh continuous rails.

**Stock allocation:** buy **four 10-foot 1-inch sticks and one 10-foot ¾-inch stick** for the grass gate. Each 1-inch stick supplies one main rail/upright and one short half-foot. Sticks 1–2 also supply one leg each. Worst use including three 3 mm kerfs is **2946.7 of 3048 mm**, leaving about 101.3 mm. The ¾-inch stick supplies all four 646 mm braces; with four 3 mm kerfs this uses **2596 mm**. The hard-floor set adds **two** 10-foot 1-inch sticks, each yielding two 1182.5375 mm halves plus kerf, about **2371.1 mm** used.

Each working socket needs positive retention: a predrilled short stainless pan-head screw (e.g. #6 × ½ inch, chosen for actual fitting wall), pin, or correctly made permanent solvent joint. The fully removable prototype has **16 working socket interfaces**, plus the four low-load end caps. Do not rely on friction alone. Preassemble selected corner/foot modules in an alignment jig and retain transport joints with screws/pins to reduce field work. This is non-pressure structural use of plumbing components.

## Face-to-pipe saddles

Print **24 one-inch saddles and 24 front washers**. The open saddle is tie-retained; no spring snap carries the load. Print flat face down with no supports. Starting settings: PETG, 0.20–0.24 mm layers, four walls, five top/bottom layers, 25–30% infill. Four 0.4 mm extrusion lines are about 1.6–1.8 mm, not 3.2 mm. Use the filament maker's profile. PETG is a practical tough functional material; ASA is an outdoor alternative where the printer supports it. [Prusa PETG](https://help.prusa3d.com/article/petg_2059?product=mini), [ASA](https://help.prusa3d.com/article/asa_1809?product=mk3-5)

| STL | Qty | Geometry |
|---|---:|---|
| `saddle_1in_OD33p40_mm.stl` | 24 | 60 × 40 × 18 mm; groove OD 33.801 mm |
| `front_load_washer_mm.stl` | 24 | 60 × 40 × 2.5 mm |
| `optional_saddle_3_4in_OD26p67_mm.stl` | Optional | Not needed for the baseline face |

Stack: front washer → 4 mm face → 4 mm scrap pad → saddle → pipe. Use two 4.8 mm UV-rated ties per saddle, through matching **3.2 × 6 mm** slots. Slot centers are transverse ±23 mm and along-pipe ±10 mm. The 1:1 SVG is a drilling/slot template. Tie heads face rearward. Hand-tighten without crushing the flutes. Transfer slots through the sheet during fabrication; the large-sheet model does not subtract every field-made hole.

Positions relative to face datum:

- Horizontal pipe at Z = 300 and 2400: X = **−840, −500, −160, 160, 500, 840 mm**.
- Vertical pipe at X = ±1050: Z = **450, 850, 1150, 1550, 1850, 2250 mm**.

These positions clear the brace connectors and maintain distributed face support. Print one complete saddle/washer pair and test on actual pipe and sheet before producing the batch. Cut Coroplast front spreaders can substitute for printed washers to save printing time, but maintain the same broad load distribution.

## Printed joints at both brace ends

Each brace crosses the frame **400 mm from its corner**. Its two crossings are 400 × 400 mm apart, so the centerline span is 565.7 mm. A 646 mm pipe leaves about 40 mm beyond each connector center.

Print **four +45° and four −45° joints**. Each single printed body is **60 × 60 × 24 mm**, with a 33.801 mm groove on the main-pipe side and a 27.07 mm groove on the opposite brace side. The two groove axes cross at 45°. The geometric separation between pipe axes is **40.4355 mm**. This is a rigid locator; the pipe cannot simply rotate across a loose crossed lashing.

**How it attaches:**

1. Seat the large groove on the 1-inch frame pipe, at the marked crossing.
2. Thread the two main-pipe ties: through the main-side slots and internal return passages, around the main pipe, and back through the paired slots. Main slots are centered at X = ±25 and Y = ±21 mm in connector coordinates.
3. Lay the ¾-inch brace into the other groove. Choose the +45 or −45 part so the brace points toward the matching connector at its other end.
4. Thread two more ties through the brace-side slots and internal passages, around the brace. Their locations are ±23 mm across the brace and ±12 mm along it. Align both ends before tightening.
5. Confirm the brace cannot slide by hand, both pipes are seated, and there is roughly 40 mm of pipe beyond the crossing. Repeat at all eight ends. Reinspect after an impact.

The **four enclosed transverse tie-return passages** are 6 mm wide × 2.8 mm high, centered at local Z = 13 mm. They keep the return straps between the pipe seats instead of routing a strap through the other pipe. The two tie directions intersect inside the body; thread one pair first, then the other. The channel height accommodates two thin crossing straps; verify actual tie thickness (target no more than about 1.2 mm each) with a print sample. Do not force a thick strap through or reduce the body thickness indiscriminately. The seat-to-seat web is 10 mm before channels, leaving about 3.6 mm of skin on either side of a channel at the deepest seats.

The joint STLs are exported **standing on a 60 × 24 mm edge**, so their printed bounding box is 60 × 24 × 60 mm. Use a brim and check support needs at groove overhangs in the slicer. Keep support out of the enclosed 2.8 mm passages; use the printer's short-bridge capability and verify clear passages on the first print. Four walls and 35–40% infill are a reasonable starting point. These are prototype connectors, not tested structural clamps.

Allow roughly **0.8–1.2 kg PETG and 24–40 printer-hours** for all saddles, washers and brace joints including spare parts on a typical desktop printer. These are planning estimates, not measured slicer results. Slice the supplied STLs with your profile. A 0.6 mm nozzle and scrap front washers reduce time. The exact solid volumes and manifold checks are in `validation.json`.

## Grass / soil base

Use the short 1200 mm feet and four opposing guy lines, tied around upper **PVC corner fittings**. Stake at X = ±1600, Y = front-frame axis ±1200 mm. Each line stays outside the 1500 mm flight opening. About 4 m of 4 mm low-stretch cord per line allows knots/adjustment. Keep lines just taut so they do not bow the frame. Brightly mark anchors. Roughly 450 mm ground anchors are an initial purchase size, not proof of holding in a particular soil; verify installed resistance in the line direction.

## Hard-surface base

Swap in the four long half-feet, giving **2400 mm** fore–aft pipe span. Reuse the tees/caps and cords. Attach each guy to the corresponding foot end about 1150 mm from the center, and strap a **weighed 15 kg bag** to that pipe end, with anti-slip rubber underneath. Four bags total **60 kg**. Bags center about 1100 mm from the frame plane. The complete bag footprint is approximately **2.52 m wide × 2.6 m deep**.

The foot, bag and guy attachment must be physically connected; do not tie the guy to a small loose bag nearby. Straps encircle both the bag and the actual foot pipe. Keep guy tension modest. This is a self-contained braced base, rather than a collection of independently sliding guy weights.

### Wind and ballast check — planning, not a rating

The face area is still 5.04 m². With assumed air density 1.225 kg/m³ and Cd = 1.3, the drag equation gives about **100 N at 5 m/s (11 mph)** and **257 N at 8 m/s**. At a 1.40 m center of pressure above ground, corresponding moments are about **140 and 360 N·m**. The coefficient is a flat-plate approximation; the ring, gusts, flexibility and local loads have not been characterized. [NASA drag equation](https://www1.grc.nasa.gov/beginners-guide-to-aeronautics/drag-equation/), [flat-plate coefficient](https://www1.grc.nasa.gov/beginners-guide-to-aeronautics/shape-effects-on-drag/)

Using twice the 5 m/s load as a prototype planning check gives 200 N and 280 N·m. For grass, the two active guys each see roughly 130 N tension with this geometry, before pretension/unequal sharing; a proposed installation check is **300 N pull per anchor in its guy direction** without creep.

For the hard-floor setup, nominal tipping resistance from 60 kg about a foot end is **60 × 9.81 × 1.2 ≈ 706 N·m**, ignoring gate weight. Sliding requires an effective friction coefficient of at least **200/(60 × 9.81) ≈ 0.34**; verify this on the actual floor. Each active guy has approximately 134 N tension and 121 N vertical component at a foot end. A 15 kg bag weighs 147 N, so local uplift margin is limited under unequal sharing or excess pretension. Check all feet for lift and increase ballast if required. The pipe joints must also retain these internal forces.

**60 kg is a starting test configuration, not a universal safe ballast prescription.** Check slip, lift, joint movement, sheet tearing and flutter under reversible loading. Begin use in low wind and lay the gate down if it moves or the anchors loosen. No operating wind-speed limit has been established. Rated fixed venue anchors can avoid ballast transport where available and permitted.

## Assembly

1. Measure sheet thickness, actual pipe OD and fitting engagement. Print one face saddle/washer and one of each brace joint. Verify pipe seating and all tie passages.
2. Mark/cut two symmetric panels on each of two sheets. Batch-cut the shared corner sheet. Cut seam backers and pads from the main-panel offcuts.
3. On a flat jig, rotate the four panels around a 1500 mm square opening and add four 150 mm corner squares. Fit the diagonal backers and square patches. Stitch mechanically, with spreaders, then tape the front seams. Check 2700 mm outer dimensions.
4. Cut PVC from the measured socket formula. Assemble the single backing frame, legs and selected feet. Check 2100 mm frame centerlines and square diagonals. Retain sockets positively.
5. Fit the eight printed brace joints and four diagonal braces. Thread/seat both pipe-retaining tie pairs at each end. Tighten only after the frame is square.
6. Position the face and install 24 saddle/washer assemblies with pads and 48 ties at the listed locations. Keep tie heads and sharp tails behind the face; flush-trim tails.
7. Lift with two people. On grass, install four stakes and guys. On hard ground, install four strapped 15 kg bags, anti-slip mats, and guys to the foot ends.
8. Check the opening **1500 ± 10 mm**, nominal diagonals **2121 mm** and diagonal difference below 10 mm. Check that no brace, connector or guy enters the clear opening. Load gently from both directions, inspect every joint, and perform the anchor/base checks above before a low-wind trial.

The first gate will likely take **2–3 hands-on hours**, plus printing; templates and preassembled pipe modules can shorten repeats. This is an estimate. Largest face part is 2400 × 600 mm; longest loose pipe is now 2065.1 mm. An assembled face is still 2700 mm square. Leave its ties/backers installed when storage allows; repeated full sheet disassembly consumes ties and time.

## Cost and material efficiency

Planning USD before tax, shipping, labor, tools, and ballast fill. Pickup quotes matter: shipping full sheets can dominate. Most entries below are allowances, not verified live quotations.

| Item | Quantity / allowance | Per-gate estimate |
|---|---|---:|
| Main 4 mm Coroplast | 2 sheets × $30 | $60.00 |
| Shared corner sheet | 1/32 sheet × $30 | $0.94 |
| 1-inch Sch40 | 4 × 10 ft at $13.50 | $54 |
| ¾-inch Sch40 | 1 × 10 ft at $10 allowance | $10 |
| All fittings | 10 fittings total, allowance | $24 |
| PETG and spare prints | Allowance, slice to confirm | $22 |
| UV ties / retaining screws | 108 working ties + spares; 16 socket screws | $20 |
| Tape | Allocated share | $8 |
| Guy cord / adjustment | About 16 m | $12 |
| Ground anchors | 4 | $20 |
| **Grass gate, allocated batch cost** | | **about $231** |
| Hard-surface add-on | 2 extra 1-inch pipes + bag/strap/rubber allowance | **about $57** |
| **Dual-surface allocated cost** | Before ballast fill | **about $288** |

For one gate buying a whole shared corner sheet, cash outlay remains about **$260 grass / $317 dual-surface**, leaving 124 corner squares. Full-batch allocated cost is **$230.94 grass / $287.94 dual-surface**. Reusable cutting jigs add a one-time $3–5 filament allowance per crew, excluded from those gate costs. Existing cord/stakes and local sheet pricing can reduce cost.

A Home Depot search result displayed $13.50 for the 1-inch 10-foot pipe. A sheet supplier listed $22.99 at its minimum 10-sheet tier; this is not a one-sheet quote. The $30 sheet and other amounts above are explicit budgeting assumptions. [Pipe listing](https://www.homedepot.com/p/100348473), [sheet supplier](https://corrugatedplastics.net/48x96_Blue4mmCorrugatedPlasticSheets.html), checked 2026-09-17.

Removing the second square and its depth links saves **three 10-foot ¾-inch pipes, twelve fittings, and 32 retained socket interfaces** versus the preceding two-frame design. With the same price allowances, that saves **about $52 per gate**. The tradeoffs are the shallower body, longer continuous main members for transport, and removal of the rear square’s stiffness. The four braces and both anchoring configurations remain; prototype checks are still required.

## WIP reference: retained and changed

Retained: correct outer/inner dimensions, repairs concentrated near corners, actual pipe OD for printed fits, and zip-tie retention. Changed: four symmetric panels and square corner infills; one 1-inch backing square with ¾-inch corner braces; commercial fitting geometry in the cut calculations; printed positive-angle brace joints at both ends; scrap-sheet seam backers; PETG rather than reliance on PLA snap action; and explicit anchored/ballasted bases. The WIP's “outer size minus twice socket depth” is not a valid general cut formula. Its proposed third-sheet straight-strip layout for four 140 mm and four 260 mm strips needs 1600 mm width, exceeding a 1219.2 mm sheet; that tunnel-wall concept is no longer used.

## Files and validation

- `FPV_Gate_2700.blend`: ten editable scenes; fonts and build guide embedded.
- `renders/`, `Assembly_Views.pdf`, `START_HERE.html`: visual assembly references.
- `printable/`: face saddle, washer, two handed brace connectors, optional ¾-inch saddle, and three A1 Mini jigs. STL coordinates are millimetres.
- `cut-layouts/`: symmetric panel layout, shared corners, offcut backers, attachment template and polygon JSON.
- `BOM.csv`, `HARD_SURFACE_ADD_ON.csv`, `PVC_CUT_LIST.csv`: quantities and cost/cut assumptions.
- `validation.json`, `polygon_validation.json`: printable topology, stock use, polygon coverage and overlap checks.
- `../scripts/build_gate.py`: regenerates the current model and STL/render outputs with local Blender.

All printable meshes are closed/manifold. Face polygons and stock layouts are checked geometrically. Fitting envelopes, soft bags, screws, zip-tie bodies and knots are schematic. Their geometry does not substitute for physical fit/load testing or slicer inspection.

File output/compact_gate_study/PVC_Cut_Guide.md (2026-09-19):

# PVC cut guide — all six compact variants

[Download the printable seven-page PDF](PVC_Cut_Guide.pdf). Each variant has its own workshop page, cutting checklist and stick layout.

**For the HUSKY 1-1/4-inch ratcheting PVC cutter.** All lengths are finished pipe end-to-end dimensions, before inserting into fittings. Use millimetres as the reference; decimal inches are provided for comparison. Every gate uses **8 long pieces + 16 short pieces = 24 pieces** of nominal 1-inch PVC.

| Opening | Paper band | Long pieces: cut 8 | Short pieces: cut 16 | 10-ft sticks, ratchet | 10-ft sticks, conservative saw plan |
|---:|---:|---:|---:|---:|---:|
| 1000 mm | 24 in | 8 × 1080.0 mm | 16 × 389.6 mm | 5 | 6 |
| 1000 mm | 18 in | 8 × 1080.0 mm | 16 × 237.2 mm | 5 | 5 |
| 1000 mm | 12 in | 8 × 1080.0 mm | 16 × 84.8 mm | 4 | 4 |
| 800 mm | 24 in | 8 × 880.0 mm | 16 × 389.6 mm | 5 | 5 |
| 800 mm | 18 in | 8 × 880.0 mm | 16 × 237.2 mm | 4 | 4 |
| 800 mm | 12 in | 8 × 880.0 mm | 16 × 84.8 mm | 3 | 3 |

The ratchet layouts reserve **10 mm per 3048 mm stick for end cleanup** and assume no material-removal kerf. They reach the minimum stick count permitted by total finished length under that reserve. The earlier conservative saw layouts reserve an additional 3 mm per cut; use them if cutting with a saw. This changes only the **1000 mm / 24-inch** purchase quantity from six sticks to five when using the ratchet. Existing study cost tables intentionally retain the conservative saw allowance.

## Cutting method

1. Check actual stock length. Square the starting end within the 10 mm total cleanup reserve.
2. Cut one short and one long piece to the finished lengths below. Measure from the current squared end each time; do not rely on cumulative marks along the original stick.
3. Remove burrs, mark 30 mm insertion from each end and dry-fit the trial pieces. **Do not deduct 30 mm from the cut length.** Both socket engagements are already included.
4. Batch the remaining cuts, checking against an accurate first piece. Label long pieces L1–L8 and short pieces S1–S16. The diagrams are allocation plans, not full-scale ruler templates.
5. Slide the required magnet sleeves onto pipes before closing the frame. Use the variant-specific sleeve-position CSV in the study guide.

A 12-inch-paper short piece is 84.8 mm long: two 30 mm insertions leave 24.8 mm exposed. The existing short-section sleeve is omitted in that variant. Feet and ground supports are not included.

## 1000 mm opening / 24-inch paper

Cut **8 × 1080.0 mm** long pieces (42.5197 in) and **16 × 389.6 mm** short pieces (15.3386 in). Buy **5 ten-foot sticks**. Outer square: 2219.2 mm.

| Stock | Long pieces | Short pieces | Spare after 10 mm reserve |
|---|---:|---:|---:|
| Sticks 1–3 | 2 × 1080.0 | 2 × 389.6 | 98.8 |
| Sticks 4–5 | 1 × 1080.0 | 5 × 389.6 | 10.0 |

[Ratcheting-cutter stock CSV](OPEN_1000_PAPER_24_Ratcheting_Stock_Layout.csv) · [Conservative saw stock CSV](OPEN_1000_PAPER_24_Stock_Layout.csv) · [Pipe IDs and sleeve positions](OPEN_1000_PAPER_24_PVC_Cuts.csv)

## 1000 mm opening / 18-inch paper

Cut **8 × 1080.0 mm** long pieces (42.5197 in) and **16 × 237.2 mm** short pieces (9.3386 in). Buy **5 ten-foot sticks**. Outer square: 1914.4 mm.

| Stock | Long pieces | Short pieces | Spare after 10 mm reserve |
|---|---:|---:|---:|
| Sticks 1–4 | 2 × 1080.0 | 3 × 237.2 | 166.4 |
| Stick 5 | 0 × 1080.0 | 4 × 237.2 | 2089.2 |

[Ratcheting-cutter stock CSV](OPEN_1000_PAPER_18_Ratcheting_Stock_Layout.csv) · [Conservative saw stock CSV](OPEN_1000_PAPER_18_Stock_Layout.csv) · [Pipe IDs and sleeve positions](OPEN_1000_PAPER_18_PVC_Cuts.csv)

## 1000 mm opening / 12-inch paper

Cut **8 × 1080.0 mm** long pieces (42.5197 in) and **16 × 84.8 mm** short pieces (3.3386 in). Buy **4 ten-foot sticks**. Outer square: 1609.6 mm.

| Stock | Long pieces | Short pieces | Spare after 10 mm reserve |
|---|---:|---:|---:|
| Sticks 1–4 | 2 × 1080.0 | 4 × 84.8 | 538.8 |

[Ratcheting-cutter stock CSV](OPEN_1000_PAPER_12_Ratcheting_Stock_Layout.csv) · [Conservative saw stock CSV](OPEN_1000_PAPER_12_Stock_Layout.csv) · [Pipe IDs and sleeve positions](OPEN_1000_PAPER_12_PVC_Cuts.csv)

## 800 mm opening / 24-inch paper

Cut **8 × 880.0 mm** long pieces (34.6457 in) and **16 × 389.6 mm** short pieces (15.3386 in). Buy **5 ten-foot sticks**. Outer square: 2019.2 mm.

| Stock | Long pieces | Short pieces | Spare after 10 mm reserve |
|---|---:|---:|---:|
| Sticks 1–2 | 3 × 880.0 | 1 × 389.6 | 8.4 |
| Sticks 3–4 | 1 × 880.0 | 5 × 389.6 | 210.0 |
| Stick 5 | 0 × 880.0 | 4 × 389.6 | 1479.6 |

[Ratcheting-cutter stock CSV](OPEN_800_PAPER_24_Ratcheting_Stock_Layout.csv) · [Conservative saw stock CSV](OPEN_800_PAPER_24_Stock_Layout.csv) · [Pipe IDs and sleeve positions](OPEN_800_PAPER_24_PVC_Cuts.csv)

## 800 mm opening / 18-inch paper

Cut **8 × 880.0 mm** long pieces (34.6457 in) and **16 × 237.2 mm** short pieces (9.3386 in). Buy **4 ten-foot sticks**. Outer square: 1714.4 mm.

| Stock | Long pieces | Short pieces | Spare after 10 mm reserve |
|---|---:|---:|---:|
| Sticks 1–4 | 2 × 880.0 | 4 × 237.2 | 329.2 |

[Ratcheting-cutter stock CSV](OPEN_800_PAPER_18_Ratcheting_Stock_Layout.csv) · [Conservative saw stock CSV](OPEN_800_PAPER_18_Stock_Layout.csv) · [Pipe IDs and sleeve positions](OPEN_800_PAPER_18_PVC_Cuts.csv)

## 800 mm opening / 12-inch paper

Cut **8 × 880.0 mm** long pieces (34.6457 in) and **16 × 84.8 mm** short pieces (3.3386 in). Buy **3 ten-foot sticks**. Outer square: 1409.6 mm.

| Stock | Long pieces | Short pieces | Spare after 10 mm reserve |
|---|---:|---:|---:|
| Sticks 1–2 | 3 × 880.0 | 4 × 84.8 | 58.8 |
| Stick 3 | 2 × 880.0 | 8 × 84.8 | 599.6 |

[Ratcheting-cutter stock CSV](OPEN_800_PAPER_12_Ratcheting_Stock_Layout.csv) · [Conservative saw stock CSV](OPEN_800_PAPER_12_Stock_Layout.csv) · [Pipe IDs and sleeve positions](OPEN_800_PAPER_12_PVC_Cuts.csv)

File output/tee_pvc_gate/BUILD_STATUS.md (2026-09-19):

# Build status — 2026-09-19

- MAG_SLEEVE printed; user confirmed a perfect fit on the purchased nominal 1-inch PVC. Keep every gate PVC bore at 33.5 mm.
- User has a Husky 1-1/4-inch ratcheting PVC cutter.
- Prefer accurately cut and verified PVC master lengths (389.6 and 1560.8 mm) for repeated marking. Printed measuring tools are retained as optional artifacts, not the next priority.
- Latest chosen print: ONE_TEE_A1Mini_PETG.3mf. Opened locally in Bambu Studio with A1 Mini / PETG / 0.20 mm / no supports. Estimate 98.49 g, 226.45 minutes. Not submitted by the assistant; user has not reported completion.
- No successful elbow/tee/cross print or structural load test is recorded.
- Baseline guy elbow: central rear eye with one corner magnet. New requested revision: simultaneous front and rear guys, diagonal eye extension, separate top and side magnet pads. Preserve this baseline before implementing that revision.

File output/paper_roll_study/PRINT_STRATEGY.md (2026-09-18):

# Diagonal rails and sacrificial stacks

A1 Mini nominal volume is 180 × 180 × 180 mm. At 45°, a rectangular footprint of length L and maximum width W occupies (L + W)/sqrt(2) on each bed axis. With 5 mm margins, **L + W ≤ 240.416 mm**. All tongues, holders, starter feet and brims count. A 20 mm-wide part permits 220.4 mm total length; a 32 mm-wide connector envelope permits only 208.4 mm. The raw 254.6 mm diagonal is a zero-width line.

## Actual sliced samples

| Sample | Rails | Bed envelope | Height | PETG | Estimated time |
|---|---:|---:|---:|---:|---:|
| DIAGONAL_1x220 | 1 × 220 mm | 169.7 mm square | 13.0 mm | 15.9 g | 43 min |
| DIAGONAL_8x220 | 8 × 220 mm | 169.7 mm square | 99.8 mm | 104.3 g | 4 h 19 min |
| DIAGONAL_13x198 | 13 × 198 mm | 154.1 mm square | 161.8 mm | 150.7 g | 6 h 17 min |
| 06_OVERNIGHT_26_RAILS | 26 × 198 mm, two stacks | 169.7 mm square | 161.8 mm | 301.4 g | 11 h 54 min |

Bambu Studio estimates: A1 Mini 0.4 mm nozzle, Generic PETG, 0.2 mm layers, 3 walls, 15% infill, textured PEI, supports off, no brim; times include startup. Actual printer/filament conditions will differ. Exact source files and sliced projects are supplied. No printer job was sent.

The two-stack plate has 2 mm between its starter feet. Both stacks print together by layer. It produces 5.148 m of plain rail: 1.8× the length of thirteen 220 mm rails, but shorter rails mean more eventual frame connections. These are **manufacturing samples without final rail-end joinery or magnet lugs**, not pieces to assemble into the gate. Integrated lugs may invalidate this footprint or the stacking orientation. Keep spring keys and lugs out of sacrificial seams; refine rail bodies after choosing the joint.

## First test: three short stacks

Print `03_STACK_SEPARATION_TESTS` before a tall run: 33.3 g, about 94 min. It contains:

- `STACK_TEST_06`: three 60 mm rails, continuous 0.6 mm scoring neck.
- `STACK_TEST_08`: same, with 0.8 mm neck.
- `STACK_TEST_TABS`: 0.6 mm-wide, 2 mm-long tabs on 10 mm pitch between upper rails; the intervening 8 mm spans must bridge.

The initial 0.4 mm neck disappeared in the standard slicer profile, causing empty layers; it was removed from the supplied kit. All current continuous necks survive slicing, and extrusion was checked at every neck height. The initial tab pattern also triggered a floating-cantilever warning. Adding a terminal tab at each end removed that warning; all current slices are warning-free with supports off. The intervening 8 mm bridges still require physical testing.

Each diamond section expands at approximately 45° from a narrow neck. The starter foot and necks are sacrificial. PETG is fused to PETG here; easy separation is not established. Let the short print cool, support it flat, score the neck from both sides and separate one interface at a time. If it needs excessive force or splits a rail layer, stop that method and record the failure. Measure remaining scars, straightness and cross-section. The 220 mm continuous neck has 3.67× the joined length of the 60 mm coupon; short-test success is not proof of full-length separation.

Do not scale parts to fit: that changes joint clearances. Preserve the supplied 45° orientation. Any added brim must be rechecked against the bed boundary. A simple open air gap is not a substitute for a supporting connection. Taller prints on a moving bed need a successful progressively taller physical trial before treating this as a reliable overnight process.

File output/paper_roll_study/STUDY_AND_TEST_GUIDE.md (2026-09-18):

# Paper-roll gate / picture-frame joinery study

Baseline committed as **732f592**. New work is on `iteration/paper-roll-click-magnet`. Open `Paper_Roll_Joinery_Study.blend` or `index.html`; the visual PDF includes the illustrated views. This is a design comparison and a set of full-scale interface tests, **not yet a production gate kit**. The 25 STL variants include clearance trials and stack experiments, not 25 required gate part types.

## Chosen paper layout

Four identical **2090.4 × 609.6 mm** strips form a pinwheel: 2700 mm outside, 1480.8 mm opening. Use the roll at its full 24-inch width. Make four crosscuts per gate after squaring the roll's leading edge. A 100-ft / 30.48 m roll supplies three complete gates plus two spare strips and approximately 1.21 m remaining. Transport four rigid borders approximately 2.09 m long, with faces attached. No hinges are proposed.

The linked roll was listed at $32.99 when researched. At that illustrative price, paper consumed is $9.05/gate, or $11.00/gate if allocating a whole roll across its three complete gates and treating spare material as reserve. Paper thickness and outdoor durability are unconfirmed. Treat this as a replaceable dry-weather face; it does not brace the frame.

## Three joint combinations

| Option | Frame connections | Paper attachment | Main tradeoff |
|---|---|---|---|
| A | Positive click keys | Snap-over battens | Lowest magnet cost; paper grip and gentle removal need testing |
| B | Keyed magnetic splice caps | Magnetic pads | Easy release, but a peeling load can also release structural splices |
| C — preferred trial | Positive click keys | Magnetic pads | Structural joints stay mechanically latched while paper is removable |

Tony Youngblood's supplied modular picture-frame model is shown in Blender scene 10. Its repeated teeth, modular members and calibrator are useful precedents. Its instructions require supports under some edges, so those source meshes are not included in our print plates. Our new key uses two planar spring forks with pinch release and two rigid dovetail guides. Guides locate the joint and resist lift; hooks resist axial withdrawal. The latch should relax after engagement, rather than remain bent. These are newly modeled parts, not compatible copies of the source frame or Kato train track.

The pictured test key is replaceable if worn. Production rail bodies would use the selected socket clearance and hide no spring under paper. Keep release access on the rear. Shared keys and sockets should also serve straight splices, corner nodes and the PVC dock; the final corner/diagonal node family remains to be detailed after fit testing.

## Connecting the inner and outer edges

Scenes 11 and 14 compare ten longitudinal bays, a middle paper-support rail and two half-width rows. Rail centerlines are 12 mm inside the paper perimeter: 2066.4 × 585.6 mm. Each half-bay is 206.64 × 292.8 mm; a diagonal is 358.37 mm, so it needs at least two printable segments plus its joint allowance. Those are node-to-node spans, not final STL cut lengths.

| Arrangement | Member length per border | Per gate | Interpretation |
|---|---:|---:|---|
| Ladder | 12.64 m | 50.56 m | Fewest members; relies heavily on stiff joints to resist racking |
| Alternating diagonals | 19.81 m | 79.23 m | Preferred starting geometry: triangles connect both edges through the center rail |
| Full crosshatch | 26.98 m | 107.90 m | 36% more member length than alternating diagonals, plus crossing details |

These are geometric comparisons, not measured stiffness results. Diagonals need positive connections and adequate compression/bending stiffness; loose splices can defeat the triangulation. Full crosshatch also needs a crossing node or a deliberate offset between crossing members. It is shown as a concept, not overlapping production solids.

**Do not make every web as heavy as the stack-test rail.** The 12 mm diamond section slices at roughly 57 g/m after removing its starter-foot allowance. Using it everywhere in the alternating layout would consume roughly 4.5 kg before nodes, docks and magnet pads. At an assumed $20/kg, that is about $90 for members alone. Narrower web sections and fewer bays supported by the PVC are the next cost optimization; they need a representative braced-panel test. This study does not substantiate a one- or two-spool finished gate.

## Half-cylinder magnet holders

Scene 12 and `D_MAGNET_LUG` implement a D-shaped projection toward the paper. Its 10 mm radius half-cylinder contains a rear-loaded 6.3 mm pocket for a 6 × 2 mm disc behind a **0.4 mm local face skin**. The straight flange has two M3 holes for a bench test; in production this lug should be integral with the rail/node, eliminating separate mounting bolts. Rotate the same holder around edges and corners. Pocket position and paper contact stay consistent.

A 24 mm-wide removable `PAPER_PAD` spreads front pressure. It adds another 0.4 mm skin. Thus the actual magnet gap is **0.8 mm + paper + adhesive**, not just paper thickness. Compare the pad against a bare counter-magnet in a controlled bench trial to quantify that extra skin's effect. The final arrangement must retain both magnets: check polarity and dimensions first, then bond them into the pockets against the thin face. No hot-print insertion is needed. Adhesive thickness adds to the magnetic gap.

Use `MAGNET_POCKET_GAUGE` first: with bores upward and its long axis horizontal, diameters run **6.1 / 6.3 / 6.5 mm** from left to right. The gauge pockets are 2.2 mm deep. Measure the actual magnets and the paper; 6 × 2 is a nominal size.

For a given maximum perimeter pitch, each strip also has six interior pads on the middle rail at less than 300 mm pitch. Corner sites are counted only once:

| Maximum edge pitch | Clamp pairs/gate | Individual magnets | Magnet cost at $0.10 / $0.20 / $0.30 each |
|---|---:|---:|---:|
| 300 mm | 96 | 192 | $19.20 / $38.40 / $57.60 |
| 150 mm — pictured | 168 | 336 | $33.60 / $67.20 / $100.80 |
| 100 mm | 240 | 480 | $48.00 / $96.00 / $144.00 |

These are trial spacings, not wind ratings. The cost assumptions exclude shipping, printed pads, PVC and hardware. Magnet-held frame splices would add **four magnets per splice** beyond the paper counts. Dense magnetic retention can cost more and take longer to install than the cheap paper saves. Keep pads and paper on the four borders for transport; only border joins and PVC docks should be operated at the field.

## Frame to PVC: actual mating test parts

Scene 13 shows assembled and exploded versions. `PVC_HALF_33` targets 33.4 mm OD pipe; print two identical halves. Measure your pipe—nominal trade size is not its OD. `PVC_HALF_27` is an alternative collar experiment for 26.67 mm OD, not a second required main-frame collar.

1. Put two `PVC_HALF_33` halves around the pipe, opposed by 180°. Join their ears using two M3 × 25 mm bolts, nuts and washers. The 0.8 mm ear gap allows closing movement; check grip rather than assuming full closure means tight. Test sliding and rotation on the actual pipe.
2. Bolt `DOCK_SOCKET` to one collar's flat pad using two M3 × 25 mm bolts, nuts and washers. Its two round mounting holes register with the pad. Point its open fork entrance away from the pipe. Keep the release throat exposed.
3. Bolt `DOCK_TONGUE` to the middle of `FRAME_DOCK_NODE` using two M3 × 16 mm bolts, nuts and washers. The flange faces register and both holes align. The frame node's two end sockets are for later rail connections using the common click key.
4. Slide the tongue's two rigid runners and central forks into the socket together. Seat the shoulder and inspect both hooks beyond their catches. Pinch the two fork tips inward to withdraw; do not pry the rigid runners upward.
5. Leave the collar/receiver on PVC and the tongue/node on the border during transport. These workshop fasteners are not part of field setup.

For one complete dock: **4 × M3×25, 2 × M3×16, 6 nuts, 12 washers**, plus the five printed pieces (two collar halves, receiver, tongue and node). Horizontal bolt passages have 4.8 mm diamond diagonals, giving about 3.39 mm inscribed circular clearance; the vertical round passages are 3.4 mm. Fit still depends on your printer. Bolt/nut access is external; no heat-set inserts or zip ties are required.

The intended load path is paper → lugs/edge rails → diagonal webs/center rail → spaced frame docks → one PVC square and four corner braces → feet/ground anchoring. Four docks per border are depicted as a starting arrangement. Only the small dock assembly is detailed, not all full-gate interfaces. Keep the previously studied staked grass base or ballasted hard-surface feet; the paper/PETG iteration does not establish a wind/ballast rating. Production angled PVC-brace nodes and gate-corner release joints still need integration.

## Print and test in this order

All source STLs use millimetres. Use the supplied sliced **A1 Mini / 0.4 mm / PETG** projects at 100% scale. Supports are off. No files have been sent to a printer.

1. **Latest concept first — plate `05_D_MAGNET_AND_DOCK`: seven pieces**, approximately 33 g / 1 h 53 min. It contains one D lug, one front pad, two collar halves, one dock socket, one tongue and one frame node. Add two 6 × 2 magnets, a paper scrap, the hardware above and actual PVC. This directly tests your latest holder/dock idea without printing the other variants.
2. **Click and magnetic comparison — plate `01_CLICK_AND_MAGNET_JOINTS`: six pieces**, approximately 24 g / 65 min. Join the two clearance sockets with the double key; test each end separately first. Both spring tips must move freely and return after clicking. For the magnetic comparison, butt two identical rail-end samples together and flip the keyed cap onto them so its four pins enter the holes. Four magnets complete that splice. Test pull, sliding and peel separately.
3. **Paper retention — plate `02_PAPER_CLAMP_TESTS`: eight pieces**, approximately 33 g / 2 h 4 min. Compare 0.4, 0.8 and 1.2 mm frame skins using the same magnets/paper/pad. The two snap-batten caps provide 0.15 and 0.30 mm central paper clearances. Lay paper over the base's central face, push the cap down until its lips catch under the side ledges, and check actual paper grip. A cap that latches but lets thin paper slide has not passed. The end-up battens have small footprints; if adhesion is poor, add a modest brim in Bambu Studio and recheck placement.
4. **Stack strategy — plate `03_STACK_SEPARATION_TESTS`: three short stacks**, approximately 33 g / 94 min. Follow `PRINT_STRATEGY.md`. The tabbed sample now includes terminal tabs and slices without warnings; its 8 mm bridges still need physical testing. Start with the continuous-neck versions. Only then try a single long rail, a taller stack and finally the 26-rail plate.

For each click joint, record insertion force qualitatively, fully seated play and release accessibility. As an initial workshop screen, repeat 20 assembly/release cycles and inspect whitening, cracking and permanent opening. That count is a comparison procedure, not a fatigue-life specification. A magnetic clamp needs three separate observations: straight pull-off, edge peeling and sliding. Use the same slowly applied measured load for comparisons, record the failure load and failure mode, and do not convert that result directly into a gate wind rating. Record whether paper tears before a magnet lets go. Test a short real-paper span at both 150 and 300 mm pad spacing before choosing the full count.

## Verification and limits

`print_checks.json` records 25 manifold positive-volume STL masters, 31 plate/individual layouts and corresponding actual slices. Every exported part and supplied plate fits within the 180 mm cube with bed margin. All current slices are warning-free with supports disabled. Terminal tabs removed an earlier cantilever warning; that does not prove the bridging will print successfully. Continuous stacks have extrusion at every neck layer. Twenty nominal assembled-pair checks find no material intersections above the 0.05 mm³ numerical tolerance, including the assembled dock and PVC pipe. These checks establish digital fit and toolpath presence—not print success, separation quality, latch fatigue, magnetic holding force or outdoor stability.

The production next step is to select one successful key clearance, magnet window and stack neck, then detail the rail endpoints, shared corner/diagonal nodes and brace collars around those measured results. The full-gate Blender scenes label their members and dock sites as schematic so they are not confused with the tested export geometry.

Sources and source-model attribution are in `RESEARCH.md` and `../../reference/picture_frame/ATTRIBUTION.md`.

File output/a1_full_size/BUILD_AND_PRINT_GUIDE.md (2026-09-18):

# Full-size whole-sheet gate — A1 Mini iteration

[Download the two-part assembly and test PDF](Assembly_and_Test_Instructions.pdf).

Every printed component now has an STL at full size and in its intended print orientation. **19 unique files, 740 printed pieces per gate.** All fit inside **180 × 180 × 180 mm**, with no diagonal packing required. Longest piece: **144.2 mm**. The assembly remains a physical-test prototype; volume checks and successful slices do not demonstrate snap fatigue, assembled stiffness or wind performance.

Open [the Blender model](A1_Full_Size_Gate.blend), [visual guide](A1_Full_Size_Visual_Guide.pdf), or [visual index](index.html). The complete per-file quantities and print dimensions are in [BOM.csv](BOM.csv); geometry and slicing evidence is in [print_checks.json](print_checks.json).

## What changed

- The previous oversized rear ribs are now 126.867 mm horizontal pieces and 144.2 mm vertical pieces, joined with alternating 16 mm lap overlaps and paired tie holes.
- A stepped cross node separates the perpendicular ribs. Integral shoes support the paper from behind; two lightly tensioned cord runs retain it from the front.
- **Only two channel types:** `CHANNEL_LONG`, 140.84 mm (120 per gate), and `CHANNEL_SHORT`, 138 mm (96 per gate). Common symmetric mounting windows and cord notches replace the earlier nine variants. Extra accessory windows slightly reduce material; the end windows that locate splint bosses remain unchanged. Every previous attachment position is checked against the common window layout.
- Edge channels are 140.84 or 138 mm long. Registered splints locate their ends; two ties retain each splice. All node, rib, dock and corner attachments have modeled holes.
- One common two-fork snap bridge releases the **eight gate-corner connections and sixteen PVC docks**. Workshop splices use ties and stay assembled. This is not an entirely snap-assembled kit.
- Both ends of every diagonal PVC brace have a printed flat 45° link with two pipe saddles. No cross-lashed pipe-to-pipe brace connections.
- No hinges, no second PVC square, no cutting or punching of the twelve posterboard sheets.

## Dimensions and materials

| Dimension | Value |
|---|---:|
| Whole paper insert | 711.2 × 558.8 mm / 28 × 22 inches |
| Inserts per rigid border | 3 |
| Rigid border | 2151.6 × 564.8 mm |
| Gate outside | 2716.4 mm square |
| Nominal face opening | 1586.8 mm square |
| PVC frame centerlines | 2100 mm square |
| Main pipe / brace pipe outside diameter | 33.40 / 26.67 mm |
| Main pipe axis behind front face | 55 mm |
| Paper slot | 0.8 mm, designed around approximately 0.4 mm posterboard |

The gate grew slightly to accommodate stronger channel spines and sheet clearance. Measure your actual sheets and thickness before printing more than the fit kit. The slot has about 3 mm of edge capture at the nominal sheet position. Do not scale all parts to correct a stock-thickness mismatch; change the slot parameter and recheck the joins.

## Print and material findings

Local **BambuStudio 2.8.2.61** sliced all 19 unique parts and the 12-piece interface fit plate without warnings, using the resolved **A1 Mini / 0.4 mm / 0.20 mm Standard / Generic PETG / Textured PEI Plate** presets. Three walls, 15% infill, supports off, brim off. Preset files are included. The export units are millimeters; print at **100%**.

All source meshes have zero nonmanifold edges. All exported meshes sit on Z=0 and have positive volume. A triangle-orientation check found no downward-facing surfaces steeper than 45° above the bed, excluding bed-contact faces. This checks geometric support intent; it does not prove adhesion or every small overhang's print quality. Verify the preview and actual first print. If adhesion needs a brim, parts have substantial bed margin; re-slice after adding one.

**Sliced part material: 2967.6 g PETG per gate.** With 10% reserve: **3264.3 g**, so buy **four 1 kg spools**. Three spools leave only about 32 g before startup waste, prototypes or failed prints; use four with reserve. This supersedes the earlier schematic 1.84 kg estimate: that allowance omitted the completed joints and full rib system.

At an assumed $20/kg, consumed printed material is **$59.35**, or **$65.29 including reserve**. Twelve sheets at your $0.99 price add **$11.88**. Thus printed plastic plus paper is **$71.23**, or **$77.17 with filament reserve**, before ties, cord, PVC, fittings, anchoring, electricity and labor. Buying four complete $20 spools plus paper is **$91.88 cash** with filament left over. These are arithmetic assumptions, not current supplier quotes.

Summing model-only slicer times gives about **146.0 printer-hours**; running every piece as its own job gives **228.6 hours** including repeated startup. Batch printing reduces startup overhead, but actual packed-plate travel and cooling alter these estimates. Production plates have not been optimized. The individual sliced projects are verification samples, not an instruction to run 740 separate jobs.

The all-printed framing solution preserves whole-sheet yield and four-border field assembly, but **does not minimize workshop labor**. It uses **856 ties**. If low crew effort is the priority, the earlier Coroplast/PVC design is the more promising route. This iteration establishes a complete printable baseline for testing, rather than evidence that the posterboard approach is the cheapest finished gate.

## Full-size printed parts

| File / part | Quantity | Print X × Y × Z, mm |
|---|---:|---|
| [SPLINT](printable/SPLINT.stl) | 168 | 40 × 8 × 4.4 |
| [CORNER_NODE](printable/CORNER_NODE.stl) | 48 | 34 × 34 × 7 |
| [RIB_ANCHOR](printable/RIB_ANCHOR.stl) | 48 | 40 × 26 × 7 |
| [RIB_CROSS](printable/RIB_CROSS.stl) | 12 | 48 × 48 × 6 |
| [BORDER_BRIDGE](printable/BORDER_BRIDGE.stl) | 16 | 60 × 12 × 3 |
| [FIELD_RECEIVER](printable/FIELD_RECEIVER.stl) | 16 | 40 × 24 × 6.4 |
| [SNAP_BRIDGE](printable/SNAP_BRIDGE.stl) | 24 | 36 × 16.8 × 3 |
| [RIB_H_LOW](printable/RIB_H_LOW.stl) | 32 | 126.867 × 17.825 × 12 |
| [RIB_H_LOW_DOCK](printable/RIB_H_LOW_DOCK.stl) | 16 | 126.867 × 17.825 × 16 |
| [RIB_H_HIGH](printable/RIB_H_HIGH.stl) | 24 | 126.867 × 20.825 × 12 |
| [RIB_V_LOW](printable/RIB_V_LOW.stl) | 24 | 144.2 × 17.825 × 12 |
| [RIB_V_HIGH](printable/RIB_V_HIGH.stl) | 24 | 144.2 × 20.825 × 12 |
| [PIPE_33](printable/PIPE_33.stl) | 24 | 61 × 43.899 × 16 |
| [PIPE_27](printable/PIPE_27.stl) | 8 | 44 × 35.8 × 16 |
| [DOCK_CAP](printable/DOCK_CAP.stl) | 16 | 24 × 18 × 2.4 |
| [DOCK_PEDESTAL](printable/DOCK_PEDESTAL.stl) | 16 | 7 × 12.35 × 22 |
| [BRACE_LINK_45](printable/BRACE_LINK_45.stl) | 8 | 103.51 × 127.51 × 3 |
| [CHANNEL_LONG](printable/CHANNEL_LONG.stl) | 120 | 140.84 × 14 × 6 |
| [CHANNEL_SHORT](printable/CHANNEL_SHORT.stl) | 96 | 138 × 14 × 6 |

Quantities include every printed face, dock and brace connector. The base uses purchased PVC/fittings and has no additional printed pieces. Presentation copies are excluded.

## Purchased fasteners and stock

| Item | Working quantity | Use |
|---|---:|---|
| Whole 22 × 28 inch posterboard | 12 | Three per border |
| Standard ties, 2.5 mm wide | 744 | Workshop splices, nodes, laps, bridges, receivers and docks; approximately 100 mm lengths |
| Releasable ties, at most 2.5 mm wide | 48 | Four per removable top cap; use removable cord loops if suitable narrow releasable ties are unavailable |
| Pipe keeper ties, approximately 3.6 × 250 mm | 32 | One around every pipe saddle; releasable type permits backing-frame disassembly |
| Brace-link retaining ties, approximately 3.6 × 150 mm | 32 | Four per link |
| Smooth 0.8 mm cord/monofilament | 20 m purchased | 24 front spans, plus routing and knots |
| Main PVC square | Four 1-inch nominal sides | 2100 mm centerline square; see cutting list |
| Diagonal braces | Four 3/4-inch nominal tubes | About 425.7 mm each; changed from earlier design |
| Main frame fittings | Two upper elbows, two lower tees | Lower tees continue to legs |
| Base | Two legs, two foot tees, four caps | Same anchored/ballasted base arrangement as earlier design |
| Grass feet / alternative hard-floor feet | Four half-feet of each length for dual-surface kit | Install one set at a time |

Buy spare ties beyond these exact working quantities. Narrow hole clearances are designed for the strap, not the head; heads remain outside the part. Confirm your chosen tie's width and thickness in the fit kit.

Tie accounting: 336 at channel splints; 96 at corner nodes; 96 at rib anchors; 168 across rib endpoints/laps/cross nodes; 32 at permanent cell bridges; 32 at field receivers; 32 at dock caps; 32 heavy brace-link ties; 32 pipe keepers. Total **856**, including the **48 reusable top-cap ties**.

## Print the minimum nine-piece concept test first

The [nine-piece concept test](MINIMAL_CONCEPT_TEST.md) is the recommended first print: **32.4 g PETG / about 95 minutes**. It contains a complete working PVC dock, two channel types, a splint and a corner node. Print one of each listed part and reuse them between tests. The earlier twelve-piece plate below samples more individual shapes but omits the docking rib; use the nine-piece plate to test a complete dock.

## Earlier twelve-piece interface sampler

Open [Fit_Kit_1to1_LAYOUT_A1Mini_PETG.3mf](sliced/Fit_Kit_1to1_LAYOUT/Fit_Kit_1to1_LAYOUT_A1Mini_PETG.3mf). It contains twelve actual full-size components on one A1 Mini plate: one universal long channel and one universal short channel, one splint, one snap bridge, two socket caps, one 1-inch pipe saddle, one rib cross, one field receiver, one corner node, one horizontal rib and one dock pedestal. **38.5 g PETG, about 113 minutes.** Check the printer, nozzle, filament and plate setting before printing. No print has been sent to a printer.

1. Slide your actual paper stock into both channels; it should move without creasing or forcing the lips apart.
2. Butt the long and short sample channels with a 0.2 mm gap. Fit the four splint bosses into the rear windows. Each side of the joint gets one tie threaded through its two hollow bosses. Check registration and resist hand bending/sliding; the ties retain the splint, while the bosses bear against the windows.
3. Hold the two socket caps with centers 24 mm apart. Insert the snap bridge until its rigid stops seat. The 2.4 mm plate is caught behind the hooks, with 0.4 mm nominal axial clearance. Pinch one fork's two prongs inward and lift that end, then the other. Check release access in a complete dock as well as loose caps. Blunt tweezers can assist testing; easy repeated hand release is still to be demonstrated.
4. The 1.6 mm fork split has a rounded root. Each hook needs roughly 0.7 mm inward movement including clearance. Do not force a binding print: deburr first, measure and adjust the socket/clearance locally. Perform repeated assembly/release and a pull test; inspect for cracks and permanent set.
5. Trial the pipe saddle on measured 33.4 mm OD PVC and install its keeper tie. Check for axial slip and rotation. The open C profile alone is not the keeper.
6. Inspect the rib's integral contact shoe and smooth its paper-facing edges. Then build **one complete whole-sheet bay** before printing the remaining eleven. Evaluate racking, paper flutter and the top-cap removal process.

The earlier [1:15 tabletop model](../rigid_whole_sheet/index.html) remains useful for the four-border assembly idea. It represents the prior concept and enlarged model joints; it is not a scaled copy or a fit test of these new full-size interfaces.

## Workshop assembly

Lay the first border face-down with bay 1 at the left and bay 3 at the right. A bay measures 717.2 × 564.8 mm. Every bay uses the same two channel types:

| Sheet edge | Channel | Pieces per edge | Total per gate |
|---|---|---:|---:|
| Long edges | `CHANNEL_LONG` / 140.84 mm | 5 | 120 |
| Short edges | `CHANNEL_SHORT` / 138 mm | 4 | 96 |

The first channel starts 6.1 mm from the mathematical corner; adjacent bodies have 0.2 mm gaps. [CHANNEL_ASSEMBLY_MAP.json](CHANNEL_ASSEMBLY_MAP.json) gives every start position. Read edges counterclockwise around a face-down bay: bottom left-to-right, right bottom-to-top, top right-to-left, left top-to-bottom. Keep paper lips facing the paper and the deep spine facing the rear.

Every long channel has the same symmetric windows and center cord notch. Every short channel has the same symmetric windows and end cord notches. There are no position-specific channel files to sort. Accessory windows are wider where earlier hole patterns overlapped; at least 2 mm of web remains between windows, and the registered splice windows stay 6 mm wide. [CHANNEL_FEATURES.json](CHANNEL_FEATURES.json) records their geometry. Physical stiffness remains part of the bay test.

1. Build the four edge chains with registered splints, then the four inside corner nodes. Corner-node fences locate against the inward rail face. Tie each corner to both adjoining rails using the node hole and corresponding rear-spine window; do not cover the paper slot with a strap. Leave the top edge removable.
2. Install the four midpoint rib anchors. Each has two rail ties and one paired-hole rib attachment. Locate the cross node at the sheet center with its taller seats along the short sheet dimension.
3. Each horizontal half-rib, from the outer edge to the center, uses **LOW–HIGH–LOW**, overlapping 16 mm at each joint. Each vertical half uses **LOW–HIGH**. One tie passes through both aligned hole pairs at each overlap. The horizontal ends sit on the lower cross seats; vertical ends sit on the higher seats. The two opposing halves stop short of each other.
4. Replace selected low horizontal pieces with `RIB_H_LOW_DOCK`: bay 1 right-half innermost piece, bay 2 outermost piece on each half, bay 3 left-half innermost piece. This yields four dock stations per border. Place the pedestal on the rib, cap over the pedestal, and retain with two ties through the cap and rib's matching holes. The open pedestal clears the snap fork tips.
5. Slide in the whole paper sheet. Refit the five-piece top cap. Its two corner attachments and two rib-anchor attachments use the four reusable ties. To replace paper later, loosen those four ties and the associated cord, lift the cap chain and slide the sheet out. The rib anchor can remain on the rib; it clears the paper plane.
6. Add two front cord spans per sheet, one each direction. Route over the edge-midpoint V-grooves, around the exterior edge to the rear windows, and tie off behind the frame. The short-edge groove is split across the central rail joint. Use only enough tension to retain the sheet against the rear shoes; excessive tension bows the frame or marks the paper. Knots and wraparound ends are not fully modeled in the presentation.
7. Join adjacent bays with two `BORDER_BRIDGE` pieces per seam, one near each long edge, through the spare paired holes in the corner nodes. Two ties per bridge. These joints stay assembled for transport.
8. Install four field receivers per border: two on bay 1's bottom edge and two on bay 3's right edge, 64 mm from the ends of the 564.8 mm seam. The required positions lie within the universal channel windows; unused accessory windows need no fasteners. Seat their fences inward and retain with two rail ties each.

## PVC and field assembly

Build one 2100 mm centerline square. The [PVC cutting list](PVC_CUT_LIST.csv) uses the earlier example fitting take-up, but actual fittings determine final tube cuts. Upper corners have elbows; lower corners have tees continuing down to the feet. Reuse the earlier positive socket-retention method. These commercially purchased fittings are described in the BOM; the new views simplify the stock pipe runs and omit fitting bodies and bases.

Each diagonal has a theoretical 400 × 400 mm span. Cut its tube approximately **425.7 mm**: 565.7 mm diagonal minus 70 mm at each end. At each end, the `BRACE_LINK_45` carries one `PIPE_33` on the main frame and one `PIPE_27` on the diagonal. The brace-saddle axis is 90 mm from the theoretical main-pipe intersection, so its clamp sits 20 mm from the trimmed tube end. Flip the link face as needed at mirrored corners; it has no handed fasteners. Use four heavy ties per link to secure the saddle feet and one keeper around each saddle/pipe. For full backing-frame teardown, use releasable keepers so braces can detach without cutting ties.

Set up and anchor/ballast the PVC backing before relying on the paper face for stability. Seat each rigid border's four saddles on the corresponding pipe. Align dock sockets and click in four snap bridges. Connect each neighboring border seam with two additional snap bridges. Total field face connections: **16 docks + 8 corners**. Release these to transport four rigid 2.15 m borders. Tied workshop splices remain intact.

Retain the previous [grass and hard-surface base arrangements](../BUILD_GUIDE.md): 1.2 m fore–aft feet with opposing staked guys on soil; 2.4 m feet, anti-slip pads, strapped ballast and guys on hard ground. The frame bottom center is now 308.2 mm above face datum; legs grow **8.2 mm** compared with the previous gate when keeping feet at the same height. The earlier 60 kg ballast starting configuration is not a wind rating for this new paper face. Physical anchor, slip, uplift and joint tests remain necessary. Paper is a dry-use consumable; the design does not make ordinary posterboard weatherproof.

## Rebuild

```sh
blender -b -t 8 --python scripts/build_a1_full_size.py
python3 scripts/validate_a1_full_size.py  # also creates the 1:1 fit layout
python3 scripts/slice_a1_full_size.py
python3 scripts/validate_a1_full_size.py
python3 scripts/package_a1_full_size.py
```

Blender source coordinates are meters; CAD calculations and exports use millimeters. Slicing uses locally installed BambuStudio profiles with inheritance/includes resolved. Packaging requires Pillow. The full geometry, ten presentation scenes, BOM, channel map, slicer settings and validation results are included.

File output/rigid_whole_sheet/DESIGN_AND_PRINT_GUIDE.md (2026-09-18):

# Rigid whole-sheet gate / printable assembly prototype

Previous folding comparison committed as `d6d0196`. This iteration uses the user's updated allowance for rigid borders about 2.15 m long.

## Full-size iteration

**Full-size parts audit:** see [FULL_SIZE_PARTS_AUDIT.md](FULL_SIZE_PARTS_AUDIT.md). The two full-length rear rib variants exceed the A1 Mini volume. Connector assemblies and rail/rib joins are not yet a complete production BOM. The miniature and five test-sample checks do not establish full-size kit printability.

Four identical rigid borders, each **2145.6 × 562.8 mm**, form the same pinwheel as whole-sheet option C. Each contains three uncut **711.2 × 558.8 mm (28 × 22 in)** posterboard sheets. Twelve sheets per gate, zero paper cuts. Outside dimension **2708.4 mm**; clear opening **1582.8 mm**. The 4 mm cell allowance still accounts for channel backs and clearance.

**No hinges, hinge pins, offset mounts or fold locks.** Two internal sheet boundaries per border now use permanent straight workshop splices. The loaded borders travel as four long flat sections. Do not bend them to fit a smaller vehicle; allow padding between paper faces. Approximate section thickness is 20–30 mm, subject to final dock design.

Eight removable corner bridge keys (two per seam) join the four borders at the field. Sixteen docks attach the face to the established single PVC backing frame; the four PVC corner braces remain. Internal channel joints stay assembled. Removing folding reduces moving parts, joint play and setup operations, but does not prove sufficient stiffness or wind resistance.

The full-size face still uses slide-in U channels, removable paper end caps, rear cross ribs, workshop nodes, dovetail receivers and accessible release springs. The A1 Mini requires **216 short channel pieces** even without hinges. Removing folding does not remove that workshop assembly labor. The full-size twin-runner corner adapters, rail end-node interfaces and positive PVC keeper still need detailed fit prototypes; they are schematic envelopes in Blender, not a complete production STL kit.

Assembly: set up and anchor/ballast the PVC frame; position the four rigid loaded borders on a flat surface; install eight corner keys; with two people supporting the face, engage sixteen PVC docks. For transport detach the face, release its corner keys, and stack four padded borders. Paper stays installed. Retain the earlier grass-stake and hard-surface ballast/guy arrangements; the small feet in this concept view are not a replacement for those restraints. Use ordinary posterboard as replaceable dry-weather stock.

## Full-size cost estimate

The earlier whole-sheet option estimated 2.370 kg PETG. Removing eight fold assemblies at a 60 g allowance each, including the previous 10% waste factor, saves **0.528 kg**. The new planning figure is **1.842 kg**, or **two 1 kg spools** with about 158 g margin.

At the same $20/kg filament and $0.99/sheet assumptions: approximately **$48.72 consumed face materials**, or **$51.88 cash for two complete spools plus twelve sheets**. This retains the earlier channel, workshop joint, dock and corner-key allowances. It excludes PVC, brace clamps, feet, anchoring, labor, shipping and tax. This is an allowance-based comparison, not a sliced full-size bill of materials; two spools is a target with limited margin, not a guarantee.

## Which scale makes sense?

| Scale | One complete rigid border | Complete gate | Assessment |
|---|---|---|---|
| 1:5 | 429.12 × 112.56 mm | 541.68 mm square | Too long for the A1 Mini as one border; useful only for a single whole-sheet bay (143.04 × 112.56 mm) |
| 1:10 | 214.56 × 56.28 mm | 270.84 mm square | Border still too long |
| 1:12 | 178.80 × 46.90 mm | 225.70 mm square | Nominally inside 180 mm, but little room for positioning/adhesion margin |
| **1:15** | **143.04 × 37.52 mm** | **180.56 mm square** | **Recommended four-piece assembly model; all four borders and eight keys share one plate** |
| 1:16 | 134.10 × 35.18 mm | 169.28 mm square | A complete one-piece display model could fit; loses the useful assembly exercise |

The A1 Mini's official build volume is 180 × 180 × 180 mm. [Bambu documentation](https://cdn1.bambulab.com/documentation/quick-start-f507128172bdf/Quick%20start%20guide%20-%20A1%20mini-EN.pdf)

## What the miniature represents

The miniature preserves the gate's in-plane dimensions at **1:15**, its four rigid borders, sheet boundaries, pinwheel corner seams and two connectors per seam. It is **not** the full-size production STL scaled down. A 0.8 mm printed face represents the paper, a 2.6 mm rim supplies handling strength, and enlarged 3.6 mm sockets accept removable tapered two-peg bridge keys. The miniature uses friction-fit bridges rather than tiny scaled snap springs. Its opening is **105.52 mm**.

This tests proportions, the four-part assembly and connector access. It does **not** test paper sliding, actual PVC attachment, wind strength, full-scale stiffness or latch fatigue. Those need real-stock, full-size interface samples. Scaling a 0.8 mm paper slot by 15 would make it only 0.053 mm wide, which is neither printable with this setup nor appropriate for normal paper.

For real interface checks use the copied **1:1** channel, receiver, shoe, rib and PVC saddle samples in `full_size_fit_samples/`, printed without scaling. They are the earlier provisional coupons. The pipe saddle still needs a positive keeper and final mounting adapter. Test with actual stock/pipe; do not manufacture a whole gate from these samples. Favor in-plane spring flex for FDM rather than through-layer loading. [Formlabs snap-fit guidance](https://formlabs.com/global/blog/designing-3d-printed-snap-fit-enclosures/)

## Printing the miniature

Use a **0.4 mm nozzle, PLA, 0.20 mm layers, supports off**, all parts flat as supplied. Files already contain their final dimensions: **import at 100% scale**, not 6.67%. Check your selected printer, filament and build plate in Bambu Studio before printing. The supplied plate is arranged for printing by layer, not sequentially by object. For adhesion issues, clean the plate and add a modest brim/rearrange as needed.

1. Print `Mini_Fit_Test_and_Feet_LAYOUT.3mf` first. It contains the gauge, one standard key, one looser key and two optional feet. From the gauge's Y=0 end, paired-hole diameters are 3.4, 3.6 and 3.8 mm; the gate uses **3.6 mm**. Try the middle pair. Stop pushing when snug, and confirm you can remove the key. Use the gentler secure fit. If neither works, adjust the key dimensions/XY compensation and retest; do not scale the whole gate to tune the fit.
2. Print `Mini_1to15_Four_Borders_LAYOUT.3mf`: **four identical borders and eight standard keys**, already placed on one bed. If your test favors the looser key, replace the eight keys with eight copies of `mini_bridge_looser_OPTIONAL.stl`. The layout is single-material; colors in Blender distinguish sections only.
3. Lay the borders out in the illustrated pinwheel with the flat faces downward and raised rims upward. Pair the short end of each border with the first portion of its neighbor's long edge. All sixteen bridge pegs have matching holes; the numerical center-alignment check is recorded in `validation.json`.
4. Press two keys into each seam **from the rim side**. Each key straddles the seam and joins one hole in each border. Do not force the wedges fully down to their crossbars. Pull the crossbars to disassemble.
5. Optional: stand the gate in the two feet. Their 3.0 mm open slots accept the 2.6 mm rim. This is a tabletop model, not a fly-through or outdoor test fixture.

Individual STLs are included if you prefer manual placement: print four borders, eight keys and optionally two feet. The solid-geometry PLA estimate for the four borders/eight keys is about **40 g** before slicing effects; use the supplied slicer report for the actual selected profile. **Bambu Studio 2.8.2.61 slicing verification:** complete model plate 35.24 g PLA / about 73 minutes; fit-test-and-feet plate 7.08 g / about 23 minutes, including the profile’s start/end overhead. Both sliced successfully for the A1 Mini 0.4 mm / Generic PLA / 0.20 mm profile, with supports off and no plate warnings. Totals are about 42.3 g and 96 minutes for both plates; actual printing can vary. Open the corresponding `sliced/` 3MF project to inspect the profile and preview before printing.

## Validation and files

`Rigid_Whole_Sheet_Gate.blend`: six scenes, full-size concept and miniature assembly/print layout. `printable/`: geometry-only 3MF layouts and individual STLs. `sliced/`: Bambu Studio A1 Mini / Generic PLA slice projects and estimates. `slicer_profiles/`: resolved copies of the locally installed Bambu presets used for verification. `validation.json`: manifoldness, bounds, mass geometry and peg/socket alignment.

Digital checks do not replace a real fit print. No print job has been sent to the machine.

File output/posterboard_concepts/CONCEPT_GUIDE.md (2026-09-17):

# Uniform posterboard inserts / four folding gate concepts

This Blender package develops the posterboard study into four comparable exoskeleton concepts. The earlier Coroplast gate remains unchanged at `output/FPV_Gate_2700.blend`. These are design options, with seven printable fit coupons—not a complete, load-tested manufacturing kit.

User choices incorporated: small changes to gate size are allowed; transport pieces should be about 1.2 m or shorter; cardstock stays in four folding bundles; printed parts target support-free A1 Mini printing, reversible clicks and rapid field assembly.

## Four options

| Option | Every cardstock insert, mm | Inserts | Stock sheets | Straight cuts¹ | Outer / opening, mm | Folded bundle, approx. mm |
|---|---|---:|---:|---:|---|---|
| A — quarter sheets | 355.6 × 279.4 (14 × 11 in) | 48 | 12 | 36 | 2724.4 / 1590.8 | 1079 × 567 × 40 |
| **B — half sheets** | **355.6 × 558.8 (14 × 22 in)** | **24** | **12** | **12** | **2720.4 / 1594.8** | **1079 × 563 × 40** |
| C — whole sheets | 711.2 × 558.8 (28 × 22 in) | 12 | 12 | 0 | 2708.4 / 1582.8 | 715 × 563 × 65 |
| D — exact gate dimensions | 346 × 196 | 72 | 18 | 90 | 2700 / 1500 | 1050 × 600 × 40 |

¹ Individual straight separations without stacked cutting; repeated knife passes on the same line are not extra cuts. Quartering is one full crosscut plus one cut through each resulting half = three. For D, trim the sheet to 392 × 692, then quarter it: five cuts per sheet. All inserts within each option are identical; no special corner cards or narrow fillers.

**B is the recommended prototype:** twelve cuts total, half as many inserts as A, and one fold rather than C's two. A has smaller individually edge-retained cards and shorter insertion travel; B and C use rear ribs to reach similar nominal support-bay sizes. C minimizes cutting completely but needs eight fold lines across the gate instead of four, and additional rear ribs. D retains the exact prior dimensions but sacrifices the stock-size labor savings.

Stock is nominal 22 × 28 in cardstock at the user's $0.99 price, verified against [Hobby Lobby](https://www.hobbylobby.com/Art-Supplies/Project-Supplies/Poster-Projects/Poster-Board---22-x-28/p/81118411). Confirm actual thickness, size and squareness before choosing slot tolerances. The listing does not supply a weatherproof rating; treat it as replaceable dry-weather material.

## Why the four sections fit together

Four **identical rectangular cassettes** form a pinwheel. If cassette length is L and width is W, outside dimension is L+W and opening is L−W. Each cassette owns one complete outside corner. There are only four cassette-to-cassette seams, rather than four triangular/square infills to assemble separately.

Each cardstock cell uses **paper size + 4 mm** pitch in both directions. Two 1.2 mm channel backs plus 1.6 mm total insertion clearance account for the extra pitch. Card edges sit 2 mm inside the nominal cell boundary and overlap retaining lips by about 4 mm. Consequently the stock-based outer/opening dimensions are slightly different; the model does not hide those changes or pretend paper edges can occupy the same space as rail webs.

The channel sample has a **0.8 mm card slot**, 1.2 mm lips, 6 mm edge capture width and a 10 mm rear spine. A 0.4 mm paper thickness is the working assumption. Measure the actual stock and test before scaling production. Gate geometry uses actual paper dimensions and channel offsets; physical tolerance and factory sheet variation remain to be checked.

## Slide-in loading and repair

Assemble each leaf's side channels and fixed bottom stop on a flat bench. The outer end-cap rail is removable. Slide the cardstock through the parallel side channels, seat it against the stop, then click the end cap back into its rear-accessible receivers. For B and C, rear ribs and light keepers support the center; keepers must permit sliding clearance and support both pressure directions.

For multi-row A and D, replacing an interior card can require unloading its neighboring row first; B and C have only one row and direct access to every card.

Two **opposed U channels** serve a shared paper seam. This uses more plastic than the earlier idealized one-piece H rail but can be printed on the channel spines without an enclosed slot roof. Each U channel is segmented into equal pieces below 150 mm; most options need only two segment lengths. Short release keys and workshop corner nodes keep them joined permanently between flying sessions. The straight channel coupon omits final end-node interfaces; those require the fit-prototype pass after selecting an option.

## Joinery choice and release

Use **load-bearing sliding dovetails with a separate, replaceable in-plane cantilever latch**. The dovetail carries shear and separation loads; the spring only prevents withdrawal and should return near neutral after engagement. The catch has an accessible thumb/thumbnail edge. Press the spring sideways to clear the open notch, then slide the shoe out. No destructive snap tabs or inaccessible one-way barbs are intended.

The female track has a flat print base, an open groove, and 45° inward walls. The male shoe prints with its broad cover on the bed; its runner widens at 45°. The spring lies in the print XY plane. Receiver and shoe STL coupons are actual modeled solids. Their dimensional fit, operating force, wear and cycling still need a real PETG print.

At the four cassette seams, use **two bridge keys per seam**, inserted along the seam from its outer/inner ends after positioning the four cassettes. This avoids the assembly trap of four permanently projecting male dovetails around a closed ring. The bridge uses two parallel receivers; its full twin-runner implementation is a concept in the model, while the supplied single-runner coupon tests the common fit/latch mechanism.

At each fold, two removable bridge locks hold the leaves straight. Hinges position the leaves during folding; the locked bridge interfaces carry the unfolded joint loads. Release controls stay at the rear and clear of the flight opening.

This direction follows published guidance to use favorable layer orientation, stress relief and locating features that unload a snap arm; it is our proposed gate mechanism, not a certified joint. [Protolabs snap-fit guidance](https://www.hubs.com/knowledge-base/how-design-snap-fit-joints-3d-printing/), [Formlabs FDM orientation guidance](https://formlabs.com/blog/designing-3d-printed-snap-fit-enclosures/)

Clickfinity is useful as a modular-joint reference, but the examined implementation uses desk-trapped underside keys. A vertical, vibrating gate needs positively retained keys of its own. [Clickfinity reference](https://github.com/IamMrCupp/clickfinity-openscad/blob/main/README.md)

## Folding and transport

- A and B: six columns per cassette, book-fold between columns three and four. No card crosses a fold. Fold front-to-front; the axis sits in front of the face to leave clearance.
- C: three whole-sheet columns, accordion-fold at both column boundaries. One front-offset and one rear-offset hinge keep the paper flat and allow the rear spines to clear each other. Do not crease the middle of a whole sheet to force a two-leaf fold.
- D: six columns, book-fold after column three. Both halves are 1050 mm long.

The hinge concept uses separate flat printed eye-knuckles plus a removable flat split pin. Printing each eye with its axis vertical avoids horizontal barrel roofs or unsupported interleaved knuckles. The flat fork pin flexes in the bed plane; squeeze its exposed tips to remove it. Two hinges and two straightening locks serve each fold line. Pin/eye play and axial spacing need fit checks; the coupon illustrates the construction rather than supplying a finished hinge-to-rail adapter.

**Transport is four face bundles plus a PVC parts bag.** PVC saddles remain on the pipes, and low docking receivers remain on the faces. The single PVC square splits at four midpoints, giving eight main members below 1.2 m. Commercial inline couplings need positive, quick-release retention; cut lengths must be recalculated from the chosen fittings' actual engagement. Existing 1183 mm hard-surface half-feet are close to the stated transport limit before end caps; remove caps if necessary. The original one-piece 2065 mm PVC rails cannot be carried as-is under this transport requirement.

The 2100 mm PVC frame centerline remains the working baseline. Stock-based cassettes need docking offsets of up to about 29 mm; mounting tabs should accommodate this rather than forcing the paper grid to match the PVC. No second backing square is added. Keep four corner braces. Their new support-free clamp concept uses separate axial-printed pipe rings and a flat 45° link rather than a single underside-grooved block; its interfaces remain to be detailed after the saddle fit test.

## PVC attachment

The coupon is a C-saddle with a nominal **33.9 mm inside diameter** for 33.4 mm OD pipe, printed along the pipe axis. It can flex to admit the pipe; release by spreading its accessible ears. A **positive mouth keeper is required before field use**; the keeper interface is not yet manufactured by the coupon set. Backup tie passages are included. A loose C clip alone is not claimed to resist drone impact or cyclic wind.

Saddles carry docking receivers/shoes, so detaching the face does not require repeatedly flexing the pipe clip. The mounting flange and axial stops must prevent rotation/sliding on the pipes. Those retention details are part of the next prototype pass. PVC, ballast/guy anchors and four braces remain the primary support system; paper and latch springs are not substitutes for it.

## Parts families and support-free orientation

| Part family | Print approach | Status here |
|---|---|---|
| Straight U-channel with rear spine | Lay on 150 × 10 mm spine; channel opens upward | 150 mm coupon; actual assemblies show segment locations |
| Workshop nodes/end-cap receivers | Open features on bed; use the same dovetail/latch interface | Concept geometry; final adapters pending |
| Dovetail receiver | Flat floor down; open groove with 45° walls | Fit coupon supplied |
| Dovetail shoe / spring | Broad plate down, runner up; XY spring | Fit coupon supplied |
| Field bridge and fold lock | Two parallel dovetail runners with rear release | Concept envelope; based on coupon interface |
| Hinge knuckle | Eye axis vertical; separate knuckles | Fit coupon supplied |
| Hinge pin | Flat fork on bed | Fit coupon supplied |
| PVC saddle | Pipe axis vertical; planar ring | Fit coupon supplied; keeper and dock adapter pending |
| Rear ribs | Flat on broad side | Coupon supplied; paper keepers remain to be detailed |

The largest coupon is 150 mm long. All seven coupon STLs are in millimetres and fit the A1 Mini individually with brim room. No support scaffolding is intended. Dovetail overhangs target 45°; everything else uses bed-supported open profiles. Physical slicing and print quality still need confirmation. Do not print a complete gate's quantity from these coupon files.

## Cost / effort update

Support-free channels, four independent cassettes and folding hardware are more substantial than the earlier simplified shared-grid estimate. The current planning model counts channel plastic at **23.52 mm²**, 20% additional channel mass for workshop joints, 250 g for docks, 60 g per fold line, 120 g for the eight field bridge assemblies, rear ribs and 10% printing waste. It is not a slicer-derived BOM.

| Option | PETG planning mass | Whole 1 kg spools | Paper | Consumed materials at $20/kg | Whole-spool cash |
|---|---:|---:|---:|---:|---:|
| A | 3.12 kg | 4 | $11.88 | $74 | $92 |
| B | 2.55 kg | 3 | $11.88 | $63 | $72 |
| C | 2.37 kg | 3 | $11.88 | $59 | $72 |
| D | 3.82 kg | 4 | $17.82 | $94 | $98 |

Excludes PVC, fittings, brace clamps, bases, anchors, labor, power, coatings, shipping and tax. These estimates can change substantially with joint sizes and print settings. PETG density is 1.28 g/cm³; $20/kg is a budget assumption. [Density source](https://eu.store.bambulab.com/en-mt/products/petg-hf?variant=49068714557788)

Approximate equal U-channel segment quantities: A 480, B 336, C 216, D 720. These are slender parts that can be batch printed; the counts are not print-job counts. Long-term assembly labor is moved to the workshop: small nodes and channel joints stay together for transport. The C option avoids paper cuts but adds four fold lines and more release locks, so it does not automatically minimize field labor.

Field sequence for B: assemble/anchor the PVC frame; unfold four face cassettes and engage eight fold locks; lay out the pinwheel and insert eight corner bridges; engage sixteen PVC docks with two people supporting the face; verify locks and wind restraints. Reverse for packing without touching the paper inserts or permanent channel joints.

## What to decide next

Select B unless zero paper cutting (C) or smaller replaceable paper areas (A) outweigh the extra joints/handling. A physical half-sheet stock sample and the channel/dovetail/PVC coupons are the next useful validation, followed by one complete folding cassette. The full-gate material quantities should follow its stiffness, slot-fit and release-cycle results.

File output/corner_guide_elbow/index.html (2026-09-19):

# One more magnet / exact paper alignment

Original designs: CC BY-NC-SA 4.0 · License scope and commercial permissions

A third magnet 18 mm inside both edges, plus a recessed L marking the exact paper corner. Both guy eyes and the accepted 33.5 mm PVC bores remain.

Blender · Assembly PDF · Full guide · Kit

Print one revised elbow: 103.06 g PETG / 239.68 minutes. Fits A1 Mini, no supports. This job has not been opened or sent.

Align paper edges to the centers of the 0.8 mm-wide, 0.4 mm-deep grooves. Install the corner magnet from the rear access well; its 0.4 mm plastic skin remains intact.

05_SINGLE_FRONT

12_SPLIT_S_FRONT

06_STACKED_REAR

11_ALL_PRODUCTION_PARTS

09_PAPER_GUIDES

10_CORNER_MAGNET_SEAT

08_TOP_CORNER_ROUTING

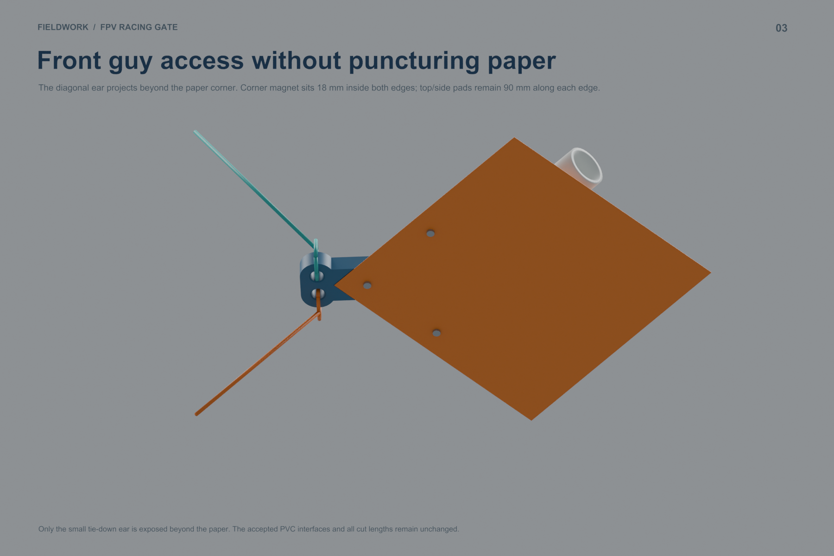
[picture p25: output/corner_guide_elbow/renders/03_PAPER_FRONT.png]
03_PAPER_FRONT


01_DUAL_GUY_PART

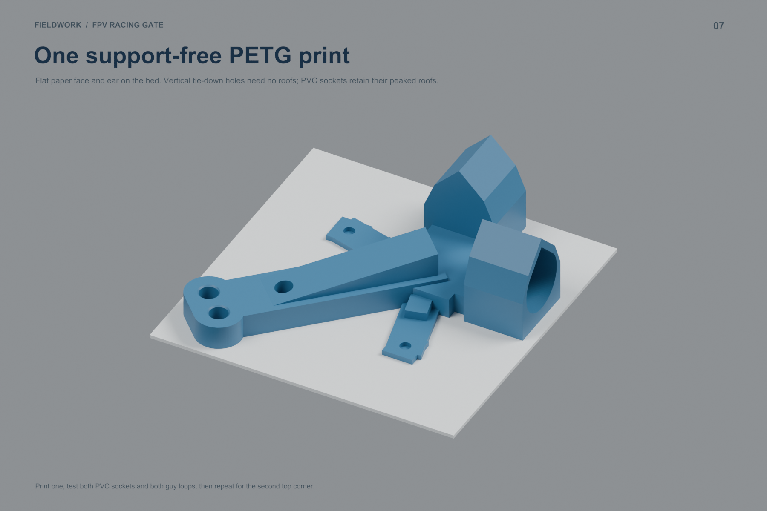
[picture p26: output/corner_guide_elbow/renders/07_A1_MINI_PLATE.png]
07_A1_MINI_PLATE


## Updated fabrication files

single: Printed BOM · Print Queue · PVC Cuts · Magnet Positions · Paper Cuts

split_s: Printed BOM · Print Queue · PVC Cuts · Magnet Positions · Paper Cuts

Geometry probes · Print and assembly checks

Physical guide visibility, socket fit and guy loads require a first-print check.

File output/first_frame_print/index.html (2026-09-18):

# One A1 Mini plate / test the click joints

Print the four-piece test — 80.14 g PETG / 3 h 20 min. Two identical EDGE_BRANCH rails and two CLICK_KEYs. One key joins the rails; the second is a spare. Test straight, release, then rebuild as a T.

Optional five-piece version with one paper pad — 81.63 g / 3 h 24 min. Choose one file, not both.

Assembly and test PDF · Blender scenes · Detailed guide · Download kit

PETG, 0.4 mm nozzle, 0.20 mm layers, four walls, 20% infill, no supports or brim, print by layer. Supplied flat orientations, 100% scale. All pieces fit with at least 5 mm bed margin and slice without warnings. No printer job has been submitted.

Four-piece plate; spare key included.

Four-piece plate; spare key included.

Straight connection, 286.63 mm overall.

Straight connection, 286.63 mm overall.

Reconfigure the same rails and key as a T.

Reconfigure the same rails and key as a T.

Slide the guides along the rail axis. Pinch both hook tips to release.

Slide the guides along the rail axis. Pinch both hook tips to release.

All three part meshes match the current production geometry. Frame-side magnet holders retain the 0.4 mm plastic skin; front PAPER_PAD parts are optional. The peaked sleeve remains unchanged. Physical fit and durability are awaiting this test.

Print checks · Geometry checks · Full gate and later tests

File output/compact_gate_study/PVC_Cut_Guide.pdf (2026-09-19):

# PVC cutting / choose one gate size

Workshop summary. Print the following page for your chosen opening and paper width. Diagrams are not full-size templates.

Nominal 1-inch PVC / accepted 33.5 mm fitting bores / all cut dimensions are finished end-to-end lengths | 1 / 7
Clear opening | Paper width | 8 long pieces | 16 short pieces | Ratchet sticks | Saw plan*
1000 mm | 24 in | 1080.0 mm | 389.6 mm | 5 | 6
1000 mm | 18 in | 1080.0 mm | 237.2 mm | 5 | 5
1000 mm | 12 in | 1080.0 mm | 84.8 mm | 4 | 4
800 mm | 24 in | 880.0 mm | 389.6 mm | 5 | 5
800 mm | 18 in | 880.0 mm | 237.2 mm | 4 | 4
800 mm | 12 in | 880.0 mm | 84.8 mm | 3 | 3

Do not subtract socket insertion from these numbers. Each end inserts 30 mm into its fitting. The cut lengths already include that engagement. They are neither exposed spans nor node-center distances.

For your ratcheting cutter: layouts allow 10 mm per 3048 mm stick for end cleanup, with no saw kerf. Square the starting end, measure each next piece from the new cut end, cut on the waste side of the mark, then check the finished length. Avoid cumulative marks along a full stick.

Before batch cutting: make one short and one long piece, remove burrs, mark 30 mm insertion at each end and dry-fit with the accepted fittings. Use the first accurate piece as a comparison master for repeats. For 12-inch paper the short piece is only 84.8 mm: check that trial corner carefully.

*The existing saw layouts reserve 10 mm per stick plus 3 mm per cut. With the ratchet, the 1000 mm / 24-inch version needs five sticks instead of six. The other stock counts are unchanged. Confirm actual stick length; trim losses beyond the allowance require another layout or spare stock.

These quantities cover the flat gate grid only; feet, ballast structures and other ground supports are additional. All six use the same printed fittings. Label long pieces L1-L8 and short pieces S1-S16.

# 1000 mm opening / 24-inch paper

Outside paper square: 2219.2 mm. Buy 5 sticks of 10-ft nominal 1-inch PVC for the gate grid.

Nominal 1-inch PVC / accepted 33.5 mm fitting bores / all cut dimensions are finished end-to-end lengths | 2 / 7
Mark | Cut quantity | Finished length (mm) | Decimal inches
L | 8 | 1080.0 | 42.5197
S | 16 | 389.6 | 15.3386
S S | S L | S S
L S | L L | L S
S S | S L | S S
S | L | S

S

L

S

Front grid / schematic, not to scale

### Ratcheting cutter / stick-by-stick allocation

Blue = long (L). Orange = short (S). Gray = spare after 10 mm cleanup reserve. Numbers are quantities.

Stick 1 | 2 L | 2 S | 2 L + 2 S | 98.8 mm spare
Stick 2 | 2 L | 2 S | 2 L + 2 S | 98.8 mm spare
Stick 3 | 2 L | 2 S | 2 L + 2 S | 98.8 mm spare
Stick 4 | 1 L | 5 S | 1 L + 5 S | 10.0 mm spare
Stick 5 | 1 L | 5 S | 1 L + 5 S | 10.0 mm spare
Finished-piece check: | Long: 8 | Short: 16

Assembly check: 30 mm insertion at each end. Short-section exposed span = 329.6 mm; long-section exposed span = 1020.0 mm. Finished gate opening = 1000 mm square.
For a hand saw, use the conservative stock-layout CSV linked in the guide; never add saw kerf to a finished part dimension.

# 1000 mm opening / 18-inch paper

Outside paper square: 1914.4 mm. Buy 5 sticks of 10-ft nominal 1-inch PVC for the gate grid.

Nominal 1-inch PVC / accepted 33.5 mm fitting bores / all cut dimensions are finished end-to-end lengths | 3 / 7
Mark | Cut quantity | Finished length (mm) | Decimal inches
L | 8 | 1080.0 | 42.5197
S | 16 | 237.2 | 9.3386
S S | S L | S S
L S | L L | L S
S S | S L | S S
S | L | S

S

L

S

Front grid / schematic, not to scale

### Ratcheting cutter / stick-by-stick allocation

Blue = long (L). Orange = short (S). Gray = spare after 10 mm cleanup reserve. Numbers are quantities.

Stick 1 | 2 L | 3 S | 2 L + 3 S | 166.4 mm spare
Stick 2 | 2 L | 3 S | 2 L + 3 S | 166.4 mm spare
Stick 3 | 2 L | 3 S | 2 L + 3 S | 166.4 mm spare
Stick 4 | 2 L | 3 S | 2 L + 3 S | 166.4 mm spare
Stick 5 | 4 S | 0 L + 4 S | 2089.2 mm spare
Finished-piece check: | Long: 8 | Short: 16

Assembly check: 30 mm insertion at each end. Short-section exposed span = 177.2 mm; long-section exposed span = 1020.0 mm. Finished gate opening = 1000 mm square.

# 1000 mm opening / 12-inch paper

Outside paper square: 1609.6 mm. Buy 4 sticks of 10-ft nominal 1-inch PVC for the gate grid.

Nominal 1-inch PVC / accepted 33.5 mm fitting bores / all cut dimensions are finished end-to-end lengths | 4 / 7
Mark | Cut quantity | Finished length (mm) | Decimal inches
L | 8 | 1080.0 | 42.5197
S | 16 | 84.8 | 3.3386
S S | S L | S S
L S | L L | L S
S S | S L | S S
S | L | S

S

L

S

Front grid / schematic, not to scale

### Ratcheting cutter / stick-by-stick allocation

Blue = long (L). Orange = short (S). Gray = spare after 10 mm cleanup reserve. Numbers are quantities.

Stick 1 | 2 L | 4 S | 2 L + 4 S | 538.8 mm spare
Stick 2 | 2 L | 4 S | 2 L + 4 S | 538.8 mm spare
Stick 3 | 2 L | 4 S | 2 L + 4 S | 538.8 mm spare
Stick 4 | 2 L | 4 S | 2 L + 4 S | 538.8 mm spare
Finished-piece check: | Long: 8 | Short: 16

Assembly check: 30 mm insertion at each end. Short-section exposed span = 24.8 mm; long-section exposed span = 1020.0 mm. Finished gate opening = 1000 mm square.

# 800 mm opening / 24-inch paper

Outside paper square: 2019.2 mm. Buy 5 sticks of 10-ft nominal 1-inch PVC for the gate grid.

Nominal 1-inch PVC / accepted 33.5 mm fitting bores / all cut dimensions are finished end-to-end lengths | 5 / 7
Mark | Cut quantity | Finished length (mm) | Decimal inches
L | 8 | 880.0 | 34.6457
S | 16 | 389.6 | 15.3386
S S | S L | S S
L S | L L | L S
S S | S L | S S
S | L | S

S

L

S

Front grid / schematic, not to scale

### Ratcheting cutter / stick-by-stick allocation

Blue = long (L). Orange = short (S). Gray = spare after 10 mm cleanup reserve. Numbers are quantities.

Stick 1 | 3 L | 1 S | 3 L + 1 S | 8.4 mm spare
Stick 2 | 3 L | 1 S | 3 L + 1 S | 8.4 mm spare
Stick 3 | 1 L | 5 S | 1 L + 5 S | 210.0 mm spare
Stick 4 | 1 L | 5 S | 1 L + 5 S | 210.0 mm spare
Stick 5 | 4 S | 0 L + 4 S | 1479.6 mm spare
Finished-piece check: | Long: 8 | Short: 16

Assembly check: 30 mm insertion at each end. Short-section exposed span = 329.6 mm; long-section exposed span = 820.0 mm. Finished gate opening = 800 mm square.

# 800 mm opening / 18-inch paper

Outside paper square: 1714.4 mm. Buy 4 sticks of 10-ft nominal 1-inch PVC for the gate grid.

Nominal 1-inch PVC / accepted 33.5 mm fitting bores / all cut dimensions are finished end-to-end lengths | 6 / 7
Mark | Cut quantity | Finished length (mm) | Decimal inches
L | 8 | 880.0 | 34.6457
S | 16 | 237.2 | 9.3386
S S | S L | S S
L S | L L | L S
S S | S L | S S
S | L | S

S

L

S

Front grid / schematic, not to scale

### Ratcheting cutter / stick-by-stick allocation

Blue = long (L). Orange = short (S). Gray = spare after 10 mm cleanup reserve. Numbers are quantities.

Stick 1 | 2 L | 4 S | 2 L + 4 S | 329.2 mm spare
Stick 2 | 2 L | 4 S | 2 L + 4 S | 329.2 mm spare
Stick 3 | 2 L | 4 S | 2 L + 4 S | 329.2 mm spare
Stick 4 | 2 L | 4 S | 2 L + 4 S | 329.2 mm spare
Finished-piece check: | Long: 8 | Short: 16

Assembly check: 30 mm insertion at each end. Short-section exposed span = 177.2 mm; long-section exposed span = 820.0 mm. Finished gate opening = 800 mm square.

# 800 mm opening / 12-inch paper

Outside paper square: 1409.6 mm. Buy 3 sticks of 10-ft nominal 1-inch PVC for the gate grid.

Nominal 1-inch PVC / accepted 33.5 mm fitting bores / all cut dimensions are finished end-to-end lengths | 7 / 7
Mark | Cut quantity | Finished length (mm) | Decimal inches
L | 8 | 880.0 | 34.6457
S | 16 | 84.8 | 3.3386
S S | S L | S S
L S | L L | L S
S S | S L | S S
S | L | S

S

L

S

Front grid / schematic, not to scale

### Ratcheting cutter / stick-by-stick allocation

Blue = long (L). Orange = short (S). Gray = spare after 10 mm cleanup reserve. Numbers are quantities.

Stick 1 | 3 L | 4 S | 3 L + 4 S | 58.8 mm spare
Stick 2 | 3 L | 4 S | 3 L + 4 S | 58.8 mm spare
Stick 3 | 2 L | 8 S | 2 L + 8 S | 599.6 mm spare
Finished-piece check: | Long: 8 | Short: 16

Assembly check: 30 mm insertion at each end. Short-section exposed span = 24.8 mm; long-section exposed span = 820.0 mm. Finished gate opening = 800 mm square.

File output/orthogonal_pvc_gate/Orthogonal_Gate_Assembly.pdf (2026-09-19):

Friction-fit PVC gate / fabrication prototype / 2026-09-17 | 1

# Three-type PVC gate / friction fit

Single: 4 elbows, 12 crosses, 48 magnetic sleeves. 2.528 kg PETG / 102.2 printer-hours / eight $6 PVC sticks. PVC + PETG subtotal $98.57 at $20/kg; paper, magnets and ground support additional.

Equal 609.6 mm paper bands; 2700 mm square outside and 1480.8 mm opening. All joining and sleeve location use friction. First confirm the bore with the actual pipe. The following views and instructions cover the single and its two-level extension.

# Three required printed types

Elbow only at the four overall outside corners. Universal cross at every other junction; unused sockets remain empty. One sleeve design holds every intermediate magnet. Front pads are optional.

# First test plate

Five pieces / 126.20 g / 4.97 hours. Label the three full-length coupons before removing them: 33.3, 33.5 and 33.7 mm from front to rear. The included elbow uses 33.5 mm.

# Straight sockets / one square band

Pipe ends engage 30 mm. Stops are 35 mm from node centers. A 389.6 mm pipe gives 459.6 mm center spacing across a 609.6 mm paper band. Both printed faces must be coplanar.

# Positioning and paper attachment

Thread sleeves before end fittings. Clock flat faces against a straightedge. Rear magnet / 0.4 mm plastic / paper / bare front magnet. Magnet centers are 18 mm from paper edges. Test rotation resistance on actual PVC.

# Single frame / row-by-row assembly

Four horizontal rows, each with short / long / short PVC. Build each row first, then engage four vertical members and the next row together. Work flat and seat evenly against the 30 mm insertion marks.

# Same borders / two openings

2700 x 4790.4 mm before feet. The one shared middle band remains 609.6 mm wide. Paper and magnets cover the complete front projection.

# Reuse the single gate

Add 8 crosses, 32 sleeves, 8 short and 6 long pipes. Move the complete top row upward. Double total: 4.031 kg PETG / 163.3 hours / fourteen PVC sticks. All original pipe lengths are reused.

# Shared divider / standard crosses

Move the old top row to the new top. Two new all-cross rows form the upper divider edge and the upper opening top edge. Divider axis heights are 2165.4 and 2625 mm from the paper bottom.

Friction-fit PVC gate / fabrication prototype / 2026-09-17 | 10

# Fabrication quantities

Part | Single | Double Print bounds mm
ELBOW | 4 | 4 | 133.314 x 133.314 x 53.345
CROSS | 12 | 20 | 136.627 x 136.627 x 53.345
MAG_SLEEVE | 48 | 80 | 20.0 x 86.75 x 53.345
Configuration | Pieces PETG kg | Hours | Runs | PVC | Subtotal
single | 64 | 2.528 | 102.2 | 23 | 8 / $48 | $98.57
split_s | 104 | 4.031 | 163.3 | 36 | 14 / $84 | $164.63
The three-type grid costs more material and print time than the prior five-type corded design. Its benefit is simpler assembly and inventory. Counts exclude optional front pads and prototype tooling. Ground support is separate. See the CSV ledgers for exact labeled cuts and plate recipes.
Recipe | Single runs | Double
runs
Pieces/run | g/run | h/run
ONE_ELBOW | 4 | 4 | 1 | 68.47 | 2.69
ONE_CROSS | 12 | 20 | 1 | 132.59 | 5.07
BATCH_MAG_SLEEVE | 6 | 11 | 7 | 96.74 | 4.46
TAIL_MAG_SLEEVE_6 | 1 | 0 | 6 | 82.93 | 3.85
TAIL_MAG_SLEEVE_3 | 0 | 1 | 3 | 41.5 | 2.07

Friction-fit PVC gate / fabrication prototype / 2026-09-17 | 11

# Assembly and test instructions

## First print and fit test

FIRST_FRICTION_FIT_A1Mini_PETG.3mf: 126.20 g / 4.97 hours. Five pieces: one 33.5 mm-bore ELBOW, full 30 mm-long FIT_333 / FIT_335 / FIT_337 coupons, and one optional PAPER_PAD. The three samples are 33.3 / 33.5 / 33.7 mm bores, ordered from front to rear on the right side of the plate. Label them before removing them. The coupons have no end stop; test 30 mm engagement. Their shape and print orientation match the sockets.

1. Measure and deburr an actual pipe offcut. Test each coupon by hand; choose the fit that seats the full 30 mm and releases deliberately while resisting pull-out and rotation. Do not hammer a tight sample onto the pipe. If none meets that behavior, revise the bore rather than accepting a loose or forced fit.
2. Test both elbow sockets to their stops, with a 30 mm insertion mark on each pipe. Check that the elbow stays square and its paper face stays flat. Repeat fitting and release at least 20 times; check for cracking, whitening, increasing looseness and movement past witness marks.
3. The supplied elbow and production files use 33.5 mm. If another sample fits better, regenerate with PVC_FIT_BORE set to that diameter and re-slice before production. Do not scale an STL; that also changes centers, magnet pockets and cut lengths.
4. Then print CROSS_AND_SLEEVE: 146.39 g / 5.70 hours. It tests all four socket directions and the shorter sleeve. A coupon result alone does not prove sleeve grip.
5. For a two-foot band demonstration, join the elbow to the cross with one 389.6 mm pipe and place the sleeve at 194.8 mm from its cut end. Orient both printed faces into the same plane. The elbow's outward pad and the cross's opposite-side pad span the paper band with 18 mm edge margins. Lay a 609.6 mm-wide paper strip over them and mark the 18 mm margins. Use six magnets for three grip sites, adding a short perpendicular pipe offcut to each fitting to test square alignment.
6. Bond rear magnets after checking polarity; let the adhesive cure. Test magnetic grip with the real paper, both a bare front magnet and the optional front pad. Pull/rotate the sleeve, flex the paper gently and repeat assembly. After that passes, build one short square grid cell (four 389.6 mm pipes, one elbow, three crosses) flat and check racking and joint withdrawal before producing the complete gate.

The fit and handling tests above are prototype checks, not a rated wind/load test. The first two test plates are separate from the production queue below; accepted production pieces from them can count toward the final BOM.

## Full production queue

Each CSV queue links to the corresponding prepared PETG 3MF. BATCH_MAG_SLEEVE holds seven identical sleeves; it is one part type. The six- and three-piece tails avoid overprinting. All plates passed the bed-clearance, non-overlap and support-off slicing checks. Open prepared 3MFs as projects and confirm your actual filament profile before printing. No job has been sent to a printer.

## PVC cuts and assembly

Only two finished pipe lengths are used: 389.6 mm and 1560.8 mm. The single needs 16 short + 8 long; the double needs 24 short + 14 long. Their respective center spacings are 459.6 and 1630.8 mm, because the two stop offsets add 70 mm. The longest loose pipe is 1.561 m.

The stock ledgers reserve 10 mm total end allowance per stick and 3 mm kerf per cut. Two long pieces cannot fit one 3048 mm stick, so eight long pieces require at least eight sticks; fourteen require fourteen. All short pieces fit alongside those long pieces. Label cuts using PVC_Cuts.csv; node coordinates and Assembly_Map.svg use the front view, measured from the bottom-left paper corner.

Friction-fit PVC gate / fabrication prototype / 2026-09-17 | 12
1. Print and qualify the selected fit, then cut, deburr and label all PVC. Mark 30 mm engagement at both ends. Mark sleeve stations from Sleeve_Positions.csv before covering the cut starts with fittings.
2. Slide one sleeve onto each short pipe, centered at 194.8 mm from its cut start. Put four sleeves on each long pipe at 291.16, 617.32, 943.48 and 1269.64 mm from the cut start. Rotate them to the direction shown in Blender; their flat paper faces must be coplanar with the fitting faces. The sleeve positions are clear of every socket.
3. Work on a flat surface with all paper-facing surfaces down. Build each horizontal row from four nodes and three pipes in short / long / short order. The single has four rows at y = 75, 534.6, 2165.4 and 2625 mm. Only the ends of its bottom/top row use elbows; every other node is a cross. A node's unused cross socket simply stays empty.
4. Place four vertical pipes into each row, then press the next complete row onto them together, keeping the mating sockets aligned. Single vertical gaps use short / long / short pipes, from bottom to top. Seat all four connections evenly to their marks; avoid levering one partially engaged socket to close another. Check equal diagonals and coplanar paper pads as each row goes on.
5. Populate only the magnet pockets shown by Magnet_Positions.csv. The cross has four available pads for symmetry, but not all are used at every node. A straightedge across the fixed fitting pads helps clock the sliding sleeves; mark accepted positions on the pipe for repeat assembly.
6. Install the paper as described below. For transport, remove the paper and separate rows/long members as needed, pulling at socket bodies. Leave sleeves on their labeled pipes. Fully assembled horizontal rows are about 2.7 m wide, so remove an end stub or separate at an inner cross to remain within the earlier approximately 2.15 m transport size.

## Paper and magnets

Use untrimmed 609.6 mm roll width. Single: two 2700 mm horizontal bars and two 1552.8 mm side inserts. Double: three 2700 mm bars and four 1552.8 mm inserts. Each side insert overlaps a horizontal bar by 36 mm at each end. Consumption is 8.5056 m per single or 14.3112 m per double: three singles or two doubles from a 100-ft roll, before cutting waste.

Lay horizontal bars first, then side inserts. Align paper edges 18 mm beyond the corresponding magnet centers. The straight short PVC links carry magnets along the overlap seams, so no suspended seam parts are needed. Use 72 magnet pairs / 144 magnets for a single, or 116 pairs / 232 magnets for a double, all 6 mm diameter x 2 mm thick. Long-span sleeve spacing is 326.16 mm; grip at that spacing needs testing with the actual roll.

The stack is rear magnet -> 0.4 mm frame plastic -> paper -> bare front magnet. Frame pockets remain 6.3 mm diameter and are rear-loaded. Secure rear magnets with a compatible adhesive; the pocket clearance is not a guaranteed press fit. Check polarity before bonding. Only populate selected pockets. The bare front magnets align directly with the fixed rear magnets. The existing PAPER_PAD is an optional handle/protector around a front magnet; it adds another 0.4 mm skin and is excluded from the BOM, mass and time totals.

## Extend to the two-level gate

Reuse every existing pipe without cutting, all 48 sleeves, all 12 crosses and all four elbows. Add 8 CROSS + 32 MAG_SLEEVE, 8 short + 6 long PVC cuts, and 44 magnet pairs / 88 magnets. The additional PVC needs six more 10-ft sticks. Add one 2700 mm paper bar and two 1552.8 mm side inserts.

Lay the single frame flat and remove its paper. Detach its complete top horizontal row (both elbows, both crosses, all three pipes and their sleeves) from the four short verticals below it. Move that complete row upward to the new top height, y = 4715.4 mm. This preserves its populated magnet pads and sleeve directions together; label its new node positions using the double map.

Friction-fit PVC gate / fabrication prototype / 2026-09-17 | 13

Build a replacement all-cross row at the old top height, y = 2625 mm, using four new crosses and short / long / short pipes. It becomes the upper row of the shared divider. Add four long verticals to a second new all-cross row at y = 4255.8 mm, also using four new crosses and short / long / short horizontal pipes. Add four short verticals above it and seat the retained top row onto them. This accounts for all eight additional crosses, six long pipes and eight short pipes. No special divider fitting is required.

The divider's two pipe rows are y = 2165.4 and 2625 mm: 459.6 mm axis spacing, supporting the same 609.6 mm band as every other border. Use the double assembly and magnet maps when relocating/populating magnets at the former top edge.

## What is checked and what remains

Digital checks cover connected manifold masters, actual A1 Mini placements, no overlapping plate parts, no generated supports or slicer warnings, exact queue quantities, socket-free sleeve positions, backing-pocket alignment, front concealment, orthogonal PVC, and reuse of all single-height pipe lengths on extension. Nine Blender scenes show both finished faces, both PVC frames, the three part types, connections, magnetic stack, first test plate and shared divider.

This is a friction-fit face-frame prototype. Actual pull-out, sleeve rotation, PETG wear, paper grip and frame racking still require physical tests. Feet and ground restraint for soil or hard surfaces have not been sized in this iteration; the 4.79 m frame is not yet a qualified freestanding outdoor obstacle. No cord is included in this design.

## References and regeneration

- FORMUFIT PVC sizing explains nominal pipe size versus OD; nominal 1-inch PVC is approximately 1.315 inches outside diameter. Measure the actual pipe used for this print.
- Prusa modeling guidance covers print orientation, overhangs and tolerances. The peaked sockets and proposed clearances are this project's prototype geometry.

Regenerate with scripts/build_orthogonal_pvc_gate.py in Blender, then scripts/slice_orthogonal_pvc_gate.py, scripts/validate_orthogonal_pvc_gate.py and scripts/package_orthogonal_pvc_gate.py. Set PVC_FIT_BORE on the Blender build command to change the bore. The package script uses ReportLab. A changed bore requires rebuilding and re-slicing; the supplied files currently use 33.5 mm.

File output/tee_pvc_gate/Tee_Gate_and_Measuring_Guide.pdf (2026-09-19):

FPV PVC gate / tees, guy eyes and measuring tools / 2026-09-18 | 1

# 33.5 mm accepted / new fittings and measuring tools

The successful magnetic sleeve is unchanged. Add a material-saving tee, an elbow with a rear guy eye at each top corner, and a two-head marking jig for the Husky ratcheting cutter.

Single gate: 2.273 kg PETG / 92.6 hours. Net saving versus the previous version: 255 g and 9.7 hours. Workshop tools are additional.

FPV PVC gate / tees, guy eyes and measuring tools / 2026-09-18 | 2

# Print the two-head marking kit

JIG_ZERO + JIG_MARK only: 80.89 g / 3.29 hours. The optional 30 mm depth gauge is a separate job or part of the expanded kit.

FPV PVC gate / tees, guy eyes and measuring tools / 2026-09-18 | 3

# A full-length gauge on existing PVC

Set the head datum faces 1560.8 mm apart for long cuts, or 389.6 mm for short cuts. Use a trusted metric tape for the initial setting. Keep the PVC rail straight and supported. Friction retains the heads; watch the witness marks.

FPV PVC gate / tees, guy eyes and measuring tools / 2026-09-18 | 4

# Locate the actual zero face

Butt the pipe gently against the inside end-stop face. Measure from this face to the near face of the marking collar. Hold the marking head while feeding or withdrawing stock. Rotate the stock against the stop to mark around it.

FPV PVC gate / tees, guy eyes and measuring tools / 2026-09-18 | 5

# Use the Husky cutter off the jig

Mark first, remove the stock, then cut. Check the finished trial piece and adjust the marking head for the measured error. DEPTH_30, at right, is optional and marks 30 mm socket insertion depth.

FPV PVC gate / tees, guy eyes and measuring tools / 2026-09-18 | 6

# Replace only the three-way intersections

A tee saves 34.10 g and 77.8 minutes versus a cross. The same tee rotates around all four outside edges. Its absent branch faces outward; its two magnetic pads remain behind the paper.

FPV PVC gate / tees, guy eyes and measuring tools / 2026-09-18 | 7

# Attach guys to the thick elbow body

The 10.5 mm peaked passage is in a 14 mm-thick eye rooted directly in the central core. Use GUY_ELBOW at the two top outside corners. Thread through the eye, not the magnet arm. Physical load testing and installation sizing remain outstanding.

FPV PVC gate / tees, guy eyes and measuring tools / 2026-09-18 | 8

# Single gate with tees and top eyes

2 bottom elbows, 2 top guy elbows, 8 tees, 4 crosses and 48 magnetic sleeves. All pipe bores stay 33.5 mm; the 389.6 / 1560.8 mm cuts and paper dimensions are unchanged.

FPV PVC gate / tees, guy eyes and measuring tools / 2026-09-18 | 9
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

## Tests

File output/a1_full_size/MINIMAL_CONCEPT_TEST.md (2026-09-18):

# Smallest useful first concept test

[Download the two-part assembly and test PDF](Assembly_and_Test_Instructions.pdf).

Print **one of each of these nine parts**, at full size:

| Part | Quantity | What it tests |
|---|---:|---|
| CHANNEL_LONG | 1 | Paper slot and long-channel geometry |
| CHANNEL_SHORT | 1 | Short-channel geometry; mate for splice/corner tests |
| SPLINT | 1 | Registered straight channel splice |
| CORNER_NODE | 1 | A 90-degree paper-frame corner |
| RIB_H_LOW_DOCK | 1 | Paper-contact shoe and actual rib-to-dock mounting holes |
| DOCK_PEDESTAL | 1 | Standoff and clearance under the snap |
| DOCK_CAP | 1 | Rib-side snap socket |
| PIPE_33 | 1 | Clip fit on 1-inch nominal / 33.4 mm OD PVC |
| SNAP_BRIDGE | 1 | Connecting and releasing the complete PVC dock |

[Open the sliced A1 Mini test plate](sliced/Minimal_Concept_Test_9_Parts/Minimal_Concept_Test_9_Parts_A1Mini_PETG.3mf), or [download the geometry-only layout](printable/Minimal_Concept_Test_9_Parts.3mf). **32.4 g PETG, approximately 95 minutes.** One plate, 0.4 mm nozzle, 0.20 mm layers, three walls, 15% infill, Textured PEI Plate, supports off. Verify your filament and plate settings before printing. All nine parts have been volume-checked and sliced with no warnings; no physical print is claimed.

Bring your actual posterboard, a short piece of 1-inch nominal PVC (33.4 mm outside diameter), six narrow 2.5 mm ties, and one approximately 3.6 × 250 mm pipe keeper tie. Releasable ties make the sequential tests easier. You do not need to cut up a complete posterboard sheet: use its edge and corner.

1. Slide the paper edge into each channel and check for free movement without creasing. Clear burrs rather than forcing the paper.
2. Place the two channels end-to-end with a 0.2 mm gap. Seat the splint's four bosses in the end windows and retain it with two ties. Long-to-short is a test combination; production uses the same interface between equal-length channels. Check sliding and bending by hand.
3. Remove the splint and rearrange the same channels at 90 degrees, with each channel starting 6.1 mm back from the virtual corner. Seat the CORNER_NODE with its fences against the inward channel spines, and tie each arm to its channel. Check paper fit at the corner. This samples the sheet-frame corner, not a full field seam between borders.
4. Assemble the dock: pedestal on the broad docking rib, cap on top, two ties through their matching holes. The pedestal's open space must remain under the cap's central socket. Seat PIPE_33 on the PVC and install its keeper tie. Align the cap and pipe-saddle sockets at 24 mm centers, with their rear surfaces level, then insert SNAP_BRIDGE until both rigid stops seat.
5. Check that the dock retains the rib and releases repeatedly. Pinch one fork and lift that end, then the other. Assess finger access in the assembled dock; blunt tweezers can help diagnose fit. Stop if a prong cracks or permanently bends. The rib shoe can also be checked against the back of the paper for sharp edges.

The same parts are reused between tests. This is the smallest useful **paper / splice / corner / complete dock** test, not a full test of long-rib stiffness or the assembled gate.

Optional second-stage additions:

- **Brace endpoint:** add one BRACE_LINK_45 and one PIPE_27. Reuse PIPE_33 from the dock test, and bring a piece of 3/4-inch nominal PVC (26.67 mm OD), four heavy brace-link ties and a second pipe keeper tie. This tests one printed brace-end joint.
- **Rear rib joints:** add one each of RIB_H_HIGH, RIB_V_HIGH, RIB_CROSS and RIB_ANCHOR. Reuse RIB_H_LOW_DOCK to test a lap joint, then the lower cross seat; use RIB_V_HIGH on the raised cross seat. Test the anchor against a long channel's center mounting windows. Reuse components between these checks.

A complete sheet bay is the next structural prototype after these interfaces work. Neither this small set nor the tabletop miniature establishes full-sheet flutter, border racking or wind performance.

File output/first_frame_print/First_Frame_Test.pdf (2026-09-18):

FPV gate / first frame interface test / production scale 1:1 | 1

# First frame print / A1 Mini

Recommended: FIRST_FRAME_TEST_A1Mini_PETG.3mf
Two identical EDGE_BRANCH rails + two identical CLICK_KEYs.
80.14 g PETG / about 3 h 20 min / one plate / four pieces.

Optional alternative: FIRST_FRAME_TEST_WITH_PAD_A1Mini_PETG.3mf adds one PAPER_PAD. Five pieces / 81.63 g / 3 h 24 min. Print one file, not both.

A1 Mini, 0.4 mm nozzle, PETG, 0.20 mm layers, 4 walls, 20% infill, no supports/brim, print by layer. Open as a project; use 100% scale and the supplied flat orientation. Render colors are illustrative; one filament prints everything. Select your actual PETG preset and re-slice if it differs.

5 mm minimum bed margin; 29 mm maximum height. All meshes match the production parts. The second key is a spare/comparison. No extra hardware is needed for this click test.

FPV gate / first frame interface test / production scale 1:1 | 2

# 1 / Connect the rails end-to-end

## Prepare

Cool and remove the print. Clear loose strings and first-layer burrs from the receiver and the two central spring prongs. Preserve the hook shoulders. Keep the spare key untouched for comparison.

## Slide and latch

Keep smooth paper faces coplanar and both side branches facing the same direction. Insert the key along the rail axis. The wide outside runners guide it; the central fork flexes inward and springs outward behind the receiver shoulders. Check both hooks at each end. Support close to the joint when pressing.

## Check

The straight assembly is 286.63 mm long. Apply a gentle axial hand pull and check for unintended release or obvious play. Check slight bending near the joint. Stop if cracking or whitening appears. Do not use the full rail length as a bending lever.

FPV gate / first frame interface test / production scale 1:1 | 3

# 2 / Release, then build the T joint

## Release

Access the central fork from the open back. Press both hook tips inward toward the center and withdraw straight. Repeat at the other end. Do not twist or pry upward. If comfortable hand release is not possible, record the problem instead of forcing it.

## Reconfigure

Move the same key into the projecting side receiver of one rail. Attach an end of the second rail at 90 degrees, with both paper faces in the same plane. This is the actual gate crossmember interface. The two configurations are tested successively, not assembled simultaneously.

## Repeat

Perform 20 assembly/release cycles in each configuration, then compare the spare key. Record receiver tightness, release access, increasing play, whitening, cracking or permanent prong bending. Success means both hooks latch reliably and release by hand without damage. This is an initial screen, not a strength or fatigue rating.

FPV gate / first frame interface test / production scale 1:1 | 4

# 3 / Alignment and optional magnet test

Slide the guides along the rail axis; do not push the key down from above. Test results should identify whether an end receiver, side receiver or particular key needs adjustment. Keep all parts at 100% scale.

## Paper pads are optional

For a local paper-grip comparison, add two 6 x 2 mm magnets and paper. Check polarity before fixing magnets with compatible adhesive. Without a pad: rear magnet / unchanged 0.4 mm frame skin / paper / bare front magnet. With a pad: rear magnet / frame skin / paper / 0.4 mm pad skin / front magnet. The pad offers a larger contact area and a handle; compare grip, marking and removal. Reuse the front magnet between tests before bonding, or use a third magnet.

## Next stage

After click fit passes, test one RUNG_SLEEVE with actual PVC, then the 609.6 mm-wide braced bay in the full gate guide. The peaked sleeve roof is unchanged. These parts are reusable in the gate. This first plate tests joinery, not full-width rigidity or wind performance. No physical prototype has been tested here.

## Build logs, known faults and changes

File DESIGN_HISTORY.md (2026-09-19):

# Design history and earlier prototypes

Historical snapshots retain the assumptions and prices used at the time. Use the [project README](README.md) and latest corner-guide files for current specifications and costs.

Workshop status (2026-09-19): the 33.5 mm magnetic sleeve fit is physically confirmed. The next selected production print is **ONE_TEE in PETG**; it was opened in Bambu Studio, with completion not yet reported. Use checked PVC master pieces for repeat cut marking; the printed measuring jig is optional and deferred. See [recorded build status](output/tee_pvc_gate/BUILD_STATUS.md).

**Current corner-magnet and paper-guide revision:** [rendered views](output/corner_guide_elbow/index.html), [Blender](output/corner_guide_elbow/Corner_Guide_Elbow.blend), and [assembly PDF](output/corner_guide_elbow/Corner_Guide_Elbow.pdf). Each top elbow now has three magnet seats: top, side and corner. A recessed L (0.8 mm wide, 0.4 mm deep) marks the exact paper corner and edge centerlines. The corner magnet remains behind a 0.4 mm skin, with a 10 mm rear access well. Both guy eyes and 33.5 mm PVC bores remain. [One-elbow A1 Mini PETG job](output/corner_guide_elbow/sliced/ONE_DUAL_GUY_ELBOW/ONE_DUAL_GUY_ELBOW_A1Mini_PETG.3mf): **103.06 g / about 4 hours**, no supports. Single: 76 magnet pairs; stacked: 120. Geometry, alignment probes and slicing pass; first-print checks remain. The earlier files are preserved.

**Previous two-magnet dual-guy elbow revision:** [visual views](output/dual_guy_gate/index.html), [Blender model](output/dual_guy_gate/Dual_Guy_Gate.blend), and [assembly/test PDF](output/dual_guy_gate/Dual_Guy_Assembly.pdf). A reinforced diagonal ear has two independent through-eyes for simultaneous front/rear guys; top and side magnet holders replace the corner holder. The ear extends about 28.6 mm outside the paper so neither line needs a paper cutout. All PVC bores remain **33.5 mm**; other production STLs are unchanged. [Print one revised elbow](output/dual_guy_gate/sliced/ONE_DUAL_GUY_ELBOW/ONE_DUAL_GUY_ELBOW_A1Mini_PETG.3mf): **102.57 g PETG / about 3 h 57 min**, support-free on the A1 Mini. Two per gate, adding 50.36 g / 1.81 hours and four individual magnets versus baseline. Single total: **2.324 kg / 94.4 hours**; stacked: **3.690 kg / 150.3 hours**. Digital geometry and routing checks pass; physical socket and guy-load tests remain. No new print was opened or submitted. The preceding design and workshop status were committed as **6a7fb47** before this revision.

**Committed tee baseline:** [tees, top guy elbows and the PVC measuring jig](output/tee_pvc_gate/index.html), [Blender model](output/tee_pvc_gate/Tee_PVC_Gate.blend), and [measuring/assembly PDF](output/tee_pvc_gate/Tee_Gate_and_Measuring_Guide.pdf). **The 33.5 mm sleeve fit was physically accepted on 2026-09-18; its STL is unchanged.** New tees replace eight crosses per single gate, and the two top elbows have integral guy eyes. Five gate types / 64 pieces single / 104 stacked. Single: **2.273 kg PETG / 92.6 hours**; stacked: **3.640 kg / 148.5 hours**. Net savings versus the preceding design: **255 g / 9.7 hours single**, **391 g / 14.9 hours stacked**. [Two-head measuring plate](output/tee_pvc_gate/sliced/MEASURING_KIT/MEASURING_KIT_A1Mini_PETG.3mf) uses existing PVC and a tape-calibrated spacing to mark the 389.6 and 1560.8 mm cuts; remove the marked pipe before using the Husky ratcheting cutter. [Print one tee](output/tee_pvc_gate/sliced/ONE_TEE/ONE_TEE_A1Mini_PETG.3mf) or [one top guy elbow](output/tee_pvc_gate/sliced/ONE_GUY_ELBOW/ONE_GUY_ELBOW_A1Mini_PETG.3mf). All supplied plates fit the A1 Mini and slice without supports. New fitting/tool performance and eye loads await physical tests.

**Previous all-cross friction-fit iteration:** [visual study and fabrication files](output/orthogonal_pvc_gate/index.html), [Blender model](output/orthogonal_pvc_gate/Orthogonal_PVC_Gate.blend), and [assembly/test PDF](output/orthogonal_pvc_gate/Orthogonal_Gate_Assembly.pdf). **Three required printed types: elbow, cross, magnetic sleeve.** Single: 4 / 12 / 48 pieces, **2.528 kg PETG / 102.2 print-hours / eight $6 PVC sticks**. Stacked: 4 / 20 / 80, **4.031 kg / 163.3 hours / fourteen sticks**. PVC + PETG at $20/kg: **$98.57 / $164.63**, excluding magnets, paper and ground support. Equal 609.6 mm paper bands, orthogonal PVC only, friction retention throughout. Simpler assembly but more material than the corded version. [First fit plate](output/orthogonal_pvc_gate/sliced/FIRST_FRICTION_FIT/FIRST_FRICTION_FIT_A1Mini_PETG.3mf): **126.2 g / 4 h 58 min**. The provisional 33.5 mm bore needs actual-pipe testing; all supplied plates fit the A1 Mini and slice without supports. Ground-support sizing remains outstanding.

**Previous corded PVC iteration:** [single gate and two-level Split-S study](output/pvc_paper_gate/index.html), [Blender model](output/pvc_paper_gate/PVC_Paper_Gate.blend), and [design/assembly PDF](output/pvc_paper_gate/PVC_Gate_Study.pdf). Recommended single: **62 printed pieces / 5 types / 1.759 kg PETG / 71 hours / six $6 PVC sticks**. Two-level: **108 pieces / 2.814 kg / 115 hours / ten sticks**. Paper conceals both PVC perimeters; front magnets align with backing pockets. All pipes in the recommended version are below 2 m and are reused on extension. Face-only material subtotals at $20/kg PETG: **$71 single / $116 double**, excluding paper, magnets, cord and anchoring. Ground-support engineering and physical testing remain outstanding. [First PVC fit plate](output/pvc_paper_gate/sliced/FIRST_FIT/FIRST_FIT_A1Mini_PETG.3mf): 124.6 g / about 4 h 57 min. The preceding print-track iteration is committed as `eda5b20`.

**Previous track prototype:** [four-piece A1 Mini click-joint test](output/first_frame_print/index.html) — two identical branch rails and two keys, **80.14 g PETG / about 3 h 20 min**. Test a straight connection, release it, then build a T with the same parts. [Prepared 3MF](output/first_frame_print/sliced/FIRST_FRAME_TEST/FIRST_FRAME_TEST_A1Mini_PETG.3mf), [assembly/test PDF](output/first_frame_print/First_Frame_Test.pdf), [Blender scenes](output/first_frame_print/First_Frame_Print.blend). An alternate plate includes one optional paper pad.

Current attachment iteration: [one-piece PVC sleeve integrated into the frame rung](output/sleeve_paper_gate/index.html), with [Blender model](output/sleeve_paper_gate/Sleeve_Paper_Gate.blend) and [assembly PDF](output/sleeve_paper_gate/Sleeve_Gate_Assembly.pdf). No bolts, nuts or additional cord stays at the face-to-PVC attachment. **With optional front paper pads: 560 pieces / 8 types / 6.995 kg PETG / 286 printer-hours; without pads: 424 / 7 / 6.792 kg / 277 hours.** The frame-side magnet holders retain their plastic skin, and the sleeve retains its peaked roof. After the click test, use [one sleeve print](output/sleeve_paper_gate/sliced/Q_RUNG_SLEEVE_TAIL/Q_RUNG_SLEEVE_TAIL_A1Mini_PETG.3mf): 49.4 g, about 2 h 20 min. This replaces the bolted dock in the preceding iteration.

Preceding bolted-dock iteration: [reinforced paper gate with integral paracord cleats](output/full_paper_gate/index.html), [Blender assembly](output/full_paper_gate/Full_Paper_Gate.blend), and [full assembly PDF](output/full_paper_gate/Full_Gate_Assembly.pdf). **624 pieces / 10 types / 7.13 kg PETG / 295 printer-hours / 112 plate runs.** The new side socket preserves a continuous spine. All parts fit the A1 Mini and slice without supports. Physical testing remains outstanding.

Earlier bracing prototype: [T01 reinforced branch and cleat test](output/full_paper_gate/sliced/T01_BRANCH/T01_BRANCH_A1Mini_PETG.3mf), followed by the reusable full-width X-braced bay described in the guide. The old [24 × 8 inch demonstrator](output/full_width_demo/index.html) is archived at `bb96e74`; its DEMO_EDGE has a weak cross-socket neck and is superseded.

Latest study: [paper-roll face, picture-frame click joints, magnets and diagonal print stacks](output/paper_roll_study/index.html). Includes [Blender scenes](output/paper_roll_study/Paper_Roll_Joinery_Study.blend), [visual PDF](output/paper_roll_study/Paper_Roll_Study.pdf), [test instructions](output/paper_roll_study/STUDY_AND_TEST_GUIDE.md), and A1 Mini PETG fit plates. Four 2090.4 × 609.6 mm paper strips; one PVC backing frame. Full-gate members are schematic; exported parts are experimental interfaces and manufacturing samples.

Assembly instructions: [two-part PDF — nine-piece prototype and full gate](output/a1_full_size/Assembly_and_Test_Instructions.pdf).

Committed whole-sheet baseline (`732f592`): [full-size whole-posterboard gate for the A1 Mini](output/a1_full_size/index.html), with [Blender assembly](output/a1_full_size/A1_Full_Size_Gate.blend), [19-type / 740-piece BOM](output/a1_full_size/BOM.csv), and a [1:1 interface fit kit](output/a1_full_size/sliced/Fit_Kit_1to1_LAYOUT/Fit_Kit_1to1_LAYOUT_A1Mini_PETG.3mf). Channels are standardized to just two types (120 long, 96 short). Every unique part fits 180 mm cubed and slices without supports. About 2.97 kg PETG per gate, plus 856 ties: substantial workshop labor. Physical validation remains outstanding. Read the [build guide](output/a1_full_size/BUILD_AND_PRINT_GUIDE.md).

The [earlier rigid concept and 1:15 tabletop model](output/rigid_whole_sheet/index.html) remain available. The material estimate and full-size printable geometry in the new iteration supersede that concept.

## Earlier Coroplast design

Open [the visual index](output/START_HERE.html) or [the Blender model](output/FPV_Gate_2700.blend).

Current design: four symmetric six-sided face panels, four 150 mm square corners, one shallow PVC backing frame with four corner braces, printed joints at both ends of each corner brace, and grass/hard-surface base configurations. A shared corner sheet yields 128 squares for 32 gates.

- [Build guide and assumptions](output/BUILD_GUIDE.md)
- [Assembly view PDF](output/Assembly_Views.pdf)
- [Material list](output/BOM.csv)
- [Hard-surface add-on](output/HARD_SURFACE_ADD_ON.csv)
- [PVC cutting list](output/PVC_CUT_LIST.csv)
- [Printable STLs](output/printable/)
- [Sheet and attachment templates](output/cut-layouts/)

Prototype: digital geometry checked; physical fit and wind/base performance require validation before use. See the guide.

Regenerate locally:

```sh
blender -b -t 8 --python scripts/build_gate.py
python3 scripts/validate_layout.py
python3 scripts/package_deliverables.py
```

The package script needs Pillow. Blender geometry uses metres; displayed dimensions and exported STLs use millimetres. To render only specific views, set `RENDER_SCENES` to comma-separated Blender scene names.

Earlier versions are archived under `output/previous_rectangular_design/` and `output/previous_double_frame_design/`. User-supplied screenshots and `WIP-design.md` remain unchanged.

Previous single-frame design: commit `55f2808`. Current iteration: `iteration/symmetric-square-corners`. Three cutting/marking jigs fit the Bambu A1 Mini; see Blender scene `10_CUTTING_JIGS` and the guide.

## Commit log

2026-09-17 Save single-frame FPV gate with printed corner-brace joints
    [BOM.csv, FPV_Gate_2700.blend, HARD_SURFACE_ADD_ON.csv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]
2026-09-17 Add symmetric gate panels, square corners and A1 Mini cutting jigs
    [BOM.csv, FPV_Gate_2700.blend, HARD_SURFACE_ADD_ON.csv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]
2026-09-17 Compare four folding posterboard gate concepts and printable fit samples
    [PVC_C_saddle_OD33p4_mm.stl, Posterboard_Gate_Options.blend, channel_150_on_spine_mm.stl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]
2026-09-18 Add A1 Mini whole-sheet gate parts, fit tests and assembly manual
    [A1_Full_Size_Gate.blend, BOM.csv, BORDER_BRIDGE.3mf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]
2026-09-18 Add paper-roll joinery study and printable full-width frame demo
    [00_FIT_CHECK.3mf, 00_FIT_CHECK_A1Mini_PETG.3mf, 01_CLICK_AND_MAGNET_JOINTS.3mf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]
2026-09-18 Add reinforced paper gate, integral PVC sleeves and first A1 Mini click test
    [BOM.csv, CLICK_KEY.stl, CROSS_PLATE.stl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]
2026-09-19 Record accepted PVC fit, tee gate parts and print workflow
    [BATCH_CORD_SADDLE.3mf, BATCH_CORD_SADDLE_A1Mini_PETG.3mf, BATCH_EDGE_SLEEVE.3mf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]
2026-09-19 Publish current PVC gate design with renders, print queues and actual material costs
    [BATCH_MAG_SLEEVE.3mf, BATCH_MAG_SLEEVE_A1Mini_PETG.3mf, CROSS.stl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]
2026-09-19 Add compact gate sizes, drone clearance previews and PVC cut guides
    [Clearance_Comparison.csv, Comparison.csv, OPEN_1000_PAPER_12_Magnet_Positions.csv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]
2026-10-08 Preserve short PVC marking gauge and experimental cross print stack
